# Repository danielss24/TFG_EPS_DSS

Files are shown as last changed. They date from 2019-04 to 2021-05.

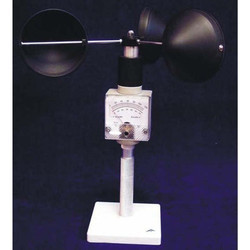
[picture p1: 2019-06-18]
Memoria/referencias anemometros/Cup Anemometer, कप एनीमोमीटर, कप एनेमोमीटर - Electro Mechanical Enterprises, Noida _ ID_ 12493118573_files/cup-anemometer-250x250.jpg

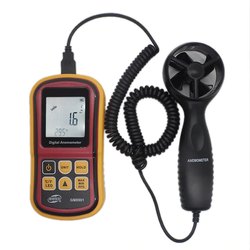
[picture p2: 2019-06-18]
Memoria/referencias anemometros/Cup Anemometer, कप एनीमोमीटर, कप एनेमोमीटर - Electro Mechanical Enterprises, Noida _ ID_ 12493118573_files/wind-measuring-instruments-250x250.jpg

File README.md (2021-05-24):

# TFG_EPS_DSS

Author: Daniel Serena Sanz

<p align="center">
  
</p>

## Resumen

Los procesos de intercambio de gases entre la tierra y la atmósfera determinan una parte importante del clima, por lo tanto es fundamental poder obtener datos fiables sobre su comportamiento y entender los mecanimos que lo determinan. Entre los diferentes factores que afectan al comportamiento de
los gases se pueden encontrar, la temperatura, la humedad, la presión y el viento. Las concentraciones
y flujos de gases fluctuan por la atmósfera debido al viento, es por esto que es importante realizar un
estudio de este parámetro.
En este trabajo de final de grado se detalla el proceso de diseño, desarrollo y construcción de
un dron como plataforma móvil para la instalación de un sensor de viento. Además, este sistema es
capaz de acoplar otros sistemas de sensorización miniaturizados, de esta manera, el dron puede incluir
sensores de viento, sensores de medición de gases, de temperatura, de presión y de humedad. La
plataforma móvil construida para esta unificación es un cuadrotor, dron con 4 motores. Se ha realizado
un estudio técnico de cada componente de forma individual para obtener un sistema optimizado en
términos de capacidad de carga útil y tiempo de vuelo. Además, ha sido necesario diseñar y producir
una serie de piezas con un programa de diseño asistido por ordenador 3D y una impresora 3D para
así acoplar los sistemas de medición necesarios y convertir finalmente el dron en un sensor. Por otro
lado para la gestión y obtención de los datos a de los sensores instalados, se ha tenido que diseñar
y codificar un software específico en python. También se ha desarrollado un algoritmo que es capaz
de obtener y analizar los parámetros de los motores convirtiendo de esta forma el dron en un sensor.
Finalmente, el sensor de viento diseñado se ha implementado en base a una unidad de medición
inercial, registrando inclinación, aceleración y orientación del sistema donde se ha instalado.
Después de construir e implementar los diferentes sistemas de administración y establecer la recopilación de datos, el sistema se probó en una prueba de campo y los resultados obtenidos muestran
un buen funcionamiento. Por medio de la representación de los datos tomados, se observa y procesa
la dirección y la velocidad del viento.

## Abstract

The gas exchange processes between the earth and the atmosphere determine an important part
of the climate. Therefore, it is essential to obtain reliable data on their behavior in order to understand
the mechanisms that determine it. Among the different factors that affect the behavior of gases are
temperature, humidity, pressure, and wind. Gas concentrations and fluxes vary in the atmosphere due
to the wind, which is why it is important to determine this parameter.
This final degree project deals with the design, development and construction of a drone as a mobile
platform for the installation of a wind sensor. Additionally the system is able to couple other miniaturized,
digitized sensors. This way the drone system can include wind sensors, gas sensors, temperature,
pressure and humidity sensors. The mobile platform for this assembling is a quadcopter, i.e. a drone
with 4 motors. A technical study of each drone component has been carried to obtain an optimized
system in terms of payload and flight time. On top of that it has been necessary to design and produce
a series of pieces using a 3D computer assistance design program and a 3D printer. In order to obtain
and to manage the data of the various sensors, it has been necessary to design and codify a specific
software in python. Furthermore, an algorithm has been developed to read-out and analyze the motor´s
operational parameters to convert the drone itself into a wind sensor. Finally, a designed wind sensor
has been implemented based on an inertial measurement unit, registering inclination, acceleration and
orientation of the system where it is installed.
After building and implementing the different management systems and establishing data collection,
the system has been tested in a field trial and the obtained results show good performance. By means
of the representation of the taken data the direction and the speed that the wind can be is observed
and processed further.

## Reusable code

Any code of this repository can be reused with the condition of indicate my name and repository on your headers.

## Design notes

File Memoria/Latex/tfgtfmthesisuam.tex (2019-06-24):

% arara: clean: {files: [tfgtfmthesisuam.aux, tfgtfmthesisuam.idx, tfgtfmthesisuam.ilg, tfgtfmthesisuam.ind, tfgtfmthesisuam.bbl, tfgtfmthesisuam.bcf, tfgtfmthesisuam.blg, tfgtfmthesisuam.run.xml, tfgtfmthesisuam.fdb_latexmk, tfgtfmthesisuam.fls, tfgtfmthesisuam.loe, tfgtfmthesisuam.lof, tfgtfmthesisuam.lol, tfgtfmthesisuam.lot, tfgtfmthesisuam.ltb, tfgtfmthesisuam.out, tfgtfmthesisuam.toc, tfgtfmthesisuam.upa, tfgtfmthesisuam.upb, tfgtfmthesisuam.acn, tfgtfmthesisuam.acr, tfgtfmthesisuam.alg, tfgtfmthesisuam.glg, tfgtfmthesisuam.glo, tfgtfmthesisuam.gls, tfgtfmthesisuam.glsdefs, tfgtfmthesisuam.idx,  tfgtfmthesisuam.ilg, tfgtfmthesisuam.xdy, tfgtfmthesisuam.loa, tfgtfmthesisuam.gnuploterrors , tfgtfmthesisuam.mw, tfgtfmthesisuam.fdb_latexmk ]}
% arara: pdflatex: {shell: yes}
% arara: makeglossaries
% arara: makeindex: {style: tfgtfmthesisuam.ist }
% !arara: bibtex
% arara: pdflatex: {shell: yes}
% arara: pdflatex: {shell: yes}
% arara: clean: {files: [tfgtfmthesisuam.aux, tfgtfmthesisuam.idx, tfgtfmthesisuam.ilg, tfgtfmthesisuam.ind, tfgtfmthesisuam.bbl, tfgtfmthesisuam.bcf, tfgtfmthesisuam.blg, tfgtfmthesisuam.run.xml, tfgtfmthesisuam.fdb_latexmk, tfgtfmthesisuam.fls, tfgtfmthesisuam.loe, tfgtfmthesisuam.lof, tfgtfmthesisuam.lol, tfgtfmthesisuam.lot, tfgtfmthesisuam.ltb, tfgtfmthesisuam.out, tfgtfmthesisuam.toc, tfgtfmthesisuam.upa, tfgtfmthesisuam.upb, tfgtfmthesisuam.acn, tfgtfmthesisuam.acr, tfgtfmthesisuam.alg, tfgtfmthesisuam.glg, tfgtfmthesisuam.glo, tfgtfmthesisuam.gls, tfgtfmthesisuam.glsdefs, tfgtfmthesisuam.idx,  tfgtfmthesisuam.ilg, tfgtfmthesisuam.xdy, tfgtfmthesisuam.loa, tfgtfmthesisuam.gnuploterrors , tfgtfmthesisuam.mw, tfgtfmthesisuam.fdb_latexmk ]}

\documentclass[epsbased,lof,loe,loc,copyright,final,printable,extendedindex,firstnumbered,tfg,gnuplot]{tfgtfmthesisuam}
% para moodle quitar printable

\usepackage{amsfonts}
\usepackage{float}
\makeglossaries

\advisor{Stefan Palzer}
\levelin{Ingeniería Informática}
\title{Diseño y construcción de un dron como plataforma de monitorización medioambiental}
%\subtitle{Si hace falta subtítulo}
\author{Daniel Serena Sanz}
\copyrightdate{20 de Junio de 2019}

\dedication{A mi familia y a mis compañeros.}

\ackfile{inicio/agradecimientos}
\resumenfile{inicio/resumen}
\abstractfile{inicio/abstract}

\keywords{Drone, quadrotor, fly, gas, platform, protocol, sensor, sensorization, system, unification, wind}
\palabrasclave{Cuadrotor, dron, gas/es, plataforma, protocolo, sensor, sensorización, sistema, unificación, viento, vuelo}

\coverdata
{
  Escuela Politécnica Superior \\
  Universidad Autónoma de Madrid \\
  C\textbackslash Francisco Tomás y Valiente nº 11
}

\bibliographyconfig{tfgtfmthesisuam}
\datadir{data}
\graphicsdir{img}
\logosdir{img}
\codesdir{codes}

\begin{document}

\chapter{Introducción\label{CAP:INTRODUCCION}}{inicio/introduccion}
\chapter{Estado del arte\label{CAP:ESTADODELARTE}}{inicio/estadodelarte}
\chapter{Sistema\label{CAP:SISTEMA}}{estructura/sistema.tex}

	\section{Dron\label{SEC:DRON}}{estructura/sistema/dron.tex}
		\subsection{Sistema de propulsión\label{SS:SISTPROPULSION}}{estructura/sistema/dron/sistemapropulsion}
		\subsection{Sistema de control\label{SS:SISTCONTROL}}{estructura/sistema/dron/sistemacontrol}
		\subsection{Mecánica\label{SS:MECANICA}}{estructura/sistema/dron/mecanica}
		
	\section{Implementación de sensores comerciales\label{SEC:SENSORVIENTO}}{estructura/sistema/sensorviento}
	
	\section{Desarrollo de sensor de viento propio\label{SEC:SENSORVIENTODRON}}{estructura/sistema/sensorvientodron}

\chapter{Pruebas y resultados\label{CAP:RESEXPYDISC}}{estructura/resultadosydiscusion}

\chapter{Conclusión\label{CAP:CONCLUSION}}{estructura/conclusion}

\appendix

\chapter{Estudio técnico de componentes para dron\label{CAP:ESTUDIOTECDRON}}{varios/estudioDron}

\chapter{Código diseñado para placa controladora}{varios/codigoPlacaContr}

\chapter{Código de registro del viento}{varios/codigoWindRegister}

\chapter{Código de gráfica de viento brújula}{varios/codigoPlotWind0}
\chapter{Código de gráfica de viento mapa de calor}{varios/codigoPlotWind1}
\chapter{Código de gráfica de viento 2D}{varios/codigoPlotWind2}
\chapter{Código de gráfica de viento 3D}{varios/codigoPlotWind3}

\end{document}

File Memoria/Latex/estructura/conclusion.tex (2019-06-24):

Para realizar el estudio de los gases que componen la atmósfera hay que tener en cuenta su comportamiento como por ejemplo, de dónde vienen y hacia dónde van. Los gases se desplazan por dos causas distintas: por difusión y por conducción, el método de difusión consiste en el desplazamiento de los gases, generalmente, en un entorno cerrado mediante el equilibrio de sus presiones parciales. Por otro lado la conducción de gases consiste en el desplazamiento de un gas por efecto de otro gas de presión menor, como por ejemplo el viento. Para medir el viento se utilizan sistemas como la veleta potenciométrica\cite{Mur2012} para medir la velocidad y dirección del viento, pudiendo diferenciar diferentes métodos de medición de velocidad de viento como: estándar o de copas, filamento caliente, empuje, compresióno tubo de Pitot, multisondas, láser, esférico y ultrasónico, descritos en el capítulo \ref{CAP:ESTADODELARTE}. No obstante, con los avances tecnológicos desarrollados en los últimos años, se pueden utilizar sensores más modernos  como las IMU, sensores que registra la orientación, inclinación y aceleración; minimizando así el tamaño del sistema y pudiendo instalarlos en una plataforma portátil.

Una vez analizados todos los diferentes sistemas de medición de viento, se ha utilizado una IMU, en este caso formada por el sensor MPU9250, que contiene a su vez el sensor MPU6050 y el AK8963, el sensor MPU6050 se encarga de la inclinación y orientación mientras que el AK8963 solo de la orientación. Se ha diseñado y codificado un software en python3 para la obtención y gestión de datos, así como para su representación de datos de forma adecuada en las gráficas del capítulo \ref{CAP:RESEXPYDISC}. Se ha instalado el sensor de viento descrito en un cuadrotor, dron de 4 motores, permitiendo así la toma de datos de forma sencilla en diferentes puntos. Para poder instalar la sensorización en el dron se ha tenido que diseñar e imprimir una serie de piezas 3D, ilustradas en la figura \ref{FIG:ACOPLDRONRASPI} (b), permitiendo de esta forma instalar tanto el sensor de viento diseñado como otros posibles tipos de sensorización, como sistemas de medición de temperatura, humedad, presión en incluso una estación meteorológica. Los datos obtenidos mediante el sensor de viento creado son bastante satisfactorios, se puede observar la desviación que produce en viento en el cuadrotor mediante las figuras: \ref{FIG:3axisforces}, \ref{FIG:scatterFit}, \ref{FIG:MAPACALOR}(a),\ref{FIG:MAPACALOR}(b), \ref{FIG:PLANOSMEDIDAS}(a), \ref{FIG:PLANOSMEDIDAS}(b) y \ref{FIG:mapa3d}.

Para proseguir con este trabajo se puede partir por desarrollar un sistema de viento más completo utilizando sensores más sofisticados o precisos como un anemómetro láser doppler o alguno de los descritos en el capítulo \ref{CAP:ESTADODELARTE}. Por otra parte, la plataforma donde se ha instalado el sensor de viento desarrollado, un cuadrotor, se puede modificar instalando otros componentes o se puede llevar a cabo una reestructuración utilizando un dron de ala fija para maximizar de esta forma el tiempo de vuelo pero sacrificando la versatilidad que ofrece un dron de ala rotatoria. Otro campo que puede implementarse es el desarrollo de un sistema de conducción autónomo agilizando la toma de datos.

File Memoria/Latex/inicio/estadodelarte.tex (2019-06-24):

\newdefinition{alaFija}{Dron de ala fija }{Dron de ala fija, se define como dron de ala fija aquel que cuenta con una o varias alas fijas en su parte superior, dotándole así de la capacidad de planear.}{Dron de ala fija, se define como dron de ala fija aquel que cuenta con una o varias alas fijas en su parte superior, dotándole así de la capacidad de planear}
\newdefinition{alaRotatoria}{Dron de ala rotatoria}{Dron de ala rotatoria, se define como dron de ala rotatoria aquel que mediante el movimiento de una o varias alas sobre un eje fijo permite volar el objeto.}{Dron de ala rotatoria, se define como dron de ala rotatoria aquel que mediante el movimiento de una o varias alas sobre un eje fijo permite volar el objeto}

Este trabajo consiste en la elaboración de una plataforma móvil sobre la que instalar un sistema de medición de viento y sobre la que se puedan unificar otros sistemas de sensorización necesarios para el estudio de la atmósfera.

Para llevar a cabo un estudio satisfactorio sobre el intercambio de gases entre la tierra y la atmósfera, se tiene que tener en cuenta como se mueven o dispersan, por conducción o por difusión respectivamente. El método de difusión consiste en la mezcla gradual de dos gases en un solo entorno, principalmente el gas con mayor presión es el que se disuelve en el segundo, equilibrando de esta forma la presión de ambos gases; por otro lado tenemos el método de conducción de gases que consiste en aplicar una fuerza de desplazamiento mediante otro gas, vease como ejemplo el accionamiento de un spray a presión. Basándonse en este último método, se debería realizar un estudio del viento en paralelo con el estudio de los gases para conocer de esta forma de dónde vienen y adónde van. 

Hay muchos estudios sobre el análisis del viento y formas de medirlo, para medir el viento contamos con dos componentes básicos: velocidad y dirección; la dirección se mide mediante el uso de una veleta\cite{Noble2019}\cite{Mur2012}, ésta es una superficie plana colocada en un eje, distribuyendo de forma equitativa su peso y permitiendo que gire libremente, la superficie plana no es igual en la parte delantera y trasera, siendo esta última de mayor tamaño y provocando que la parte pequeña o delantera indique hacia la dirección del viento, por otro lado, la velociad se mide con un anemómetro\cite{Mur2012}, podemos encontrar diferentes tipos de anemómetros como: estándar o de copas, filamento caliente, empuje, compresión o tubo de Pitot, multisondas, láser, esférico y ultrasónico.

Un anemómetro estándar o de copas\cite{cupAnemo}, ilustrado en la figura \ref{FIG:ANEMOMETROS} (a), precisa de una calibración previa para obtener unos datos fiables, su rotación se va registrando mediante un contador y mediante una conversión se obtiene la velocidad del viento por tantas vueltas dadas; por otro lado el anemómetro de filamento caliente\cite{hotWireInfoWeb}\cite{hotWireAnem}, ilustrado en la figura \ref{FIG:ANEMOMETROS} (g), funciona mediante la elevación de la temperatura de un hilo de platino o níquel. El movimiento del aire o viento produce que dicho hilo reduzca su temperatura variando a su vez la corriente que pasa por él, de esta forma obtenemos de forma proporcional la velocidad del viento. El anemómetro de empuje\cite{emujeAnem}, ilustrado en la figura \ref{FIG:ANEMOMETROS} (h), es muy poco preciso, su funcionamiento se limita a empujar un cubo hueco colgado a forma de péndulo, se mide la velocidad del viento en función de su suspensión respecto a su estado de reposo. A continuación existe el anemómetro de compresión o tubo de Pitot\cite{Extech}\cite{emujeAnem}, ilustrado en la figura \ref{FIG:ANEMOMETROS} (d), está formado por 2 tubos, uno de ellos con un orificio frontal y el segundo con un orificio lateral, la diferencia de presión medida entre ambos tubos indica la velocidad del viento. El anemómetro multisondas\cite{NASA}\cite{Anemometer2009}, ilustrado en la figura \ref{FIG:ANEMOMETROS} (b), utiliza el mismo principio que el anemómetro de compresión pero contando con 5 orificios y extendiendo el sistema de medición de viento a 3 dimensiones, este sistema es utilizado para aeromodelos como el UAV SUMO. El anemómetro esférico\cite{Holling2007}, ilustrado en la figura \ref{FIG:ANEMOMETROS} (c), utiliza una sistema con una esfera para incidir con un láser, la desviación que sufre el láser indica de forma proporcional la velocidad del viento. El anemómetro láser doppler\cite{Tropea1995}\cite{lasercantilver}\cite{durst1980principles}\cite{albrecht2013laser}, ilustrado en la figura \ref{FIG:ANEMOMETROS} (f), consta de dos haces de luz que inciden sobre una lente reflejante creando de esta forma una franja de medida conocida, cuando una partícula pasa por esta franja emitirá pulsos de luz, por otro lado un fotodiodo es capaz de captar dichos pulsos obteniendo de esta forma la velocidad de dicha partícula. Por último cabe mencionar el sensor ultrasónico\cite{Prudden2016}\cite{Mur2012}, ilustrado en la figura \ref{FIG:ANEMOMETROS} (e), este último tipo de anemómetro requiere de menos mantenimiento ya que no tiene piezas en movimiento, no obstante tiene un gran consumo eléctrico para su funcionamiento. Éste mide el tiempo requerido por el sonido para atravesar un campo conocido 10-30cm, estos anemómetros son muy precisos pero presentan problemas a la hora de medir el viento con lluvia.

\begin{figure}[Tipos de anemómetros]{FIG:ANEMOMETROS}{Tipos de anemómetros. Ordenados segun figura: estándar o de copas, multisondas, esférico, filamento caliente, ultrasónico, láser doppler, compresión o tubo de Pitot y empuje}
	\image{0.8\textwidth}{}{tiposanemometros}
\end{figure}

A todos estos tipos de anemómetros se pueden añadir los sensores como las IMU, unidad de medición inercial. Estos sensores registran la aceleración, la inclinación y la orientación del sistema donde esten instalados, mediante el desarrollo de un software específico, este sensor es capaz de aportar la fuerza del viento y su dirección, en funcion de la fuerza que se aplique al sistema y su orientación respectivamente. La ventaja de la utilización de estos sensores se encuentra en su precisión y su tamaño, pudiendolo instalar en sistemas miniaturizados.

Por otro lado, la plataforma donde se pretende unificar todo el sistema de sensorización es un cuadrotor o dron de 4 motores, estas máquinas se pueden definir como UAV (Unmaned Aerial Vehicle) o vehículo aéreo no tripulado. Su utilización hoy en día se ha incrementado por su versatilidad, facilidad, seguridad y rapidez; facilidad de alcance donde el ser humano no puede llegar de forma natural, seguridad evitando la presencia del ser humano en un entorno peligroso y rapidez de respuesta en determinadas ocasiones. Debido al gran interés por los drones\cite{hiltner2013drones}, se ha incrementado su diseño y contrucción ofreciendo diferentes modelos y componentes. Se pueden diferenciar dos grandes grupos: drones de ala fija\footnote{\dfnpl{alaFija}} y de ala rotatoria\footnote{\dfnpl{alaRotatoria}}. 

Los drones de ala fija destacan por su gran autonomía y su utilidad para el mapeo de superficies, no obstante no poseen de un tren de aterrizaje por lo que este tipo de dron precisa de una catapulta o persona que lo lance para poder despegar, se utiliza principalmente para labores de agricultura o fotogrametría\cite{Pozuelo2003}. Por otro lado existen los drones con ala rotatoria, estos drones son los más conocidos y más utilizados por su versatilidad al poder instalar complementos, ya sean cámaras o elementos de medición, y por su facilidad de pilotaje, sobre todo en el momento de despegar y aterrizar, ya que este modelo permite su despegue en vertical. Existen drones de ala rotatoria tricópteros, cuadrocópteros, hexacópteros u octacópteros, cada uno de ellos con 3, 4, 6 u 8 motores respectivamente. La autonomía de estos drones es muy limitada, teniendo 10 minutos a 1 hora aproximadamente frente a los drones de ala fija que fácilmente superan la hora de autonomía.

Hay numerosos estudios que emplean drones como sistema de medición, entre ellos se pueden encontrar los drones para medición de viento\cite{Prudden2016}\cite{hardin2011small}\cite{MoyanoCano2013}, cabe diferenciar varios modelos: SUMO, MMAV, MASC y Vario XLC; SUMO, Small Unmaned Meteorological Obsever\cite{Reuder2009}, es una plataforma diseñada por la Universidad de Berge, Noruega, que cuenta con un sistema de medición de temperatura, humedad y presión. Toma medidas del viento mediante el movimiento de sus hélices, junto con un sensor de GPS, mide la velocidad respecto de la tierra y determina a su vez la velocidad según el cabeceo del modelo, en caso de cabecear desde la parte frontal se ve acelerado y junto con la diferencia de velocidad respecto del suelo se obtiene la velocidad horizontal y su dirección. MMAV, Meteorological Mini Unmaned Vehicle\cite{BuschmannMarcoandBangeJensandVorsmann2019}, es un mini-dron diseñado por Mavionics GmbH en colaboración con la Universidad de Brunswick, Alemania. Este dron mide la velociadad del viento mediante el uso de un anemómetro de compresión con 5 orificios junto con un sistema de GPS y de medición inercial o IMU. MASC, Multi-purpose Automatic Sensor Carrier\cite{Wildmann2014}, es un dron de ala fija que opera automáticamente y toma medidas de flujo, calor y temperatura durante su vuelo a velocidad constante y con altura variable, cuenta con un sistema meteorológico similar al MMAV. Vario XLC\cite{Xiang2016}, es una plataforma basada en un helicóptero a escala reducida que es capaz de levantar un peso máximo de 17 Kg, en este caso lleva instalado un anemómetro ultrasónico 3D.

Una vez descritos los sistemas de medición de viento y su posibilidad de instalación en una plataforma móvil como es un dron, se puede  desarrollar un sistema acorde a las necesidades del proyecto miniaturizándose e instalándose en un cuadrotor.

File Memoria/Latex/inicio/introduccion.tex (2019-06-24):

\newacronym{o2}{O2}{Oxígeno}
\newacronym{n2}{N2}{Nitrógeno}
\newacronym{co2}{CO$_2$}{Dióxido de Carbono}
\newacronym{ar}{Ar}{Argón}
\newacronym{uv}{UV}{Ultra Violeta}
\newacronym{ozono}{O3}{Ozono}
\newacronym{gei}{GEI}{Gases de Efecto Invernadero}
\newacronym{ppm}{ppm}{Parts Per Million}
\newacronym{imu}{IMU}{Inercial Measure Unity}
\newacronym{cad}{CAD}{Computer Assisted Design}

Los niveles de concentración de \ac{co2} en la amtósfera han aumentado considerablemente en los últimos 20 años. Antes de la llegada de la industrialización, los niveles de CO$_2$ producidos y consumidos por la superficie terrestre y los océanos estaban compensados, sin embargo estos se han incrementado, llegando a unos niveles de presión de 410 \ac{ppm} respecto a los 280 ppm existentes antes de la industrialización\cite{Hansen1998}\cite{co2atmo}. Los niveles de emisión de CO$_2$ por la tierra superan enormemente al nivel emitido por los humanos. Para poder estudiar estas emisiones de gases hay que tener en cuenta qué factores afectan a su comportamiento, siendo los más significantes la humedad, la temperatura, la presión y el viento entre otros. Este último, además, es el principal motivo de su desplazamiento.

%\paragraph{Motivación}
Este TFG tiene como objetivo el desarrollo, diseño y utilización de una plataforma móvil que cuenta con un sistema de medición de viento y donde se pueda instalar un sistema de medición de gases miniaturizados. Favoreciendo, de esta forma, una toma rápida y fiable de datos. 

\begin{figure}[Medición de viento con drones]{FIG:INIFIG}{Medición de viento con drones. Sistema capaz de tomar datos en 3D y a tiempo real mediante la utilización de un dron como sensor de viento. (Iconos obtenidos de: svgsilh.com y www.shareicon.net)}
	\image{1\textwidth}{}{introImg}
\end{figure}

Se ha realizado un estudio  sobre los diferentes métodos de medición del viento y los posibles drones para usarlo como plataforma móvil donde instalar este sistema de medición funcional.

Existen diferentes métodos para medir el viento, el más común es la veleta potenciométrica, cuyo anemómetro puede ser esférico, de hilo térmico, ultrasónico o de tipo láser doppler entre otros. Por otro lado existen sensores \ac{imu}, que mediante el desarrollo de un software específico para el tratamiento de datos como: orientación, inclinación y aceleración, obtiene la velocidad y dirección del viento. Como plataforma móvil se ha estudiado la utilización de un dron teniendo en cuenta los dos grandes grupos existentes, ala fija y ala rotatoria. Los drones con ala fija presentan una mayor autonomía frente a los de ala rotatoria que por otro lado cuentan con mayor versatilidad.

%\paragraph{Objetivos}
El objetivo de este trabajo es la creación de un cuadrocoptero, dron con ala rotatoria, como plataforma móvil donde instalar un sistema de medición de viento. La aplicación de uso se muestra en la figura \ref{FIG:INIFIG}. Se ha decidido construir un dron por partes realizando un estudio ténico previo, indicado en el apéndice \ref{CAP:ESTUDIOTECDRON}, e instalar un sistema de viento aplicando una IMU para su medición. Para poder unificar los dos componentes, se han tenido que crear diferentes piezas 3D diseñadas en un programa \ac{cad}, permitiendo ,de esta forma, instalar cualquier otro sistema de sensorización miniaturizado en caso de ser necesario.

%\paragraph{Organización de la memoria}
Este trabajo está organizado en diferentes capítulos. En primer lugar, en el capítulo \ref{CAP:SISTEMA}, se explica el funcionamiento de los drones y sus componentes indispensables; continuando con la aplicación de los sensores comerciales actuales para la medición del viento y finalizando con el desarrollo de un sensor de viento propio unido a un dron. Se ha creado, por tanto, un sistema de medición de viento portátil. En el capítulo \ref{CAP:RESEXPYDISC} se muestran las diferentes pruebas realizadas en función de su escenario. Se puede observar el comportamiento del dron y de sus mediciones representándolos en unas gráficas como: un mapa de calor y un mapa de viento 2D y 3D. En el capítulo \ref{CAP:CONCLUSION} se resume la evolución de este trabajo sobre la utilización de drones como plataforma para un sistema de medición de viento como unidad básica del estudio de gases. En los anexos quedan reflejados el estudio técnico del dron desarrollado, el código diseñado e implementado para la toma y conversión de datos, y el algoritmo de gestión de estabilización.

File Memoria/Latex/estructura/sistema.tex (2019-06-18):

Una vez realizado el estudio de los diferentes tipos de sensores de viento y drones utilizados como sensor de viento descritos en el capítulo \ref{CAP:ESTADODELARTE}, se explicará cómo realizar el estudio del viento y cómo diseñar una plataforma sobre la que se puedan unificar distintos sistemas de medición. Se tratarán los drones y sus componentes, posteriormente se describirán los sistemas de viento y se implementará mediante una IMU, finalizando con un sistema portátil de medición del viento.

Debido al gran tamaño y coste de los drones industriales, se ha decidido diseñar uno propio más pequeño y barato y posteriomente añadiéndole las modificaciones oportunas para incorporar el sistema de sensorización necesario. El dron estará diseñado para la incorporación de un microsistema de medición de gases junto con un sensor de viento.

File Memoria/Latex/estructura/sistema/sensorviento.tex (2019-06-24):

 Actualmente los sensores de viento habituales cuentan con dos elementos básicos: el anemómetro y la veleta, el primero se encarga de medir la velocidad del viento y un tipo de anemómetro, hilo caliente, consiste en un hilo de platino que se calienta eléctricamente; la acción del viento produce la disminución de su temperatura variando así su resistencia y provocando que la corriente que atraviesa dicho hilo se altere y nos indique de forma proporcional la velociad del viento\cite{Tropea1995}, y el segundo elemento básico, la veleta, indica la dirección del viento; esta es una superficie plana colocada en un eje, distribuyendo de forma equitativa su peso y permitiendo que gire libremente, la superficie plana no es igual en la parte delantera y trasera, siendo esta última de mayor tamaño y  provocando que la parte pequeña o delantera indique hacia la dirección del viento\cite{Noble2019}. Estos dos elementos pueden encontrarse montados de forma separada o conjuntamente denominándose veleta potenciométrica\cite{Mur2012}.
 Este sistema de medición es muy preciso pero tiene un coste elevado. Necesita de una instalación en una localización fija, que además de precisar una altura mínima debe estar libre de obstáculos para poder realizar las medidas correctamente.
 
 %En nuestra vida diaria utilizamos desde dispositivos electrónicos hasta medios de transporte que incluyen sensores que miden su inclinación, aceleración y dirección, se puede ver como ejemplo un teléfono móvil, un coche o incluso un avión.
 Actualmente existen sensores que se utilizan en la estabilización de un avión, el registro del movimiento de un coche o incluso en aplicaciones móviles.
 
 En esta sección se explicará como utilizar un sensor de aceleración, giroscopio y magnetómetro.
 
 Para realizar este experimento se ha utilizado el sensor MPU9250\footnote{Datasheet: InvenSense, ``{MPU9250 Product Specification Revision 1.1},'' 2016. (Fecha de acceso: 2019-06-12)}, ilustrado en la figura \ref{FIG:IMUAXES}(a),que a su vez tiene integrado otros dos sensores el MPU6050, que se encarga de la aceleración y el giroscopio, y el AK8963 que gestiona el magnetómetro, componiendo de esta forma un microchip que mide la alteración de su posición en función de 3 ejes.
 
 Los datos obtenidos por el sensor MPU6050\footnote{Datasheet: InvenSense, ``{MPU6050 Product Specification Revision 3.3},'' 2012. (Fecha de acceso: 2019-06-12)} son datos sin tratar, que indican la aceleración en el instante de la medición y la inclinación respecto de la anterior medida tomada, mientras que el sensor AK8963\footnote{Datasheet: InvenSense, ``{MPU9250-AK8963 Product Specification Revision 1.1},'' 2016. (Fecha de acceso: 2019-06-12)} indica la orientación.

\begin{figure}[IMU con ejes de medición]{FIG:IMUAXES}{Sensor MPU9250 con ejes de funcionamiento. Figura \ref{FIG:IMUAXES} (a) muestra el sensor físico mientras que la figura \ref{FIG:IMUAXES} (b) muestra la diferencia entre los ejes de medición conjuntamente del giroscopio y acelerómetro y del magnetómetro, figura (c), muestra unos ejes distintos.}
	\image{1\textwidth}{}{IMUAXES}
\end{figure}
 
 Para poder saber claramente en que posición se encuentra el microchip con respecto a una superficie plana y no a su inclinación en relación a la anterior medida, se ha implementado el algoritmo de madgwick\cite{Act2012} que utiliza cuaterniones para indicar la inclinación absoluta en función de los ejes de la tierra. 
 
 Los cuaterniones\cite{Graves1999} son un conjunto de cuatro componentes complejos que sirven para la teoría de números, rotaciones en el espacio y para diseño de gráficos; en este caso se utilizarán para las rotaciones en el espacio. Los cuaterniones se pueden expresar como en la ecuación \ref{EQ:CuaternionFormula}.
 
\begin{equation}[EQ:CuaternionFormula]{Expresión de cuaterniones}
	{\mathbb{H}= \{ {a+bi+cj+dk:a,b,c,d\:\epsilon\:\mathbb{R}} \} \subset  \mathbb{C}^{2}}
	\end{equation}
	
	Fórmula de cuaternion \ref{EQ:CuaternionFormula} de 4 dimensiones. a, b, c, d son las componentes reales del cuaternion; i, j, k  son los componentes que multiplican cada una de las componentes reales.

   Mediante el algoritmo de madgwick, se convierten los datos obtenidos desde el giroscopio, acelerómetro y magnetómetro en un componente de 3 elementos, yaw, pitch y roll, proceso ilustrado en la figura \ref{FIG:YAWPITCHROLLPLANE}.
   Cada uno de estos elementos nos indica su rotación respecto a un eje del aeromodelo. 

\begin{figure}[Ejes yaw, pitch y roll]{FIG:YAWPITCHROLLPLANE}{Se recogen los datos del sensor MPU9250, magnetómetro, giroscopio y acelerómetro y los tratamos mediante el algoritmo de madgwick. Convierte las medidas y los convierte en los ejes de giro, yaw, pitch y roll.}
	\image{\textwidth}{}{yawpitchrollplane}
\end{figure}
 
 Mediante la utilización de estas rotaciones en función de sus ejes se puede determinar como hay que actuar en los motores para que se mantenga volando de forma estable y horizontal.

 En este punto se cuenta con la inclinación del sensor en base a los ejes de la tierra, su aceleración y su dirección en grados; con este conjunto de datos podemos calcular la variación de su posición en función de un punto inicial.
   
  Para calcular el viento se ha planteado un sistema que toma como eje el centro de la tierra; de esta forma si el sensor está orientado al norte y se inclina hacia delante se obtiene una dirección de viento de sur a norte, y en caso de inclinarse hacia delante y a izquierda, se obtiene un viento de sur-este. La fuerza del viento viene indicado directamente por los datos obtenidos del acelerómetro en función de los tres ejes.

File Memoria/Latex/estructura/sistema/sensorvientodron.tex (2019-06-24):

En esta sección se describirá la unificación el sensor de viento con el dron y qué es necesario para que todo funcione como un único sistema.
Para poder llevar a cabo esta unión se ha de tener en cuenta el peso del sistema de viento, la Raspberry y el sistema de sensorización, junto con el peso del dron para hacer una estimación media de la duración de vuelo.

A continuación se explicará los tres pasos que he llevado a cabo: en primer lugar desde donde empiezo, seguido de como junto todos los sistemas y finalizando con como funciona todo el conjunto.

%\paragraph{Uniendo sistemas}
%\begin{description}
%\item[Desde donde parto]
Para poder diseñar un sensor de viento que funcione con un dron primero hay que estudiar que sistema de estabilización usa el dron, se puede diferenciar entre dos sistemas principales. Un primer sistema realiza una estabilización del dron que registra la desviación de su posición desde un punto y lo corrige para mantenerse siempre en ese mismo punto. El segundo sistema de estabilización intenta que el dron no se caiga, modificando la potencia de los motores acorde con la fuerza que se ejerce sobre el, de esta forma consigue que el dron esté los más horizontal posible.

En este caso, se usa un placa comercial que funciona como el segundo sistema descrito y por tanto se usa un giroscopio para poder medir las diferentes inclinaciones y fuerzas que sufre el dron. En el caso de utilizar el primer sistema se debería usar una medición de la potencia suministrada a los motores para ver que potencia se esta ejerciendo para contrarrestar la fuerza que se ejerce sobre él.

Por otro lado se cuenta con un chasis base de un dron de 220 mm entre ejes donde es necesario montar un soporte para instalar nuestro ordenador o unidad de procesamiento, en este caso una Raspberry Pi 3 B+, y nuestro sistema de sensorización.

%\item[Como lo junto]
Para poder unir los dos sistemas y realizar medidas en vuelo, se ha tenido que aprender a utilizar un software específico para diseñar una serie de piezas 3D y así poder acoplar la sensorización al dron.

\begin{figure}[Antes y después de adapatacion raspberry-dron]{FIG:ACOPLDRONRASPI}{En la subfigura a) se puede observar los sistemas de forma independiente a unificar. En la subfigura b) se presentan las piezas diseñadas e impresas en 3D para poder acoplar sistemas de medición al dron. En la subfigura c) se observa el sistema de medición instalado en el dron construido.}
	\image{15cm}{}{acoplamientosDron}
\end{figure}

Entre las piezas de impresión se cuenta con:
\begin{description}
\item[Soporte Raspberry Pi]
Para el soporte de la Raspberry Pi 3 B+, se ha diseñado una pieza que se acopla en la parte inferior del chasis del dron. 

%\begin{figure}[Chasis raspberry dron]{FIG:CHASISRASPIDRON}{Soporte Raspberry dron.}
%	\image{4cm}{}{ChasisRaspberryDron}
%\end{figure}

\item[Zona de sensorización: ]

Una vez instalado el soporte de la Raspberry, se ha diseñado una tapa intermedia donde se puede instalar el sistema de sensorización necesario. 
Esta zona esta diseñada con suficiente espacio para poder instalar además del sensor base diseñado, sensor de viento, otros sensores como por ejemplo un sensor de gas con sus componentes necesarios.

%\begin{figure}[Zona sensorización dron]{FIG:ZONASENSORIZACION}{Zona de sensorización. Tapa intermedia \ref{SBFIG:TAPAINTERMEDIA} acoplada al soporte de la raspberry \ref{FIG:CHASISRASPIDRON} y a ella se ancla la tapa \ref{SBFIG:TAPACHASISDRON} para cerrar nuestro modelo.}
%	
%  \subfigure[SBFIG:TAPAINTERMEDIA]{Tapa intermedia dron}{\image{4cm}{}{TapaIntermediaDron}} \quad
%  \subfigure[SBFIG:TAPACHASISDRON]{Tapa chasis dron}{\image{4cm}{}{TapaChasisDron2}}
%  
%\end{figure} 

Al diseñar las piezas de forma independiente se puede modificar, en caso de necesidad, la tapa del chasis del dron y crear otra forma o ampliar el espacio respetando el acoplamiento a la tapa intermedia.

\item[Elementos de aterrizaje]

Una vez instaladas las anteriores piezas, se ha prolongado el dron por su parte inferior un total de 6 cm y por ello es necesario instalar un tren de aterrizaje.

%\begin{figure}[Pata dron]{FIG:PATADRON}{Diseño de pata del dron del tren de aterrizaje.}
%	\image{4cm}{}{PataDron}
%\end{figure}
\end{description}

Para el tren de aterrizaje se ha probado a instalar un total de 4 patas, una por cada motor. Por problemas de estabilidad se eliminó una de ellas, distribuyendo 2 de las patas en los motores traseros y la tercera en la parte delantera-media del dron. Con 3 patas se asegura aterrizar el dron correctamente en una superficie plana.

%\item[Funcionando conjuntamente]

Una vez se ha unido todo como un solo sistema, dron y sensorización junto con la raspberry, se procederá a realizar las mediciones con el dron volando.

Para tomar las medidas correctamente con el dron se tiene que mantener volando, los datos se obtienen a partir de la variación de su posición en cuanto a inclinación que sufre por fuerzas como el viento.
Para la realización de esta prueba se cuenta con los cálculos de vuelo previamente hechos sobre un dron con un peso máximo de 900 gramos y con una batería de 3 celdas y 1500 mAh de capacidad. El único manejo que se debe hacer con el dron en el momento de medir es modificar su altura ya que no tiene un sistema automático de mantenimiento de distancia respecto del suelo.

%\begin{figure}[Foto del dron con sensorización de viento]{FIG:DRONCOMPLETOSENSO}{Dron con sistema de medición de viento incorporado. Consta de las piezas diseñadas e impresas con una impresora 3D para poder instalar sistemas de sensorización miniaturizados.}
%	\image{0.8\textwidth}{}{dronCompleto2}
%\end{figure}

%\end{description}

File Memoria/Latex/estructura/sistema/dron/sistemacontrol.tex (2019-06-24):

\newdefinition{i2c}{Comunicación I2C}{I2C, es un protocolo de comunicación que cuenta con 2 cables: uno de ellos (SCL) indica los pulsos de reloj y el otro (SDA) se encarga de transportar los datos. Al contar con un único cable de datos y ser capaz de comunicar dos o más dispositivo es necesario un maestro que se encargue de mediar la comunicación.}{I2C, es un protocolo de comunicación que cuenta con 2 cables: uno de ellos (SCL) indica los pulsos de reloj y el otro (SDA) se encarga de transportar los datos. Al contar con un único cable de datos y ser capaz de comunicar dos o más dispositivo es necesario un maestro que se encargue de mediar la comunicación\cite{Leens2009}}
\newdefinition{spi}{Comunicación SPI}{SPI, es un protocolo de comunicación usado habitualmente para la transferencia de datos entre equipos electrónicos. Formado por un total de 4 conexiones: CLK o reloj de sincronizaciñon, envío de datos, recepción de datos y un Enable que permite recibir datos en caso de estar activo o negarlos en caso de estar inactivo, de esta forma se puede utilizar el SPI para comunicarse con varios sensores utilizando multiplexación mediante el pin de enable\cite{Leens2009}.}{SPI, es un protocolo de comunicación usado habitualmente para la transferencia de datos entre equipos electrónicos. Formado por un total de 4 conexiones: CLK o reloj de sincronizaciñon, envío de datos, recepción de datos y un Enable que permite recibir datos en caso de estar activo o negarlos en caso de estar inactivo, de esta forma se puede utilizar el SPI para comunicarse con varios sensores utilizando multiplexación mediante el pin de enable\cite{Leens2009}}
\newdefinition{pSerie}{Comunicación Puerto Serie}{Puerto serie, es un protocolo de comunicación digital que aplica la serialización, conversión de los datos a nivel de byte a una serie de pulsos para que puedan ser enviados y recibidos, existen diferentes tipos: UART usado por la Raspberry, USART, EUART.}{Puerto serie, es un protocolo de comunicación digital que aplica la serialización, conversión de los datos a nivel de byte a una serie de pulsos para que puedan ser enviados y recibidos, existen diferentes tipos: UART usado por la Raspberry, USART, EUART}

\paragraph{Placa distribuidora de potencia}\label{SSS:PlacaDistribuidora}

\newacronym{pdb}{PDB}{Pluggable Database}
Un punto crucial de los componentes electrónicos es su alimentación, para favorecer la durabilidad y estabilidad del circuito o circuitos electrónicos se debe aislar el circuito de potencia del circuito lógico mediante elementos como los que contiene la \ac{pdb}: diodos, resistencias y transistores los cuales evitan picos de tensión.

%\begin{figure}[Placa distribuidora de potencia]{FIG:PDBDRON}{Placa distribuidora de potencia con conector XT60.}
%	\image{4cm}{}{pdbDron}
%\end{figure}

Esta placa, ilustrada en la figura 3.1 (6), está conectada a la batería mediante un conector, en este caso se cuenta con un conector XT60, el cual impide conectar cada polo con su opuesto debido a su forma, evitando así cortocircuitos y daños al sistema.
Por otro lado, la PDB distribuye la tensión necesaria al resto de los componentes, entre los que se destacan:

\begin{description}
        \item[ESC:] Hasta un total de 6 controladores de velocidad, en este caso son 4 ESC que funcionan con baterías de 2 a 4 celdas y por tanto de 6 a 16 voltios.
        \item [Circuito 5V:] Circuito de 5 voltios de tensión con un sistema de BEC para evitar picos y conseguir un circuito con alimentación continua y estable, con una corriente continua de 2 amperios y una corriente máxima de 2'5 amperios.
        \item [Circuito 12V:] Circuito de 12 voltios de tensión, con el mismo funcionamiento que el circuito a 5 voltios, con una corriente continua de 500 mA y máxima de 0'8 amperios.
\end{description}

\paragraph{Controlador de vuelo}
\label{SSS:Controlador de vuelo}
%\subsubsection*{Controlador de vuelo\label{SS:CONTROLADORVUELO}}{estructura/sistema/dron/controladorvuelo}

	La placa controladora de vuelo es la unidad de procesamiento del dron encargada de gestionar la señales provenientes del receptor, leer los parámetros de los diferentes sistemas de estabilización y su posterior modificación para proporcionar la potencia adecuada a cada motor.
\paragraph{Placa comercial}
\label{SSSS:Placa comercial}
	La elección de la controladora de vuelo viene determinada sólamente por el protocolo de comunicación que utilice, aunque a día de hoy la mayoría de controladoras cuentan con software reprogramable que se ajusta a los diferentes sistemas de comunicación, como los más conocidos iBUS o sBUS.
	
%	\begin{figure}[Controladora de dron]{FIG:CONTROLADORADRON}{Placa controladora mateksys.}
%	\image{4cm}{}{controladoraDron}
%\end{figure}

	En la controladora de vuelo, ilustrada en la figura 3.1 (7), se pueden conectar el sistema de comunicación, sistema de vídeo, controladores de velocidad de los motores, bocina de emergencia y la antena de comunicación de largo alcance.

%https://www.banggood.com/Matek-F405-OSD-BetaFlight-STM32F405-Flight-Controller-Built-in-OSD-Inverter-for-RC-Multirotor-FPV-Racing-Drone-p-1141282.html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

\paragraph{Placa desarrollada}
\label{SSSS:Placa desarrollada}
	\newacronym{tfg}{TFG}{Trabajo final de grado}
En este \ac{tfg} se ha reproducido el sistema de control del dron en una Raspberry Pi 3 B+\cite{raspberryPi}, con el fin de unificar todos los controles en un sólo punto y poder utilizar todas las señales entrantes y salientes para mediciones posteriores.

Para representar el sistema de la controladora de vuelo se ha partido del sistema de descifrado del protocolo de comunicación elegido, iBUS, este protocolo manda paquetes de información a través del puerto serie. La raspberry cuenta con dos pines de comunicación por puerto serie: Rx para recibir la información y Tx para transmitirla.
	
El paquete recibido tiene un tamaño total de 31 bytes, con un byte inicial estándar con contenido igual a 0x55, a continuación encontramos un total de 14 canales con 2 bytes por canal y un checksum al final con un tamaño de 1 byte. El paquete se transmite cada 7 ms con una tasa de baudios de 115200, es decir, un total de 115200 bits por segundo.
Para desglosar el paquete recibido, enviado por el mando, se ha tenido que codificar un algoritmo en python donde se diferencia y se convierte cada uno de los bytes a decimal, obteniendo de esta forma un valor de cada canal entre 1000 y 2000, siendo 1000 el valor mínimo y 2000 el máximo valor posible.

Para poder producir el PWM correcto y enviárselo a los controladores de velocidad, se ha escogido el chip PCA9685 que convierte de digital a PWM y tiene hasta un máximo de 8 canales. Ha sido necesario dicho chip ya que la raspberry no cuenta con el número suficiente de canales para controlar los 4 motores.
La Raspberry cuenta con 3 sistemas de comunicación: I2C\footnote{\dfnpl{i2c}}, SPI\footnote{\dfnpl{spi}} y puerto \footnote{\dfnpl{pSerie}}, para la configuración del chip PCA9685 se ha realizado mediante comunicación por I2C y su respectiva librería de adafruit obtenida por github\cite{Industries}. 

Se ha tenido que indicar desde la raspberry la frecuencia de salida de los PWM, 2000 Hz , y el ciclo de trabajo previamente obtenido por nuestro rango de entrada entre 1000 y 2000.
\paragraph{Funcionamiento de algoritmo codificado}
La Raspberry recibe el paquete de bytes y lo transforma mediante el algoritmo diseñado y codificado en valores entre 1000 y 2000 por cada canal. Por otro lado se usa la librería de Adafruit para el chip PCA9685, pasándole el rango calculado y configurando el PWM a generar a 2KHz de frecuencia.

%\begin{subequations}
%    \begin{equation}[EQ:PQTEntrante]{Paquete 31 bytes entrante}
%		\boxed{55,DD05,DC05,EB03,DC05,E803,D007,D205,D905,E803...}
%		%55 DD05 DC05 EB03 DC05 E803 D007 D205 D905 E803 E803 DC05 DC05 DC05 DC05 234C
%	\end{equation}
%	\begin{equation}[EQ:PQTDescifrado]{Señal descifrada}
%		\boxed{input=[1501,  1500,  1003,  1500,  1000,  2000,  1490,  1497,  1000,  1000,  1500,  1500,  1500,  1500]}
%	\end{equation}
%	\begin{equation}[EQ:EQRango]{Ecuación de obtención de rango}
%			\boxed{rango = 3296 - (input - 1000) * \frac{(3296-2498)}{1000}}
%	\end{equation}
%	\begin{equation}[EQ:EQFuncion]{Función de adafruit, generación de pwm en PCA9685}
%			\boxed{pwm.set_pwm(canal, rangoMinimo, 4095)}
%	\end{equation}
%\end{subequations}

\begin{figure}[Diagrama placa controladora desarrollada]{FIG:DIAGRAMAPLACACONTROLADOR}{Diagrama de placa controladora a alto y bajo nivel. El receptor recibe la señal del mando, que se transmite a la raspberry y que realiza la conversión necesaria para general el PWM correcto utilizando el chip PCA9685 a los 4 canales necesarios, uno para cada esc-motor.}
	\image{1\textwidth}{}{diagramaPlacaControladora2}
\end{figure}

En la figura \ref{FIG:DIAGRAMAPLACACONTROLADOR} se pueden observar dos imágenes, a y b, en la imágen b se muestra a alto nivel como funciona el sistema de gestión de la placa controladora diseñada, mientras que en la imágen a se muestra a bajo nivel el proceso y conversión de los datos desde el receptor hasta los PWM mandados a los motores.

Una vez conseguida la señal de salida PWM en función de la entrada del mando, se modifica la señal a partir de los datos obtenidos por el sensor MPU9250, el cual nos indica la inclinación y fuerzas que se ejercen sobre el dron; de esta forma se mandama la potencia adecuada a cada motor para conseguir un vuelo estable y horizontal. Posteriormente se realizó la estructura del programa para la obtención de la potencia de los motores para poder medir el viento a partir de ellos, convirtiendo de esta forma el dron en un propio sensor de viento, no obstante, debido a las dificultades de probar el sistema de estabilización y su ajuste, se decidió trabajar con la placa comercial.

\paragraph{Sistema de comunicación}

	El sistema de comunicación está compuesto por dos componentes, receptor y transmisor, 3.1 (1) y 3.1 (3), y se pueden elegir diferentes tipos teniendo en cuenta su protocolo de comunicación. 
	
	El sistema de comunicación tiene diferentes protocolos para transmitir la información, utiliza un protocolo entre emisor y receptor y otro distinto entre receptor y unidad de procesamiento o controladora de vuelo\cite{Eric2017}.
	
%	\begin{figure}[Mando FlySky dron]{FIG:MANDODRON}{Mando FlySky para dron.}
%	\image{4cm}{}{mandoDron}
%\end{figure}	
	
	El protocolo de comunicación entre emisor y receptor tiene que ser siempre igual, es por eso que la mayoría de mandos, emisores, incluyen un receptor estándar. En este caso se ha utilizado un pack FlySky emisor-receptor.
	
	\newacronym{ppm}{PPM}{Parts per million}
	En el caso del protocolo entre el receptor y la unidad de procesamiento podemos encontrar señales PWM, PPM, SBUS, iBus entre otras. La diferencia entre estos protocolos es la forma de estructurar el paquete de datos o la conexión que hay que realizar a nivel de hardware. Por su simplicidad y comodidad se ha utilizado el protocolo iBus que cuenta con un paquete de transmisión de 31 bytes.

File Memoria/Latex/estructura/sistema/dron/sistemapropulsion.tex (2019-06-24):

\paragraph{Motores}
\label{SSS:Motores}
%\subsubsection*{Motores\label{SS:MOTORES}}{estructura/sistema/dron/motores}

Los motores son una parte fundamental del dron ya que han de proporcionar la potencia suficiente para hacer girar la hélices y, por consiguiente, hacer volar el dron. 
                
 Se han considerado varios parámetros como por ejemplo, la potencia, el consumo y la fuerza máxima de empuje. 
 \newacronym{cw}{CW}{ClockWise}
 \newacronym{ccw}{CCW}{Counter ClockWise}
 Los motores se clasifican según su velocidad indicándose en KV, revoluciones por minuto por voltio y su dirección de giro, que se distingue entre \ac{cw} y \ac{ccw}. No es posible tener todos los motores con el mismo sentido de giro ya que se produciría un efecto de vórtice, es decir, haciendo girar el dron sobre si mismo y sin ningún control. \linebreak Así mismo se pueden diferenciar dos clases de motores: con escobillas o sin ellas, este factor afecta a la forma de cambio de giro de los motores. Los motores sin escobillas llevan un sistema de carga de polos magnéticos para realizar el cambio de dirección, mientras que los motores con escobillas hacen circular la corriente por unas bobinas generando un campo magnético y en consecuencia atrayendo o repeliendo el rotor en un sentido u otro; cabe destacar que es necesario un mínimo de 3 bobinas para hacer girar el rotor puesto que, si se tuvieran sólo dos podría provocar que el motor se quedase en perpendicular cuando se produjese el cambio de giro.

 Se han elegido unos motores sin escobillas por su rendimiento, menor desgaste y fiabilidad, como los ilustrados en la figura 3.1 (4). 
% 
% \begin{figure}[Motores dron]{FIG:MOTORESDRON}{Motores de dron, 2 CW y 2 CCW.}
%	\image{4cm}{}{motoresDron}
%\end{figure}
                
 \newacronym{kv}{KV}{Kilo Voltage}
 Estos motores constan de 2300 \ac{kv} y sin escobillas, contando así con 3 cables: alimentación, masa y potencia. La velocidad de los motores varía mediante la utilización de una señal PWM, modificando su ciclo de trabajo desde 1 milisegundo (ms) hasta 2 ms, estableciendo a 1'5 ms funcionaría a mitad de potencia y a 2 ms funcionaría al 100\%.
 
\newacronym{pwm}{PWM}{Pulse width modulation} 
 
 Un \acl{pwm} es la modulación de una señal digital provocando en sistemas con menos velocidad de lectura la llegada de una señal analógica. Un PWM con una salida de 3,3 V y con un ciclo de trabajo del 50\% produciría en el sistema receptor una señal analógica de 3,3 V/ 50 = 0,66 V de señal de entrada, reduciendo su potencia un 50\%.

%\subsubsection*{Controlador de velocidad\label{SS:ESC}}{estructura/sistema/dron/esc}
 
 \paragraph{Controlador de velocidad}
 \label{SSS:Controlador de velocidad}

 \newacronym{esc}{ESC}{Electronic Speed Controller}

 El controlador de velocidad \ac{esc}, es un controlador esencial que determina la potencia suministrada al motor variando su velocidad. Es necesario instalar uno por cada motor controlándolos así de forma independiente.
 Por un lado cuenta con 2 ó 3 cables dependiendo de si es un controlador de velocidad para un motor con escobillas o sin ellas, y por otro lado dispone de 4 cables: dos cables de alimentación conectados a la placa de distribución de potencia y otros 2 que reciben la potencia que ha de suministrar al motor.
 
% \begin{figure}[Controlador de velocidad]{FIG:ESCDRON}{Controladores de velocidad dron.}
%	\image{4cm}{}{escDron}
%\end{figure}
 
 Los ESC se deben elegir en función de la batería que vayas a utilizar, teniendo en cuenta el número de celdas y su ratio de descarga continua. Los controladores de velocidad comprados, 3.1 (2), cuentan con una capacidad de descarga de 35 amperios indicando la potencia que pueden generar los motores. 
 
 Los ESC pueden recibir la señal PWM que indica la potencia que debe suministrar al motor, a partir del controlador de vuelo o directamente desde el receptor del mando. Es aconsejable recibirla desde el controlador de vuelo, ya que de esta forma se gestiona la estabilización del dron, favoreciendo un control mucho más fácil del aeromodelo\cite{OscarSerrano}. 

%http://fpvmax.com/2016/12/21/variador-electronico-esc-funciona/
 
\paragraph{Hélices}
\label{SSS:Helices}
%\subsubsection*{Hélices\label{SS:HELICES}}{estructura/sistema/dron/helices}

 %http://fpvmax.com/2017/02/10/helices-drones-tipos-tamanos/
 Las hélices son un componente menos crítico a la hora de elegirlas y montarlas sobre el dron, existen diferentes formatos con las siguientes características:
 \begin{description}
        \item[Tamaño:] Pueden variar desde 2 a 19 pulgadas, el tamaño de las hélices se ve limitado por el tamaño de los brazos del chasis donde se monten. Hay que tener en cuenta que a mayor tamaño mayor superficie y por tanto más empuje. Hoy en día se utilizan con más frecuencia las hélices entre 4 y 6 pulgadas las cuales favorecen el funcionamiento de drones con motores rápidos como los utilizados en drones de carreras, no obstante también se utilizan las hélices con tamaño de 10 o más pulgadas para aeromodelos que no priorizan la velocidad, si no que necesiten mayor estabilidad y llevar cargas elevadas.
 		\item[Número de aspas:] Varía desde 2 a 6 aspas, el número de aspas afecta a la superficie de empuje, aumentando la fricción y por tanto la fuerza que ejerce para levantar el dron. En hélices con un  tamaño pequeño de hasta 6 pulgadas, podemos encontrar hasta un máximo de 6 aspas, mientras que en hélices de mayor tamaño, 10 pulgadas o superior, no solemos superar las 2 aspas.
 		\item[Forma:] La forma es un punto crítico de este componente, tienen una forma de pala corvada para conseguir el empuje del aire en el sentido contrario de giro del motor. La terminación del aspa también afecta al vuelo de un dron, se pueden diferenciar: acabadas en punta,  Bullnose e Híbridas bullnose, determinando mayor o menor empuje y en consecuencia mayor o menor consumo.

 \end{description}
 
% \begin{figure}[Tipos de hélices dron]{FIG:HELICESDRON}{Tipos de hélices según  la terminación de sus aspas.}
%  \subfigure[SBFIG:HelicePunta]{Hélice con terminación en punta.}{\image{4cm}{}{helicePunta}} \quad
%  \subfigure[SBFIG:HeliceBullnose]{Hélice con terminación tipo bullnose.}{\image{4cm}{}{heliceBullnose}} \quad
%  \subfigure[SBFIG:HeliceHBullnose]{Hélice con terminación tipo híbrida bullnose.}{\image{4cm}{}{heliceHBullnose}}
%\end{figure} 

 En el dron diseñado se ha priorizado su tamaño, ya que como se ha explicado anteriormente el tamaño de las hélices afecta a la fuerza de empuje vertical del dron para poder levantar su carga, puesto que  se cuenta con un dron con un peso de 660 gramos y con una carga añadida de 200 g máximo, se ha elegido unas hélices de 5 pulgadas con un total de 3 aspas, obteniendo así un punto óptimo entre empuje o fuerza máxima y duración de vuelo, como la hélice de la figura 3.1 (5).

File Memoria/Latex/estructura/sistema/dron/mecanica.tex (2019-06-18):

\paragraph{Chasis}
\label{SSS:Chasis}
%\subsubsection{Chasis\label{SS:CHASIS}}{estructura/sistema/dron/chasis}

	El chasis de un dron es la estructura donde se van a montar todos los componentes anteriormente descritos, contamos con diferentes características al comprar o fabricar el nuestro:
	
	\begin{description}
	\item[Número y longitud de brazos] El número de brazos determina el número de motores que podemos instalar en nuestro aeromodelo, hay chasis desde 4 hasta 8 brazos, siempre números pares.
	La longitud de los brazos nos ayuda a instalar unas hélices de mayor tamaño.
	\item[Distribución] La distribución de los brazos no es una característica muy importante sino más bien estética. En chasis con 4 brazos podemos encontrar distribuciones en H o en X.
%	\begin{figure}[Chasis dron en X y H]{FIG:CHASISX}{Diferencia entre formas de chasis en X \ref{SBFIG:CHASISX} y H \ref{SBFIG:CHASISH} en drones.}
%	
%  \subfigure[SBFIG:CHASISX]{Chasis drone en forma de X}{\image{4cm}{}{ChasisDroneX}} \quad
%  \subfigure[SBFIG:CHASISH]{Chasis drone en forma de H}{\image{4cm}{}{ChasisDroneH}}
%  
%\end{figure} 
	\item[Material]
	El material del chasis dispone al dron de resistencia ante roturas en caso de accidente, rigidez a la hora de ejercer fuerza sobre él y peso según la composición del material utilizado.
	Se ha utilizado un chasis de fibra de carbono por su equilibrio entre las características mencionadas destacando su leve peso.
	\end{description}
	
%	\begin{figure}[Chasis dron]{FIG:CHASISDRON}{Chasis dron.}
%	\image{4cm}{}{chasisDron}
%\end{figure}	
		
	El dron elegido cuenta con un chasis de 4 brazos en disposición X y con un tamaño entre ejes de 220 milímetros permitiéndome instalar unas hélices de hasta 5 pulgadas, este chasis de fibra de carbono pesa un total 127 gramos.

\paragraph{Batería}
\label{SSS:Bateria}
%\subsubsection{Batería\label{SS:BATERIA}}{estructura/sistema/dron/bateria}

 La batería para cualquier radiocontrol es indispensable ya que es el elemento que proporciona la electricidad para que todo funcione, por eso es fundamental calcular el gasto de nuestro sistema y escoger una batería que nos proporcione una durabilidad media elevada.
 Se distinguen diferentes características de las baterías como:
 
 \begin{description}
 \newacronym{nicd}{NiCd}{Niquel Cadmio}
 \newacronym{lion}{L-ion}{Ion Litio}
 \newacronym{lipo}{LiPo}{Polímero de Ion Litio}
 \item[Composición: ]  Existen diferentes tipos de baterías en función de su composición. Hay diferentes tipos como \acl{nicd}, \acl{lion}, \acl{lipo}.
 \item[Capacidad: ] A más capacidad de carga más duración de vuelo tiene pero a su vez mas peso, perjudicando este al tiempo de vuelo.
 \item[Número de celdas: ] A mayor número de celdas generalmente la batería cuenta con más capacidad y más potencia al estar conectadas en serie.
 \item[Tasa de descarga: ] La tasa de descarga indica la tasa máxima de descarga que ofrece la batería, a mayor tasa más potencia se puede trasmitir a los motores y por tanto mayor empuje. 
 \end{description}

Para el dron utilizado, se ha escogido una batería de 3 celdas de Polímero de Ion Litio (LiPo) con una capacidad de 1500 miliamperios (mAh) y con un peso de 107 gramos (g), 3.1 (8). 

%	\begin{figure}[Batería dron]{FIG:BATERIADRON}{Batería dron.}
%	\image{4cm}{}{bateriaDron}
%\end{figure}

La configuración de esta batería nos ayuda a tener una capacidad óptima en relación con el peso. 
Está compuesta por polímero de Ion Litio proporcionando una durabilidad de 300 a 500 horas (h) de uso sin necesidad de mantenimiento por parte del usuario. 
Dispone de 3 celdas en serie consiguiendo una mayor capacidad de almacenamiento y mayor tensión de salida para alimentar el dron.

%https://www.reichelt.de/akku-pack-li-polymer-11-1-v-1500-mah-25-50-c-rd-slp-1500-s3-p208376.html?&trstct=pos_9

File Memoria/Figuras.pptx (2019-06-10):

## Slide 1

Raspberry Pi 3 B+

ESC-Motor

ESC-Motor

ESC-Motor

ESC-Motor

Descifrado de señal

Procesamiento de señal y comunicación a PCA9685

PCA9685

Generación PWM

Receptor

Recibir señal mando

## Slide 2

Gimnasio

17 m

0

3

1

10 m

Puerta almacén

X m

4

X m

Puerta principal

2

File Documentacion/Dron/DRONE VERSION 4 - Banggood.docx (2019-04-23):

Chasis x 2

https://www.banggood.com/Dragon-HX5-X5-220mm-5-inch-FPV-Racing-Frame-Kit-RC-Drone-4mm-Arm-Carbon-Fiber-p-1254005.html?ID=531381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

Controlador de vuelo x 2

https://www.banggood.com/Matek-F405-OSD-BetaFlight-STM32F405-Flight-Controller-Built-in-OSD-Inverter-for-RC-Multirotor-FPV-Racing-Drone-p-1141282.html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

PDB x 2

https://www.banggood.com/Matek-Systems-PDB-XT60-W-BEC-5V-12V-2oz-Copper-For-RC-Multirotors-p-1049051.html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

Motores (2CW y 2 CCW) x2

https://www.banggood.com/4X-Racerstar-2205-BR2205-2300KV-2-4S-Brushless-Motor-2-CW-2-CCW-For-QAV250-ZMR250-260-Multirotor-p-1066837.html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

Helices x 3

https://www.banggood.com/10-Pairs-Kingkong-5x4_5x3-5045-5-Inch-3-Blade-Propeller-CW-CCW-for-FPV-Racer-p-1067877.html?ID=228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

Batería x 2

https://www.banggood.com/ZOP-Power-14_8V-5000mAh-4S-60C-Lipo-Battery-XT60-Plug-p-1170983.html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

Protectores Hélices x 3

https://www.banggood.com/Diatone-Glass-Fiber-Propeller-Protective-Guard-For-200-250-Quadcopter-p-947803.html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

ESC x 2

https://www.banggood.com/4-PCS-Racerstar-RS30A-Lite-30A-Blheli_S-BB1-2-4S-Brushless-ESC-for-FPV-Racer-p-1101000.html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

Emisora y receptor x 1

https://www.banggood.com/FlySky-FS-i6-2_4G-6CH-AFHDS-RC-Transmitter-With-FS-iA6B-Receiver-p-983537.html?ID=42481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

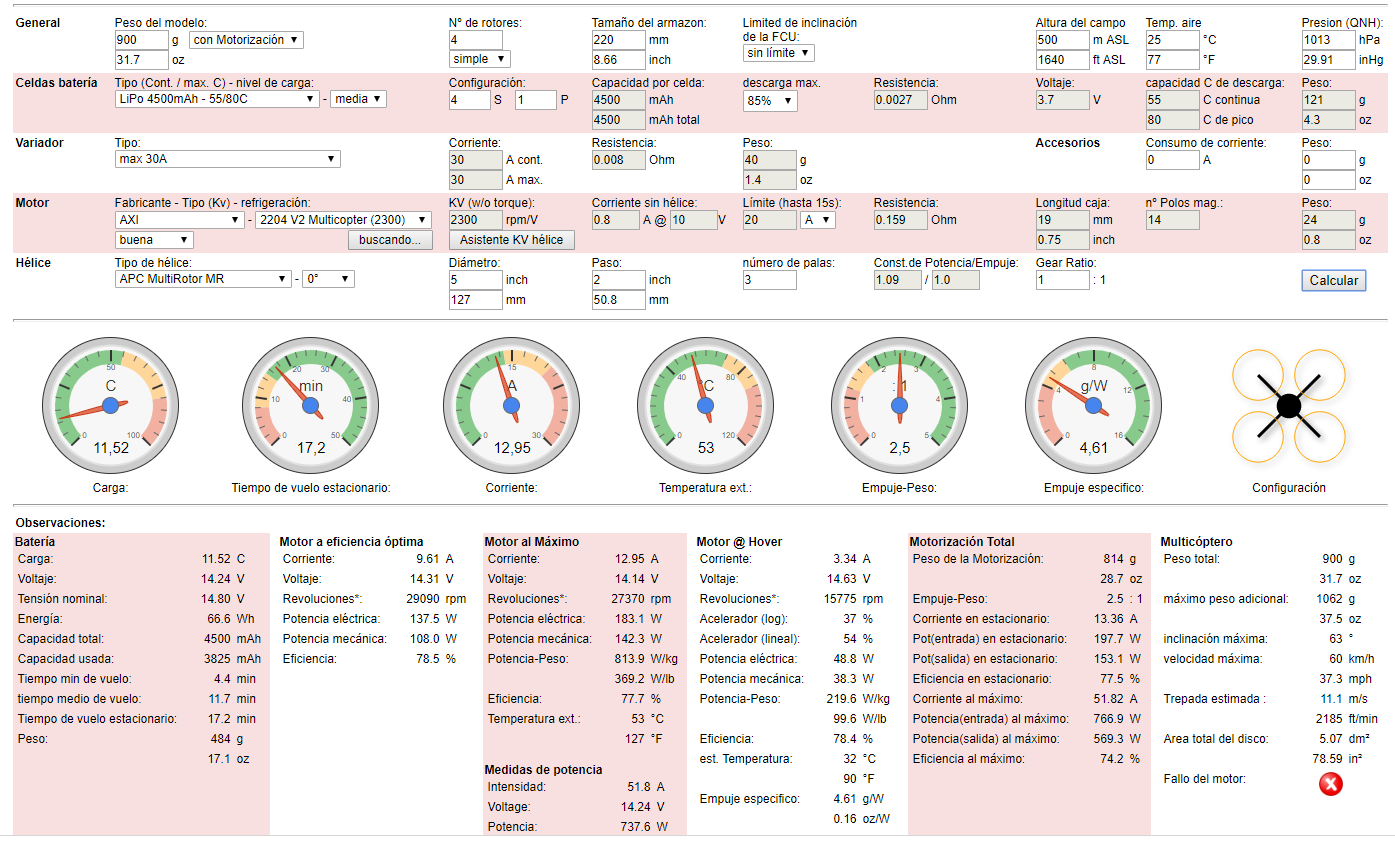
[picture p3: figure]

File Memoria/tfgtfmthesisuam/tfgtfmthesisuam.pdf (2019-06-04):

18
19

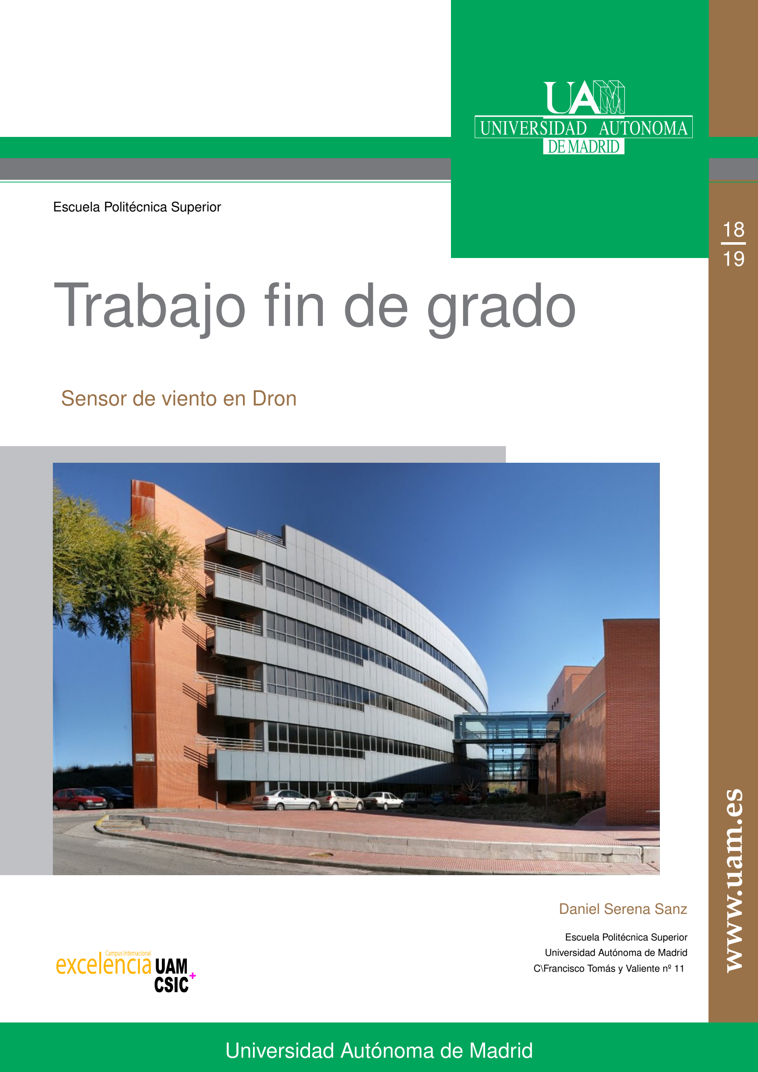
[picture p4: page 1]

# Trabajo fin de grado

Escuela Politécnica Superior

## Sensor de viento en Dron

## Universidad Autónoma de Madrid

# www.uam.es

Daniel Serena Sanz

Escuela Politécnica Superior

Universidad Autónoma de Madrid

C\Francisco Tomás y Valiente nº 11

## UNIVERSIDAD AUTÓNOMA DE MADRID

### ESCUELA POLITÉCNICA SUPERIOR

### Grado en Ingeniería de Textos

# TRABAJO FIN DE GRADO

## Sensor de viento en Dron

### Si hace falta subtítulo

### Autor: Daniel Serena Sanz Tutor: Daniel Serena Sanz

### junio 2019

Todos los derechos reservados.
Queda prohibida, salvo excepción prevista en la Ley, cualquier forma de reproducción, distribución comunicación pública
y transformación de esta obra sin contar con la autorización
de los titulares de la propiedad intelectual.
La infracción de los derechos mencionados puede ser constitutiva de delito contra la propiedad intelectual (arts. 270 y sgts. del Código Penal).

DERECHOS RESERVADOS
© 3 de Noviembre de 2017 por UNIVERSIDAD AUTÓNOMA DE MADRID Francisco Tomás y Valiente, no 1

Madrid, 28049
Spain

Daniel Serena Sanz

Sensor de viento en Dron

Daniel Serena Sanz
C\ Francisco Tomás y Valiente Nº 11

IMPRESO EN ESPAÑA PRINTED IN SPAIN

A mi mujer y a mis hijos

Lo peor es cuando has terminado un capítulo

y la máquina de escribir no aplaude.

Orson Welles

## Prefacio

Este estilo de LATEX 2ε ha sido diseñado con dos propósitos. El primer propósito es el de facilitar

en lo posible la escritura de trabajos de fin de grado y de máster y de tesis doctorales. En ese sentido

se han diseñado un conjunto de comandos que simplifican la escritura y diseño de estos trabajos

pero que reducen en cierta forma las capacidades de los paquetes de LATEX utilizados. Sin embargo,

dado que los paquetes están incluidos en esta clase, pueden utilizarse directamente y hacer diseños

más complejos pero si se hace esto se recomienda mantener una estética coherente con el resto del

documento.

El segundo de los propósitos es que estos documentos mantengan una estética uniforme en la

Universidad Autónoma de Madrid y fomentar una imagen corporativa en documentos tan relevantes

como los trabajos de fin de grado o de máster y las tesis doctorales. Por ese motivo se recomienda

mantener una coherencia estética en todo momento. El diseño facilita esa coherencia pero es posible

salirse del diseño si se mantine dicha coherencia.

Como creador de este estilo espero fervientemente que al usar este estilo te sientas cómodo y te

facilite la escritura de un documento que es muy relevante en esta etapa de tu vida. Para facilitártela

aún más, el código fuente de este documento también está disponible en tu ordenador o en overleaf

para que te sirva a modo de ejemplo.

Eloy Anguiano Rey

vii

## Agradecimientos

En primer lugar me gustaría agradecer a la Escuela Politécnica Superior por su apoyo para la

creación de esta clase y que sea el formato básico para la creación de tesis, trabajos fin de grado y

trabajos fin de master.

En particular quiero destacar el trabajo realizado por Fernando López-Colino por su apoyo en la

comisión de imagen institucional y por sus comentarios para mejorar este estilo.

También quiero tener un recuerdo para Carmen Navarrete Navarrete dado que este estilo comencé

a crearlo a partir de sus necesidades a la hora de escribir la tesis. Y por supuesto a no quiero olvi-

darme de mi esposa e hijos que han servido de conejillos de indias en sis correspondientes trabajos

fin de master y de grado. No quiero olvidar a todos los estudiantes que me pidieron este estilo y lo

han usado para presentar sus trabajos pero son muchos y podría olvidarme de alguno, por tanto, mi

agradecimiento en general a todos ellos.

ix

## Resumen

En nuestra Escuela se producen un número considerable de documentos, tantos docentes como

investigadores. Nuestros alumnos también contribuyen a esta producción a través de sus trabajos de

fin de grado, máster y tesis. El objetivo de este material es facilitar la edición de todos estos documentos

y a la vez fomentar nuestra imagen corporativa, facilitando la visibilidad y el reconocimiento de nuestro

Centro.

En este sentido se ha intentado diseñar un estilo de LATEX 2ε que mantenga una iimagen corpora-

tiva y con comandos simples que permitan mantener la imagen corporativa con la calidad necesaria

sin olvidar las necesidades del autor. Para ello se han creado un conjunto de comandos simples en

torno a paquetes complejos. Estos comandos permiten realizar la mayoría de las operaciones que un

documento de este tipo pueda necesitar.

Así mismo se puede controlar un poco el diseño del documento a través de las opciones del estilo

pero siempre manteniendo la imagen institucional.

## Palabras clave

Diseño de documento, LATEX 2ε, thesis, trabajo fin de grado, trabajo fin de master

xi

## Abstract

In our School a considerable number of documents are produced, as many aducational as research.

Our students also contribute to this production through his final degree, master and thesis projects. The

objective of this material is to facilitate the editing of all these documents and at the same time to

promote our corporate image, facilitating the visibility and recognition of our center.

In this sense we have tried to design a style of LATEX 2ε that maintains a corporate image and

with simple commands that allow to maintain the corporate image with the necessary quality without

forgetting the needs of the author. For this, a set of simple commands have been created around

complex packages. These commands allow you to perform most of the operations that a document of

this type may need.

Likewise, you can control a little the design of the document through the options of the style but

always maintaining the institutional image.

## Keywords

Document design, LATEX 2ε, thesis, final degree project, final master project

xiii

## Índice

1 Introducción | 1
2 Estado del arte | 3
3 Teoría | 5
4 Sistema | 7
5 Resultados experimentales y discusión | 17
6 Conclusión y outlook | 19
7 Como continuar el proyecto a partir de mis resultados | 21
8 Bibliografía | 23
9 Estética | 25
10 Estructura | 31

xv

11 Primeros pasos | 37
12 Elementos internos | 41
13 Compilación | 59
Bibliografía | 63

xvi

Definiciones | 65
Acrónimos | 67
Apéndices | 69
A Word® vs. LATEX 2ε | 71
B Instalación | 73
C Packetes incluidos | 77
D Resumen de opciones del estilo | 79
E Funciones y entornos | 83

xvii

## Listas

## Lista de algoritmos

12.1 Ejemplo de algoritmo | 54

## Lista de códigos

12.1 Respuesta a la conexión de los usuarios | | 53
12.2 Conexión TCP | | 53

## Lista de cuadros

12.1 Este es un cuadro de texto en el que usando el paquete lipsum se genera el texto

| internamente | | 50

13.1 Ejemplo de compilación con arara. Estos comentarios deben introducirse al principio del

| documento principal y permiten que arara realice las tareas indicadas en el orden que
| se indica | | 60

## Lista de ecuaciones

4.1a Primer ejemplo de subequación | | 13
4.1b Segundo ejemplo de subequación | | 13
4.1c Segundo ejemplo de subequación | | 13

12.1 Esto es un ejemplo de titulo de ecuación incluida la propia ecuación Pcij = R a
| adx . . . | 50
12.2a Primer ejemplo de subequación | | 50
12.2b Segundo ejemplo de subequación | | 50

## Lista de figuras

4.1 | | | 8
4.2 | | | 8

xix

4.3 | Ejes MPU9250 | | 8
4.4 | Chasis X y H | | 14
12.1 Ejemplo de uso de figure | | 41
12.2 Ejemplo de uso de figure | | 42
12.3 Esquemas de ejes de gráficas XY | | 43
12.4 Representaciión de expresiones matemáticas | | 44
12.5 Esquemas de ejes de gráficas XY | | 45
12.6 Ejemplo de diagrama de Gantt | | 46

## Lista de tablas

9.1 | Gamas de colores | | 26
9.2 | Colores complementarios | | 27
9.3 | Colores complementarios claros | | 27
9.4 | Colores complementarios oscuros | | 28
12.1 Tabla de ejemplo | | 47
12.2 Tabla de ejemplo con subtablas | | 48

## Lista de cuadros

xx

1

## Introduccion

´

1

2

## Estado del arte

3

3

## Teor

´
ia

5

4

## Sistema

sistema

## 4.1. Sensor de viento

Actualmente los sensores de vientos habituales cuentan con dos elementos básicos. Uno de ellos

se encarga de medir la velocidad del viento y el otro su dirección, a distinguir el anemómetro y la

veleta respectivamente. Estos dos elementos pueden encontrarse montados de forma separada o

conjuntamente denominándose veleta potencio métrica. Hay que tener en cuenta que este sistema,

aun siendo muy preciso, tiene un coste elevado y necesita de una instalación en una localización

fija, además de necesitar una altura y distancia mínima de cualquier superficie para poder realizar las

medidas correctamente.

Diariamente utilizamos dispositivos electrónicos que cuentan con sensores que miden la inclina-

ción, aceleración y dirección del dispositivo, podemos diferenciar desde un teléfono móvil a un coche

o incluso un avión. Estos sensores son utilizados para diversas funciones como, el nivel de un objeto

(un avión volando), la aceleración de un objeto (coche de fórmula 1), etc.

¿Por que no usar estos sensores para medir el viento?

En esta sección trataré de como utilizar un sensor de aceleración, giroscopio y magnetómetro

para medir el viento. Para realizar este experimento he utilizado el sensor MPU9250 [1] que cuenta

con la integración del sensor MPU6050, aceleración y giroscopio, y el sensor AK8963, magnetómetro,

componiendo de esta forma un microchip que mide en función de 3 ejes la alteración de su posición

respecto de la tierra.

Los datos obtenidos por el sensor MPU6050, son datos sin tratar que indican la aceleración en el

instante de la medición y la inclinación respecto de la anterior medida tomada, mientras que el sensor

AK8963 indica la orientación del sensor.

Para poder saber claramente en que posición se encuentra el chip respecto de una superficie plana

y no su inclinación respecto de la anterior medida, he utilizado el algoritmo de madgwick que utiliza

7

Sistema

cuaterniones para indicar la inclinación absoluta respecto de la tierra.

Los cuaterniones es un conjunto de cuatro componentes complejas que sirven para la teoría de

números, rotaciones en el espacio y para diseño de gráficos, en mi caso lo usaré para las rotaciones

en el espacio, los cuaterniones se pueden expresar de la siguiente forma [2].

Figura 4.1: Fórmula de cuaternion, podemos diferenciar w, x, y, z que son los valores reales que

componen el cuaternion Q y el conjunto i, j, k que componen la parte imaginaria de las unidades.

Mediante el algoritmo de madgwick, convertimos los datos obtenidos desde el giroscopio, acele-

rómetro y magnetómetro en un componente de 3 elementos, yaw, pitch y roll. Cada uno de estos

elementos nos indica su rotación respecto de un eje del aeromodelo.

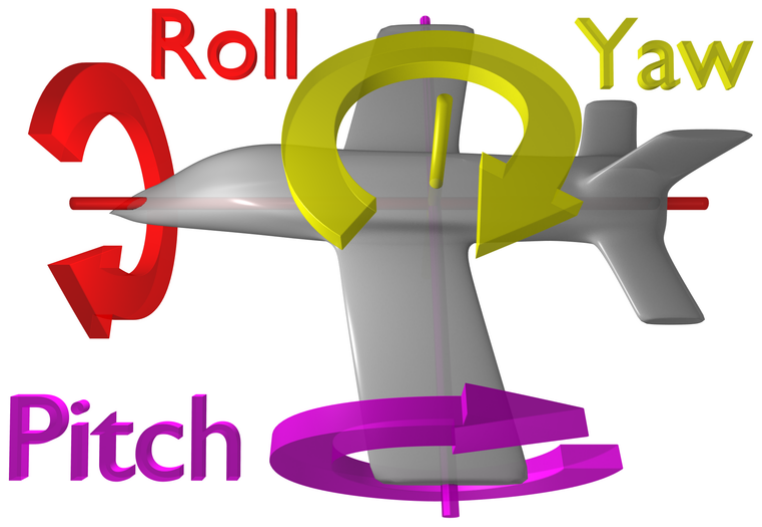
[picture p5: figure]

Figura 4.2: Avión con los ejes de giro, yaw, pitch y roll, obtenidos mediante cuaterniones.

Mediante la utilización de estas rotaciones respecto de sus ejes podemos determinar como hay

que actuar en los motores para que se mantenga volando estable y horizontal.

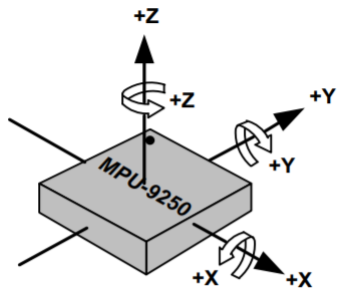
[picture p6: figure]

(a) Sensor MPU9250 con ejes del sensor

MPU6050

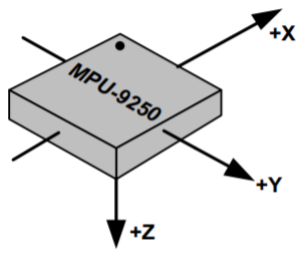
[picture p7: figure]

(b) Sensor MPU9250 con ejes del sensor

AK8963

Figura 4.3: Sensor MPU9250 con ejes de funcionamiento. Figura 4.3(a) muestra el sentido de los

ejes del sensor MPU6050. Figura 4.3(b) muestra el sentido de los ejes del sensor MPU6050.

En este punto contamos con la inclinación del sensor respecto de la tierra, su aceleración, dirección

en grados, con este conjunto de datos podemos calcular la variación de su posición respecto de un

punto.

Para calcular el viento he planteado un sistema en el que el sensor está situado en un "poste

8 | Sensor de viento en Dron

4.2. Dron

flexible.anclado al suelo, de esta forma si el sensor está orientado al norte y se inclina hacia delante

obtenemos una dirección de viento de sur a norte, y en caso de inclinarte hacia delante y la izquie-

ra, obtenemos un viento de sur-este. La fuerza del viento viene indicado directamente por los datos

obtenidos del acelerómetro en función de los tres ejes.

## 4.2. Dron

Para la construcción del dron sobre el que se han realizado las pruebas, se ha seguido una lista de

componentes, partiendo de los mas restrictivos y completando con aquellos mas flexibles dependiendo

del sistema montado. A continuación indicaré en grupos los componentes elegidos con una previa

descripción de su funcionamiento e importancia en el aeromodelo final.

## 4.2.1. Motores

Los motores son una parte fundamental de un dron ya que han de proporcionar la potencia sufi-

ciente para hacer girar la hélices y por consecuente hacer volar al dron.

He tenido en cuenta varios parámetros como por ejemplo, la potencia, el consumo y la fuerza máxi-

ma de empuje. Los motores vienen clasificados según su velocidad indicándose como KV, revoluciones

por minuto por voltio y su dirección de giro, distinguiendo entre CW y CCW, es necesario tener el mismo

numero de motores CW y CCW ya que estos giran en sentido contrario, el motivo de tener el mismo

número de motores que giren en sentido horario y anti horario es debido a que si no provocaría un

efecto de vórtice, haciendo girar el dron sobre si mismo sin ningún control. A su vez se pueden diferen-

ciar entre dos clases de motores, con escobillas o sin ellas, este factor afecta a la forma de cambio de

giro de los motores, los motores sin escobillas llevan un sistema de carga de polos magnéticos para

realizar el cambio de dirección mientras que los motores con escobillas hacen circular corriente por

unas bobinas generando un campo magnético y en consecuencia haciendo atraer o repeler el motor

en un giro u otro, cabe destacar que es necesario un total de 3 bobinas para hacer girar el motor,

puesto que si tuviésemos solo dos podría provocar que el motor se quedase en perpendicular cuando

se produjese el cambio de giro.

He elegido unos motores sin escobillas por su rendimiento, menor desgaste que los motores con

escobillas y sencillez a la hora de cambiar el sentido de giro.

Los motores elegidos constan de 2300 KV y sin escobillas, contando así con 3 cables: alimentación,

masa y potencia. Se varía la velocidad de los motores mediante la utilización de una señal PWM,

variándose desde un 0 % a un 100 % de potencia modificando su ciclo de trabajo desde 1 ms a 2’5 ms,

siendo a 1’5 ms funcionaría a mitad de la potencia y a 2 ms funcionaría al 100 %.

Un PWM es la modulación de una señal digital provocando en sistemas con menos velocidad de

Daniel Serena Sanz | 9

Sistema

lectura la llegada de una señal analógica. Un PWM con una salida de 3,3 V y con un ciclo de trabajo del

50 % produciría en el sistema receptor una señal analógica de 3,3 V/ 50 = 0,66 V de señal de entrada,

reduciendo su potencia un 50

## 4.2.2. ESC

El ESC, Electronic Speed Contoller, es un controlador esencial que determina la potencia suminis-

trada al motor, es necesario instalar uno por cada motor controlandolos asi de forma independiente.

Puede contar con 2 cables o 3 dependiendo si es un controlador de velocidad para un motor con

escobillas o sin ellas.

Los controladores de velocidad comprados cuentan con una capacidad de pico de descarga máxi-

ma de 35 amperios, la cantidad de descarga máxima limita la potencia máxima que pueden generar

los motores. Los ESC se deben elegir en función de la batería que vayas a utilizar, teniendo en cuenta

el número de celdas y su ratio de descarga continua.

Los ESC pueden recibir la señal que indique la potencia que debe de suministrar al motor, a partir

del controlador de vuelo o directamente desde el receptor del mando. Es aconsejable recibirlo desde el

controlador de vuelo ya que de esta forma gestiona un microchip la estabilización del dron, favoreciendo

a un control mucho mas fácil del aeromodelo a control remoto. [3]

## 4.2.3. Helices

Las hélices son un punto menos crítico a la hora de elegirlas y montarlas sobre el dron, contamos

con diferentes formatos, formas y número de aspas. Podemos encontrar hélices con las siguientes

características:

Tamaño: Puede variar desde 2 a 19 pulgadas, el tamaño de la hélices se ve limitado por el

tamaño de los brazos del chasis donde se monte. Hay que tener en cuenta que a mayor

tamaño mas superficie y por tanto mas empuje, hoy en día se utilizan mayormente las héli-

ces entre 4 y 6 pulgadas, estas hélices favorecen el funcionamiento de drones con motores

rápidos como los utilizados en drones de carreras, no obstante también se utilizan las hé-

lices con tamaño de 10 o mas pulgadas para aeromodelos que no priorizan la velocidad y

necesiten estabilidad y llevar cargas elevadas.

Número de aspas: Varía entre 2 a 6 aspas, el número de aspas afecta a la superficie de

empuje, aumentando la fricción y por tanto la fuerza que ejerce para levantar el drone.

En hélices de tamaño pequeño, hasta 6 pulgadas, podemos encontrar hasta un total de 6

aspas mientras que en hélices de tamaño grande, 10 pulgadas o más, no solemos superar

las 2 aspas.

10 | Sensor de viento en Dron

4.2. Dron

Forma: La forma es un punto crítico de este elemento, tienen una forma de pala corvada para

conseguir el empuje del aire en el sentido contrario de giro del motor. La terminación del

aspa también afecta a la hora de volar un dron, se pueden diferenciar acabadas en punta,

Bullnose e Híbridas bullnose, determinando mayor o menor empuje y por consecuente

mayor o menor consumo. Podemos contar con hélices de 2 a 6 aspas, con un tamaño

variable desde 2 hasta 19 pulgadas.

En el dron diseñado he priorizado el tamaño, como he explicado anteriormente el tamaño de las

hélices afecta a la fuerza de empuje vertical del dron para poder levantar su carga, no obstante dado

que contamos con un dron con un peso máximo de NOSECUANTOS gramos y con una carga añadida

de 200g máx., he elegido unas hélices de 5 pulgadas con un total de 3 aspas, obtenidendo asi un

punto óptimo entre empuje o fuerza máxima y duración de vuelo.

## 4.2.4. Placa distribuidora de potencia

Un punto crucial de los componentes electrónico es su alimentación, para favorecer la durabilidad

y estabilidad del circuito o circuitos electrónico debemos aislar el circuito de potencia del circuito lógico

mediantes elementos con la placa distribuidora de potencia (PDB) que cuenta con elementos como

diodos, resistencias y transistores para evitar picos de tensión y derivaciones.

Esta placa se encarga de conectarse con la batería mediante un conector, en este caso, XT60; este

conector impide conectar cada polo con su opuesto debido a su forma evitando cortocircuitos y daños

al sistema.

Por otro lado, la PDB distribuye la tensión necesaria al resto de los componentes, entre los que

destacamos:

ESC: Hasta un total de 6 controladores de velocidad, en mi caso son 4 ESC que funcionan

con baterías de 2 a 4 celdas y por tanto desde 6 voltios a 16 voltios.

Circuito 5V: Circuitos de 5 voltios de tensión con un sistema de BEC para evitar picos y

conseguir un circuito con alimentación continua y estable, con una potencia continua de 2

amperios y una potencia máxima de 2’5 amperios.

Circuito 12V: Circuitos de 12 voltios de tensión, con el mismo funcionamiento que los circui-

tos a 5 voltios, con una potencia continua de 500 mA y máxima de 0’8 amperios.

## 4.2.5. Controlador de vuelo

La placa controladora de vuelo es la unidad de procesamiento del dron, es la encargada de gestio-

nar la señales provenientes del receptor, leer los parámetros de los diferentes sistemas de estabiliza-

Daniel Serena Sanz | 11

Sistema

ción y su posterior modificación para proporcionar la potencia adecuada a cada ESC.

Placa comercial

La elección de la controladora de vuelo viene determinada solamente por el protocolo de comunica-

ción que uses, aunque a día de hoy la mayoría de controladoras cuentan con software re programable

que se ajusta a los diferentes sistemas de comunicación, como los mas conocidos iBUS o sBUS.

En la controladora de vuelo puede conectarse el sistema de comunicación, sistema de vídeo, con-

troladores de velocidad de los motores, bocina de emergencia, antena de comunicación de largo al-

cance.

REF

Placa desarrollada

En este TFG he reproducido el sistema de control del dron en una Raspberry Pi 3 B+, con el fin de

unificar todos los controles en un solo punto y poder utilizar todas señales entrantes y salientes para

su uso en mediciones posteriores.

Para representar el sistema de la controladora de vuelo he partido del sistema de descifrado del

protocolo de comunicación elegido, iBUS, este protocolo te manda paquetes de información por el un

puerto serie. La raspberry cuenta con dos pines de comunicacion por puerto serie, Rx para recibir la

información y Tx para transmitir la información. El paquete recibido tiene un tamaño total de 31 bytes,

con un byte inicial standard con contenido igual a , a continuacion encontramos un total de 14 canales

con 2 bytes por canal y un checksum al final con un tamaño de 1 byte. El paquete es transmitido cada

7ms con una tasa de baudios de 115200, es decir, un total de 115200 bits por segundo. Para desglosar

el paquete recibido por el mando he codificado un algoritmo en python donde diferencio y convierto

cada uno de los bytes a decimal, obteniendo de esta forma un valor de cada canal entre 1000 y 2000,

siendo 1000 el mínimo valor y 2000 el máximo valor posible.

Para poder producir el PWM correcto y mandarselo a los controladores de velocidad, he contado

con un chip conversor, PCA9685, de digital a PWM hasta un máximo de 8 canales, ha sido necesario

dicho chip ya que a raspberry no cuenta con el numero suficiente de canales como para controlar 4

motores. La configuración del controlador PCA9685 se ha realizado mediante comunicación por I2C y

su respectiva librería de adafruit obtenida por github. He tenido que indicar la frecuencia de salida de

los PWM, 2KHz, y el ciclo de trabajo previamente obtenido por nuestro rango de entrada entre 1000 y

2000. [4]

Sistema

Input: mínimo de 1000 y máximo de 2000

12 | Sensor de viento en Dron

4.2. Dron

Output: señal PWM a 2Khz de frecuencia y un ciclo de trabajo de 125us hasta un máximo de

250us

PCA9685

Input: canal de 1 a 8, mínimo entre 3296 y 2498, máximo rango fijo 4095

Output sistema: señal PWM a 2Khz de frecuencia y un ciclo de trabajo de 125us hasta un

máximo de 250us

input = [1000, 2000] | (4.1a)

rango = 3296 − (input − 1000) ∗

(3296 − 2498)
1000

(4.1b)

pwm.setpwm(canal, rango, 4095) | (4.1c)

Una vez tengo la señal de salida PWM en función de la entrada del mando, modifico la señal a

partir de los datos obtenidos por el sensor MPU9250 el cual nos indica la inclinación y fuerzas que se

ejercen sobre el dron. De esta forma mandamos la potencia adecuada a cada motor para conseguir un

vuelo estable y horizontal. Debido a las dificultades de probar el sistema de estabilización y su ajuste,

decidí por trabajar con la placa comercial.

## 4.2.6. Chasis

El chasis de un dron es la estructura donde se van a montar todos los componentes anteriormente

descritos, contamos con diferentes características a elegir a la hora de comprar o fabricar nuestro

chasis:

Número y longitud de brazos El número de brazos determina el número de motores que po-

demos instalar en nuestro aeromodelo, hay chasis con 4 hasta 8 brazos, siempre números

pares. La longitud de los brazos nos ayuda a instalar unas hélices de mayor tamaño.

Distribución La distribución de los brazos es una característica no muy importante y más

bien estética. En chasis con 4 brazos podemos encontrar distribuciones en H o en X.

Material El material del chasis dispone su rigidez y peso al dron, el material mas utilizado

es la fibra de carbono por su leve peso y su rigidez que permite recibir golpes sin llegar a

romperse.

El dron elegido cuenta con un chasis con un total de 4 brazos en disposición H con un tamaño total

de cada brazo de 220 milímetros permitiéndome instalar unas hélices de hasta 5 pulgadas, este chasis

de fibra de carbono pesa un total 127 gramos.

Daniel Serena Sanz | 13

Sistema

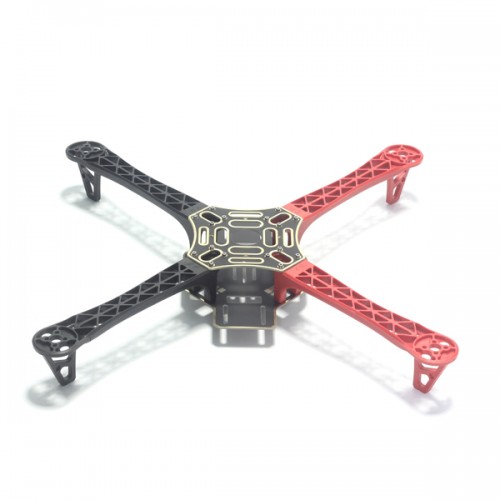
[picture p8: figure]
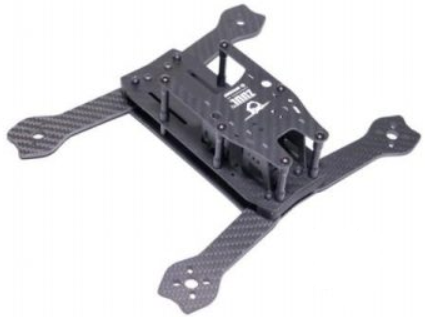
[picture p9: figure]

(a) Chasis drone en forma de X | (b) Chasis drone en forma de H

Figura 4.4: Diferencia entre formas de chasis en X 4.4(a) y H 4.4(b) en drones.

## 4.2.7. Sistema de comunicación

El sistema de comunicación cuenta con dos componentes, receptor y transmisor, se pueden elegir

diferentes tipos teniendo en cuenta su protocolo de comunicación.

El sistema de comunicación tiene diferentes protocolos para transmitir la información, utiliza un

protocolo de comunicación entre emisor y receptor y otro distinto entre receptor y unidad de procesa-

miento o controladora de vuelo. El protocolo de comunicación entre receptor y emisor tiene que ser

siempre iguales, es por eso que la mayoria de mandos, emisores, vienen con un receptor standard. En

mi caso he utilizado un pack FlySky entre emisor y receptor. [5]

Entre el receptor y la unidad de procesamiento podemos encontrar protocolos como PWM, PPM,

SBUS, iBus entre otros. La diferencia entre estos protocolos es la forma de estructurar el paquete

de datos o la conexión que hay que realizar a nivel de hardware. Por su simplicidad y comodidad he

utilizado el protocolo PWM que cuenta con un paquete de transmisión de 31 bytes.

## 4.2.8. Batería

Las baterías para cualquier radio control son indispensables ya que es elemento que proporciona

la electricidad para que todo funcione, por eso es indispensable calcular el gasto de nuestro sistema

para escoger una batería que nos proporcione una durabilidad media elevada. A la hora de elegir una

batería podemos encontrar diferentes parámetros donde escoger, como:

Composición: Podemos encontrar múltiples baterías en función de su composición. Hay

diferentes tipos como Niquel Cadmio(NiCd), Ion Litio (Li-ion), Ion Litio Polímero (LiPo).

Capacidad: A mas capacidad de carga de la batería mas duración de uso tiene pero a su

vez mas peso. Afectando el peso al tiempo de vuelo en el caso del dron.

Número de celdas: Cuanto mayor es el número de celdas, generalmente, más capacidad

de la batería y más potencia. Las celdas tienen una tensión de 3’3 V y al estar conectadas

14 | Sensor de viento en Dron

4.3. Sensor de viento en Dron

en serie proporcionan un total de 11V.

Tasa de descarga: La tasa de descarga indica la tasa máxima de descarga que ofrece la

batería, a mayor tasa de descarga mas potencia se transmite a los motores y por tanto

mayor empuje.

Para el dron utilizado he escogido una batería de 3 celdas de Ion Litio Polímero (LiPo) con una

capacidad de 1500 miliamperios (mAh) con un peso de 107 gramos (g). La configuración de esta

batería nos ayuda a tener una capacidad aceptable en relación con el peso, al ser una batería de LiPo

propociona una durabilidad de 300 a 500 horas (h) de uso sin necesidad de mantenimiento por parte

del usuario, al tener 3 celdas en serie conseguimos una mayor capacidad de almacenamiento y mayor

tensión de salida para alimentar el sistema.

## 4.2.9. Cargador de batería

El cargado de batería aunque no influye a la hora de utilizar el aeromodelo, ha de tenerse en cuenta

para poder recargar las baterías.

## 4.3. Sensor de viento en Dron

Lets to about it.

Daniel Serena Sanz | 15

5

## Resultados experimentales y

# discusion

´

17

6

# Conclusion y outlook

´

conclusion

19

7

## Como continuar el proyecto a

## partir de mis resultados

continuarproy

21

8

## Bibliograf

´
ia

Para la creación de la bibliografía se ha elegido el uso de BibTex dado que es el que permite más

versatilidad a la hora de crear bibliografía.

La bibliografía siempre aparecerá al final del documento aunque es necesario configurar su funcio-

namiento. Para ello se utilizará el comando \bibliographyconfig[estilo]{fichero} que tiene un pará-

metro opcional que es el estilo de la bibliografía y el paraámetro obligatorio es el nombre del fichero.bib

en el que está la bibliografía en formato BibTex obviando la extensión de este fichero. El estilo por

defecto es el siam. Por ejemplo se debe citar con el comando \cite{label} como en este ejemoplo de

cita [6] en el que se usa la etiqueta Narendra1990 que es la etiqueta asociada al artículo en el fichero

.bib correspondiente.

En la mayoría de las entradas de la base de datos se puede introducir un campo note. Si en ese

comando se indica algo como: note = “\href{file://unfichero.pdf}{Leer}” se puede realizar el hiper-

enlace al documento correspondiente almacenado junto al documento creado. También se pueden

realizar enlaces a páginas web [7].

23

9

## Estetica

´

La estética de este documento no debe ser modificada, ni el tipo de letra, ni los colores, ni los már-

genes ni ningún otro elemento predefinido en las funciones y entornos diseñados. Si por algún motivo

se tiene la necesidad de utilizar elementos externos a este estilo se recomienda hacerlo utilizando unos

colores y estética similares al resto del documento. A pesar de todo hay algunos elementos estéticos

que el usuario puede seleccionar.

## 9.1. Tipo de documento

Este estilo está diseñado para escribir tres tipos de documentos distintos que tienen pequeñas

variaciones entre ellos: trabajo fin de grado, trabajo fin de máster y una doctoral. Para poder seleccionar

estas variaciones es ncesario indicarlo en las opciones de la clase. Estas opciones son: tfg, tfm o

thesis. Dado que el documento que más veces va a ser generado son los trabajos fin de grado la

opción por defecto es tfg y por tanto no es necesario indicarla. La forma de seleccionar esta opción es

de la siguiente forma: \documentclass[thesis]{tfgtfmthesisuam}.

## 9.2. Gama de colores

Se dispone de una gran cantidad de gamas de colores que está diseñada utilizando los colores

corporativos de cada facultad y escuela universitaria de la Universidad Autónoma de Madrid, por ello

las gama de color que se debe utilizar en cada caso está relacionada con la facultad o escuela corres-

pondiente. Así mismo se dispone de una gama propia de la universidad para casos en los que no se

corresponda con la imagne corporativa asociada a una determinada facultad o escuela que es la gama

asociada a la universidad.

Al igual que para el tipo de documento el color corporativo debe seleccionarse como una opción del

documento. Para seleccionar la imagen corporativa genérica debe utilizarse la opción uambased y pa-

ra seleccionar la imagen corporativa de una facultad o escuela debe utilizarse alguna de las siguientes:

cienciasbased, derechobased, economicasbased, enfermeriabased, epsbased, filosofiabased,

25

Estetica ´

fisioterapiabased, medicinabased, profesoradobased o psicologiabased.A modo de ejemplo y

mezclado con la selección realizada en la sección anterior: \documentclass[thesis,epsbased]

{tfgtfmthesisuam}.

## 9.3. Colores

El uso de los colores es muy simple, basta con usar el comando \color{nombrecolor}. Hay mu-

chos colores predefinidos dependiendo de la gama de colores elegida. En la tabla 9.1 se muestran

todos estos colores donde el nombre del color se construye utilizando el prefijo correspondiente a su

columna, la gama de colores representado en la fila y siempre acabado con el sufijo ‘based’. Una de las

columnas no tiene prefijo y se corresponde con el color institucional. Por ejemplo, el color depsbased

sería .

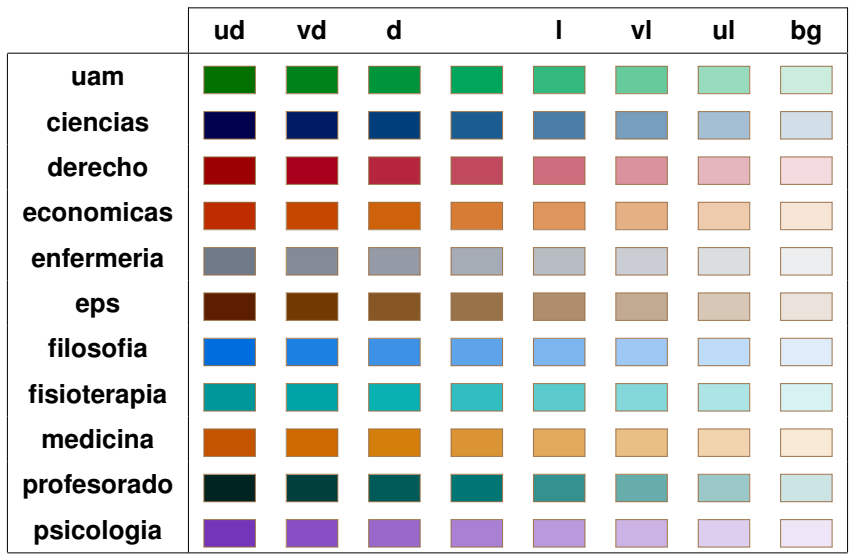
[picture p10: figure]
uam; ciencias; derecho; economicas; enfermeria; eps; filosofia; fisioterapia; medicina; profesorado; psicologia

Tabla 9.1: Gamas de colores y nombres de los colores correspondientes. El nombre del color se

construye utilizando el prefijo correspondiente a su columna, la gama de colores representado en la

fila y siempre acabado con el sufijo ‘based’.

Así mismo existen un conjunto de colores para cada perfil de color que pueden verse en la tabla

9.2 para los colores básicos, para los colores ‘vl’ (verylight) se pueden ver en la tabla 9.3 y para los

colores ‘vd’ (verydark) se pueden ver en la tabla 9.4.

## 9.4. Uso de los colores

Se puede usar cualquier color usando su nombre o con el comando \color{nombrecolor} según

corresponda. Sin embargo no se recomienda el uso de estos colores de forma aleatoria. Según la gama

de colores elegida se puede usar un conjunto de colores mucho más simple y que se corresponden

26 | Sensor de viento en Dron

9.4. Uso de los colores

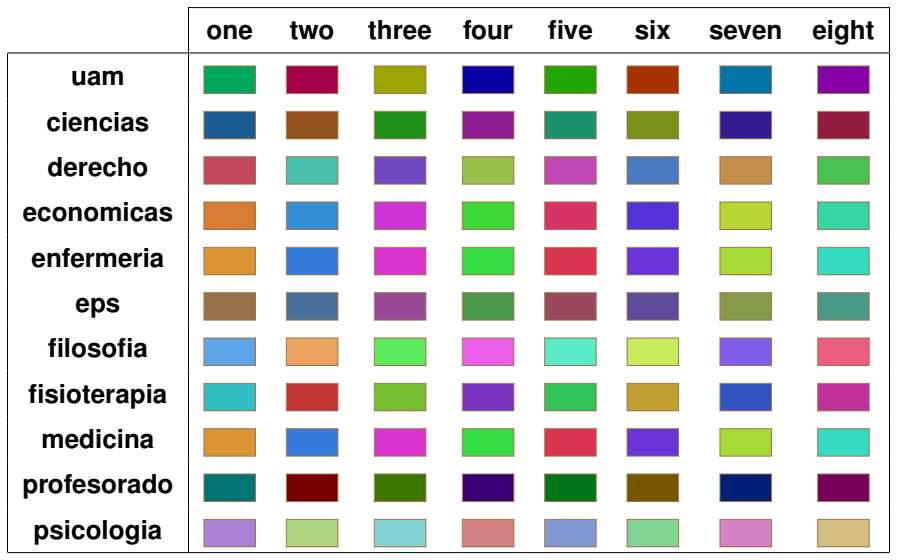
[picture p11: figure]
one; two; three; four; five; six; seven; eight; uam; ciencias; derecho; economicas; enfermeria; eps; filosofia; fisioterapia; medicina; profesorado; psicologia

Tabla 9.2: Colores complementarios. El nombre del color se construye concatenando el nombre de

la fila con el sufijo ‘based’ y se añade como segundo sufijo el nombre de la columna.

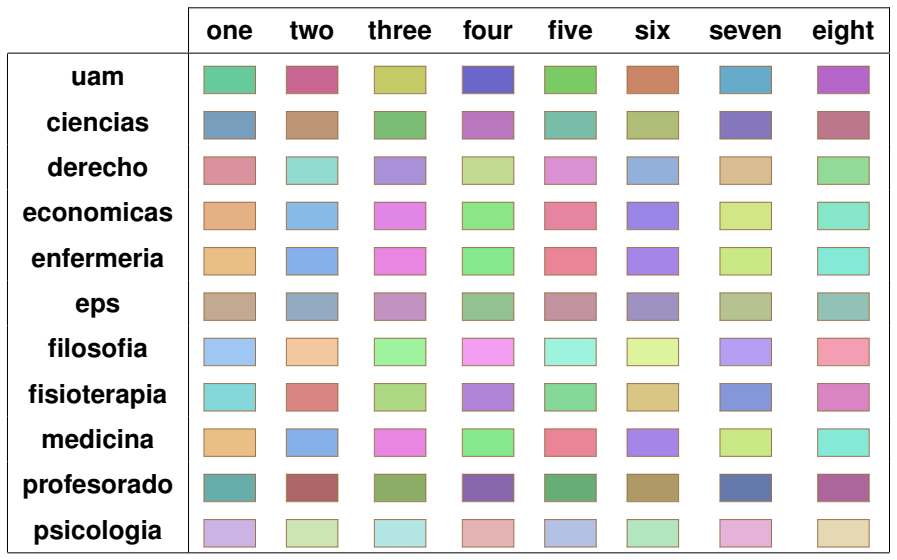
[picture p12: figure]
one; two; three; four; five; six; seven; eight; uam; ciencias; derecho; economicas; enfermeria; eps; filosofia; fisioterapia; medicina; profesorado; psicologia

Tabla 9.3: Colores complementarios claros. El nombre del color se construye concatenando el nom-

bre de la fila con el prefijo ‘vl’, el sufijo ‘based’ y se añade como segundo sufijo el nombre de la

columna.

Daniel Serena Sanz | 27

Estetica ´

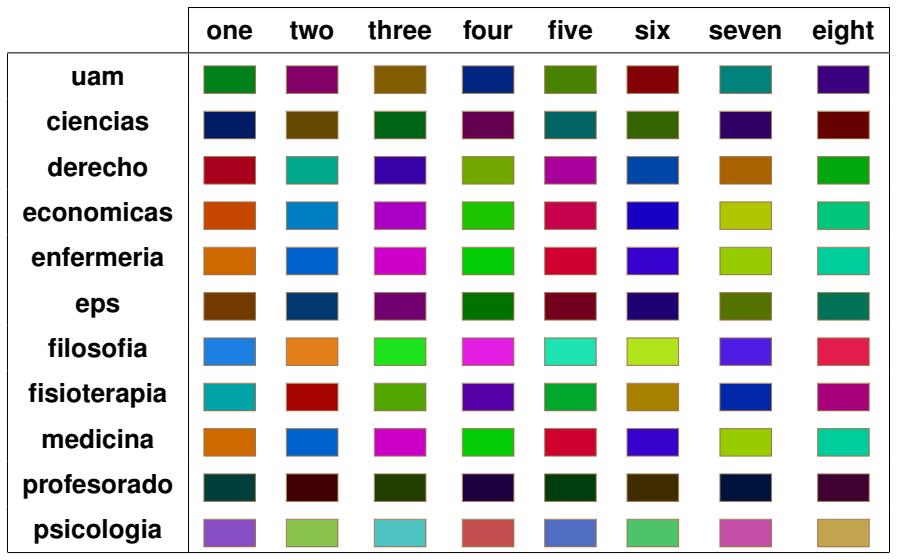
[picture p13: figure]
one; two; three; four; five; six; seven; eight; uam; ciencias; derecho; economicas; enfermeria; eps; filosofia; fisioterapia; medicina; profesorado; psicologia

Tabla 9.4: Colores complementarios oscuros. El nombre del color se construye concatenando el

nombre de la fila con el prefijo ‘vd’, el sufijo ‘based’ y se añade como segundo sufijo el nombre de la

columna.

con los de las tablas de color de la gama elegida. Los colores tienen el nombre adecuado al entorno

en el que deben ser usados. La lista de estos colores es la siguiente:

maincolor Color principal, usado en casi todos los elementos del documento que necesiten

color en el texto.

dmaincolor Color principal en su versión oscura (no se usa por defecto en ningún elemento).

descriptioncolor Color que se utiliza en elemento descrito en las listas de descripción como

esta, por defecto idñentico a ‘maincolor’.

headfootcolor Color utilizado en las cabeceras y pies de página, por defecto idñentico a

‘maincolor’.

textcolor Siempre es negro.

textboxfgcolor Color ‘foreground’ de los cuadros de texto.

textboxbgcolor Color ‘background’ de los cuadros de texto.

codefgcolor Color ‘foreground’ de los códigos presentados.

codebgcolor Color ‘background’ de los códigos presentados.

equationfgcolor Color ‘foreground’ de las ecuaciones.

equationbgcolor Color ‘background’ de las ecuaciones.

commentcolor Color de los comentarios en los códigos.

complementaryone ... complementaryeight Son los ocho colores complementarios usables

en gráficos.

28 | Sensor de viento en Dron

9.4. Uso de los colores

complementarylightone ... complementarylighteight Son los ocho colores complementa-

rios suaves.

complementarydarkone ... complementarydarkeight Son los ocho colores complementa-

rios oscuros.

Daniel Serena Sanz | 29

10

## Estructura

En este capítulo se explican todos los elementos que conforman la estructura de un documento.

Para elementos internos a la estructura como son las figuras, las tablas o las ecuaciones es necesa-

rio leer el capítulo 12. Si lo que se busca es cómo diseñar y estructurar el documento debe leer el

capítulo 11.

## 10.1. Título, autor, tutor y otras variables

Se dispone de una colección de variables que es necesario definir en el preámbulo del texto (antes

de \begin{document}). Estas variables permiten que el documento esté estructurado correctamente.

Las variables que es obligatorio definir son las siguientes:

\title[valor]{Valor} ‘Valor’ es el título del trabajo mientras que ‘valor’ es el título del trabajo

reducido que es el que se utilizará en los pies de página de las páginas pares pero no es

necesario definirlo si el título es suficientemente corto.

\author{Valor} ‘Valor’ es el nombre del autor del documento.

\advisor{Valor} ‘Valor’ es el nombre del tutor o tutores o del director o directores.

\levelin{Valor} ‘Valor’ es el grado que se pretende obtener.

\copyright{Valor} ‘Valor’ es la fecha del copyright.

También se dispone de otro conjunto de variables que no es necesario definir pero que son útiles

en algunas situaciones:

\speaker{Valor} ‘Valor’ es el nombre en caso de existir. Si no existe no es necesario definir

esta variable.

\privateaddress{Valor} ‘Valor’ es la dirección privada del autor. Esta variable se utiliza en el

copyright y puede no definirse.

\faculty{Valor} ‘Valor’ es el nombre de la facultad o escuela pero no es necesario definirlo

salvo que difiera del predefinido a través de la variable de la opción asociada a la imagen

31

Estructura

corporativa que se explica en la sección 9.2.

\facultylogo{Valor} ‘Valor’ es el nombre del fichero con el logo de la facultad o escuela sin

extensión pero no es necesario definirlo salvo que difiera del predefinido a través de la

variable de la opción asociada a la imagen corporativa que se explica en la sección 9.2.

\facultylogowide{Valor} ‘Valor’ es el ancho del logo de la facultad o escuela pero no es nece-

sario definirlo salvo que difiera del predefinido a través de la variable de la opción asociada

a la imagen corporativa que se explica en la sección 9.2.

## 10.2. Índices

Además del tradicional índice de contenidos se disponen de otros muchos índices controlables a

través de las opciones de la clase. Si se utiliza la opción loall se presentarán todos los índices. Por

el contrario la opción lonone elimina todas estas listas. Si no se usa ni estas opciones ni las que se

describen a continuación se presentarán todos los índices. Las siguientes opciones no se excluyen

entre si de tal forma que es posible indicar varias simultáneamente:

loa Presenta la lista de algoritmos.

loc Presenta la lista de códigos.

loe Presenta la lista de ecuaciones.

lof Presenta la lista de figuras.

lot Presenta la lista de tablas.

ltb Presenta la lista de cuadros de texto.

Como norma de estilo se recomienda no añadir una lista si no tiene al menos 3 elementos aunque

queda a discreción del autor.

## 10.3. Copyright, dedicatoria y cita inicial

El texto del copyright aparecerá siempre por defecto en el reverso de la portada, sin embargo se

puede cambiar usando opciones de la clase. Estas opciones pueden tomar tres valores, copyright,

copyleft y nocopyright. La primera de ellas muestra un texto de copyright y es el valor por defecto, la

segunda un texto de copyleft y la tercera elimina el texto de copyright.

En este tipo de documentos suele hacerse una dedicatoria corta y citar alguna frase celebre. Am-

bas cosas se se pueden hacer con los comandos \dedication{} y \famouscite{} en el preámbulo del

documento y que llevan como parámetro la dedicatoria y la cita celebre. En los fuentes de este docu-

mento se puede encontrar un ejemplo de estos dos comandos. Debido a cómo son estos comandos

32 | Sensor de viento en Dron

10.4. Prefacio, resumen ...

no deben introducirse líneas en blanco en los textos y los saltos de línea o párrafo deberán hacerse

con \\ o \\[height].

## 10.4. Prefacio, resumen, abstract, agradecimientos y

palabras clave.

Existen varios elementos previos al texto como son el abstract, el resumen, los agradecimientos y

el prefacio. Suele ser habitual que todos ellos sean obligatorios salvo el prefacio. Sin embargo no apa-

recerán los que no se indiquen usando los comandos correspondientes. Todos ellos deberán escribirse

en ficheros aparte y el parámetro de los comandos será el fichero (incluyendo el path relativo) sin el

‘.tex’ del final. Los comandos son los siguientes:

\prefacefile{fichero} Prefacio.

\resumenfile{fichero} Resumen en castellano.

\abstractfile{fichero} Resumen en inglés.

\ackfile{fichero} Agradecimientos.

Todos estos comandos deben usarse en el preámbulo, antes de \begin{document}.

Así mismo se deben usar otros dos comandos para introducir las palabras clave al final del resumen

y del abstract. Ambos comandos tienen un sólo parámetro y son las palabras clave separadas por

comas. Estos comandos son \palabrasclave{} y \keywords{}. Estos comandos deben usarse al final

del fichero con el resumen o con el abstract según corresponda.

10.5. Partes, capítulos, apartados, subapartados,

## subsubapartados, párrafos y subpárrafos

Las partes, capítulos, apartados, subapartados y demás elementos de este tipo pueden usarse de

dos formas, una es la tradicional de LATEX 2ε con un parámetro opcional que se corresponde con el

título de la parte, capítulo o sección que aparecerá em el índice y en las cabeceras o pies de página.

El primer parámetro obligatorio será el nombre completo de la parte, capítulo o sección. El parámetro

opcional sólo se utilizará si el nombre completo es demasiado largo.

La segunda forma de usarlo es idéntica a la tradicional pero añadiendo un segundo parámetro

obligatorio en el que se pondrá el nombre del fichero (sin ‘.tex’) en el que esté el texto de esa parte,

capítulo, sección, etc.

Daniel Serena Sanz | 33

Estructura

De forma resumida los comandos completos, incluyendo el segundo parámetro obligatorio son en

orden decreciente:

\part[shorttitle]{title}{file} Partes.

\chapter[shorttitle]{title}{file} Capítulos.

\section[shorttitle]{title}{file} Apartados.

\subsection[shorttitle]{title}{file} Subapartados (nomalmente no se presenta en el índice si

no se utiliza la opción de índice extendido).

\subsubsection[shorttitle]{title}{file} Subsubapartados (no se presenta ne el índice si no se

utiliza la opción de índice completo).

\paragraph[shorttitle]{title}{file} Párrafos (no se presenta ne el índice).

\subparagraph[shorttitle]{title}{file} Subpárrafos (no se presenta ne el índice).

## 10.6. Glosario, acrónimos y definiciones

Tres elementos que también están disponibles para los autores son el glosario, la lista de acrónimos

y la lista de definiciones.
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

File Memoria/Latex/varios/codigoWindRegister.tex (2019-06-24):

Para las pruebas realizadas se ha diseñado y codificado un programa en python con dos métodos de registro de datos. El primero para una sola toma y el segundo para un conjunto de datos, definidos como una matriz. Para ambos métodos se ha de indicar al inicio del programa el tiempo de medición, tomando por cada segundo un total de 10 muestras, este número se puede incrementar o disminuir.

\PythonCode[COD:CODIGOPYWIND]{Código registro de viento - parte 1}{En este código se muestra el protocolo del main para registrar las medidas en sus dos modos, una sola toma de datos o varias.}{pseudoMain.py}{1}{27}{1}
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

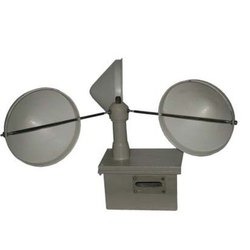
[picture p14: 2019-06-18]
Memoria/referencias anemometros/Cup Anemometer, कप एनीमोमीटर, कप एनेमोमीटर - Electro Mechanical Enterprises, Noida _ ID_ 12493118573_files/cup-counter-anemometer-250x250.jpg

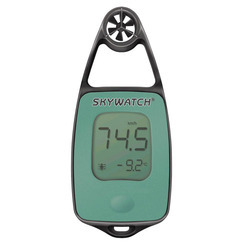
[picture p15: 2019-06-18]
Memoria/referencias anemometros/Cup Anemometer, कप एनीमोमीटर, कप एनेमोमीटर - Electro Mechanical Enterprises, Noida _ ID_ 12493118573_files/handheld-anemometers-250x250.jpg

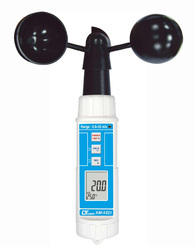
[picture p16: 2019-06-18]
Memoria/referencias anemometros/Cup Anemometer, कप एनीमोमीटर, कप एनेमोमीटर - Electro Mechanical Enterprises, Noida _ ID_ 12493118573_files/anemometer-cup-type-250x250.jpg

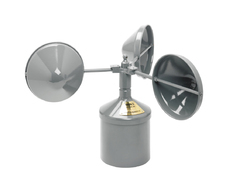
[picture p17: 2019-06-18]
Memoria/referencias anemometros/Cup Anemometer, कप एनीमोमीटर, कप एनेमोमीटर - Electro Mechanical Enterprises, Noida _ ID_ 12493118573_files/anemometer-250x250(1).jpg

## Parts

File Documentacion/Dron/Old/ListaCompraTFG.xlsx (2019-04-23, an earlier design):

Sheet: DRON 1
 | NOMBRE | CANTIDAD | PESO (g) | POTENCIA | OBSERVACIONES | ENLACE
CHASIS | S500 | 1 | 425 |  |  | https://hobbyking.com/es_es/s500-glass-fiber-quadcopter-frame-480mm-integrated-pcb-version.html | Calculo Thrust
MOTORES | MultiStar 980 | 4 | 165 | 377 |  | https://hobbyking.com/es_es/multistar-350-to-450-frame-size-2212-combo-set-with-self-tightening-propellers-cw-ccw-set-of-2.html | 994.95
HELICES | Propulsor 9x4.7 blanco | 4 | 11.75 |  |  | https://hobbyking.com/es_es/hobbyking-8482-propeller-9x4-7-white-ccw-4pcs.html
BATERIA | Turnigy 5000mA | 1 | 432 |  |  | https://hobbyking.com/es_es/turnigy-5000mah-3s-20c-lipo-pack-xt-90.html
CONTROLADOR | RASPI3B+ | 1 | 45
EXTRA |  | 1 | 200
THRUST |  |  |  | 1131
 |  |  | 1809

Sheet: DRON 2
 | NOMBRE | CANTIDAD | PESO (g) | POTENCIA | PRECIO | OBSERVACIONES | ENLACE
CHASIS | HobbyKing ™ TORTAZO 300 | 1 | 172 |  |  |  | https://hobbyking.com/es_es/hobbykingtm-smack-300-premium-fpv-ready-folding-quad-copter-frame-kit.html
MOTORES | Multistar Elite 2306-2150KV | 4 | 37.5 | 400 |  |  | https://hobbyking.com/es_es/multistar-elite-2306-2150kv-mini-monster-quad-racing-motor-ccw.html | 591.03
HELICES | Propulsor 9x4.7 blanco | 4 | 6.85 |  |  |  | https://hobbyking.com/es_es/quanum-carbon-fiber-propeller-6x4-5-cw-ccw-2pcs.html
BATERIA | Turnigy 3000mAh | 2 | 214 |  |  |  | https://hobbyking.com/es_es/turnigy-graphene-3000mah-3s-15c-w-xt60.html
CONTROLADOR | RASPI3B+ | 1 | 45
ESC |  | 4 | 11.3
CONTROLADOR |  | 1 | 7
EXTRA |  | 1 | 200 | 1200
 |  |  | 1074.6

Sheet: DRON 3
 | NOMBRE | CANTIDAD | PESO (g) | POTENCIA | OBSERVACIONES | ENLACE
CHASIS | Dardo 230 FPV | 1 | 103
MOTORES | Multistar Elite 2306-2150KV | 4 | 30 | 320 |  | https://hobbyking.com/es_es/multistar-2206-2150kv-motor-the-baby-beast.html | 739.2
HELICES | Propulsor 9x4.7 blanco | 4 | 3 |  |  | https://hobbyking.com/es_es/diatone-5030-plastic-self-tightening-propellers-5-x-3-cw-ccw-black-2-pairs.html
BATERIA | Turnigy 3000mAh | 2 | 432 |  |  | https://hobbyking.com/es_es/turnigy-graphene-3000mah-3s-15c-w-xt60.html
CONTROLADOR | RASPI3B+ | 1 | 45
EXTRA |  | 1 | 200
 |  |  |  | 960
 |  |  | 1344

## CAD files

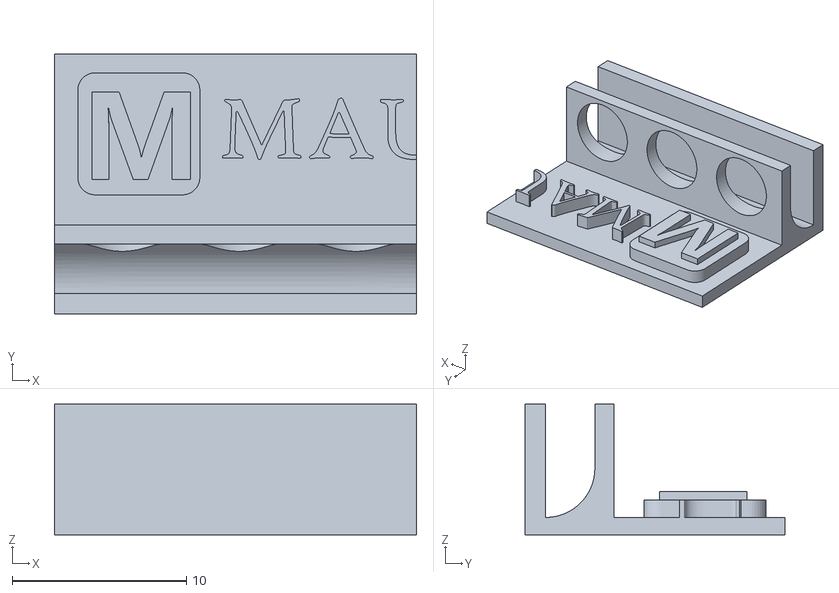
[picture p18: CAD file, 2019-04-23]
Modelos3D/Inventor3DModel/mausah0.stl
20.8 x 14.9 x 7.50

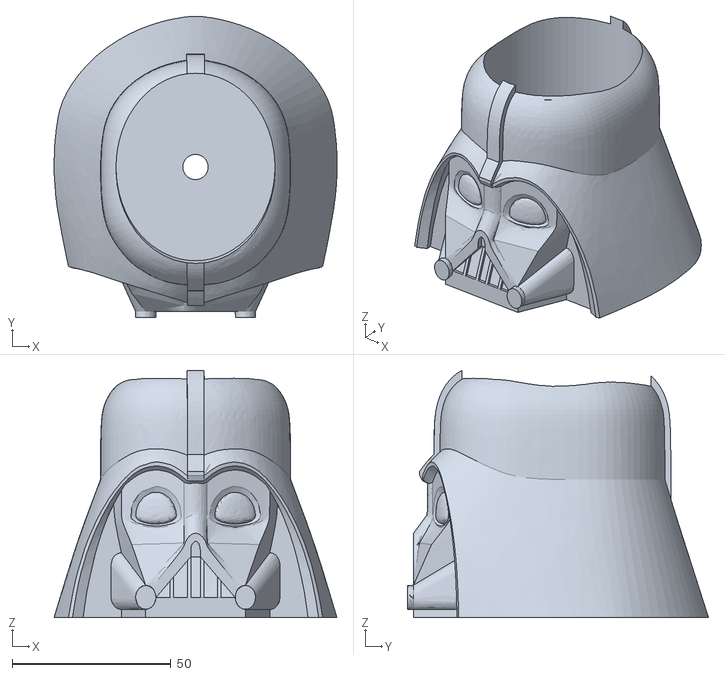
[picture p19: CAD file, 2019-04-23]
Modelos3D/Inventor3DModel/STL/Folks/Darth_Vader_Pot_v2.stl
89.0 x 94.7 x 77.8

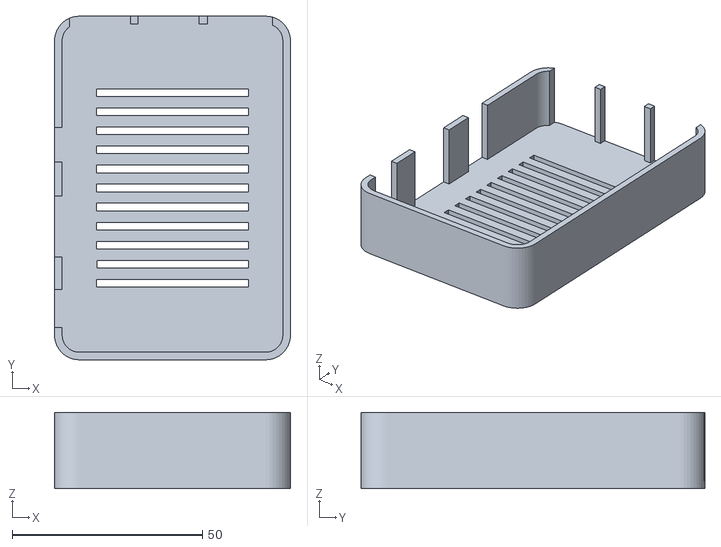
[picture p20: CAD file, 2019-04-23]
Modelos3D/Inventor3DModel/STL/TapaChasisDron_P1.stl
62.0 x 90.3 x 20.0

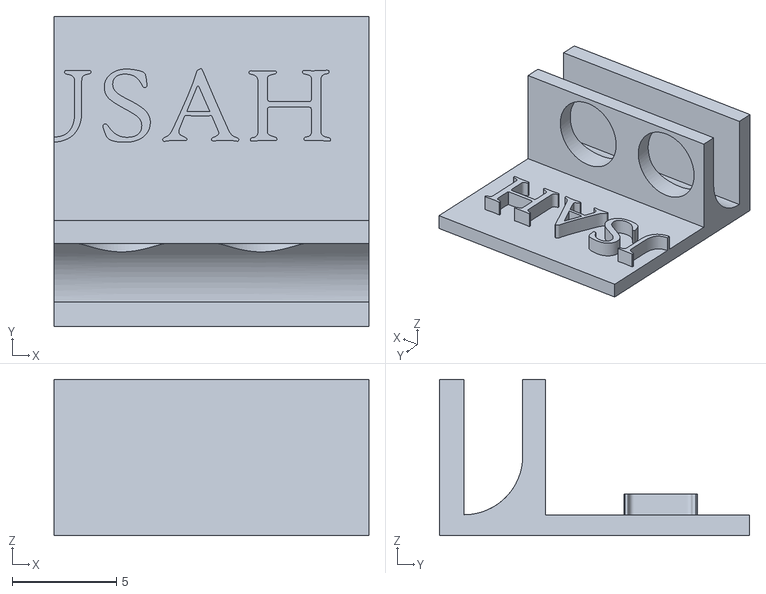
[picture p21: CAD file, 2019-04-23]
Modelos3D/Inventor3DModel/mausah1.stl
15.1 x 14.9 x 7.50

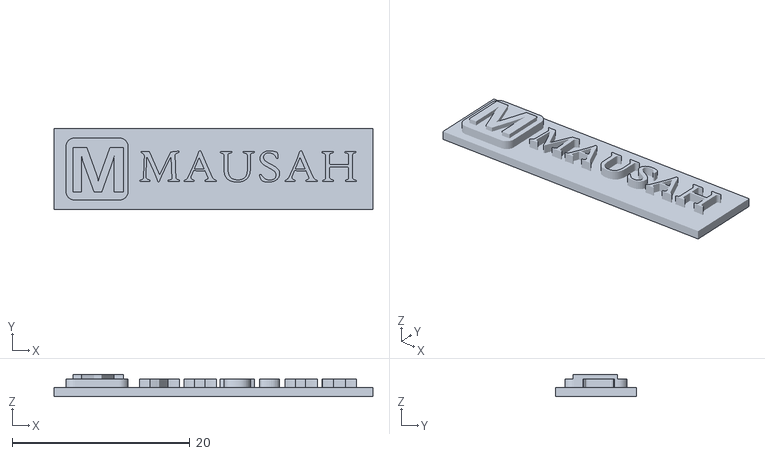
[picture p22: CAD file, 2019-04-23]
Modelos3D/Inventor3DModel/STL/Folks/mausahSinChupi.stl
35.9 x 9.13 x 2.50

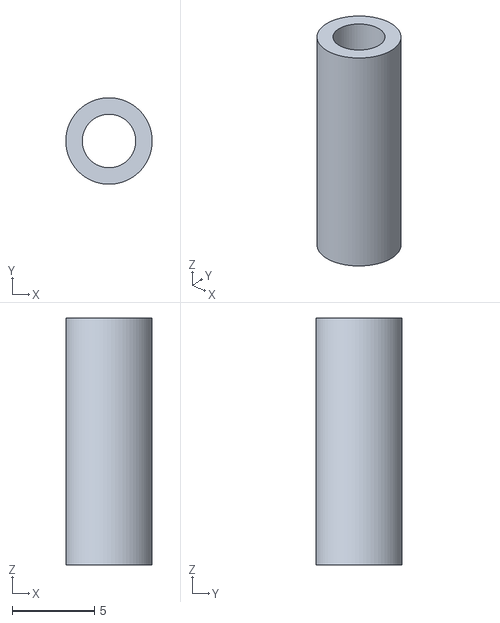
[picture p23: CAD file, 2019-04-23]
Modelos3D/Inventor3DModel/STL/Separador.stl
5.25 x 5.24 x 15.0

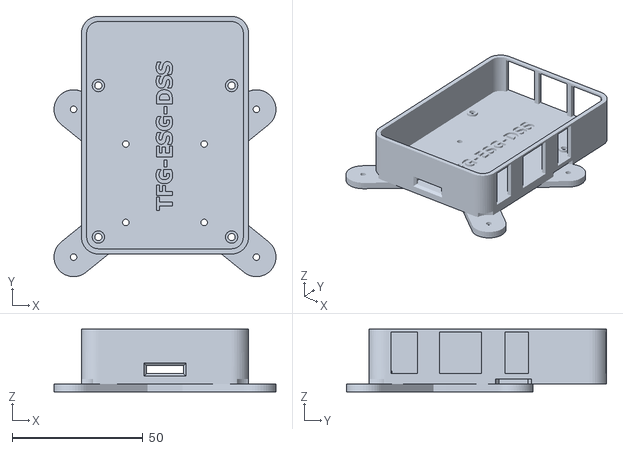
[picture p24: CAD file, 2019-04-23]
Modelos3D/Inventor3DModel/STL/ChasisInferiorDron_ConParedes_P0.stl
85.0 x 99.7 x 24.0

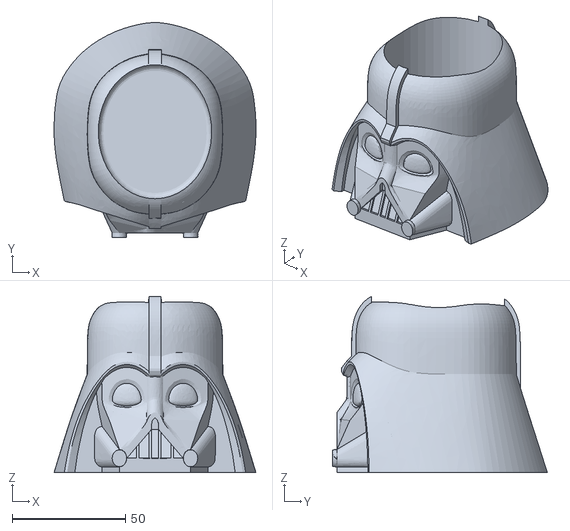
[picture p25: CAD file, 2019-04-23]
Modelos3D/Inventor3DModel/STL/Folks/Darth_Vader_Pot.stl
89.1 x 94.7 x 77.8

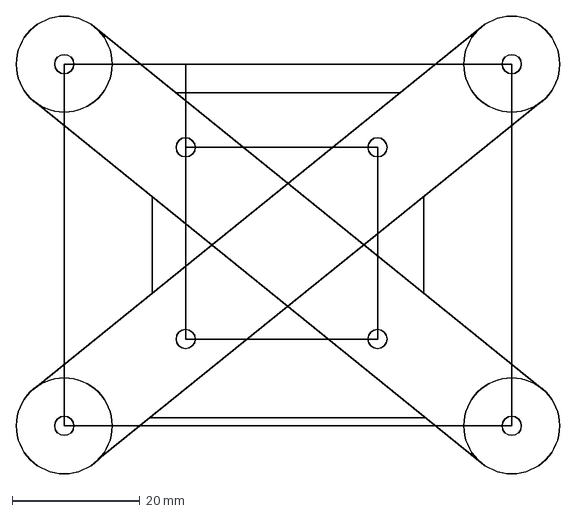
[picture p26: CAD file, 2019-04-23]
Modelos3D/Inventor3DModel/ChasisInferiorDron_P0.dxf
85.0 x 71.6 mm

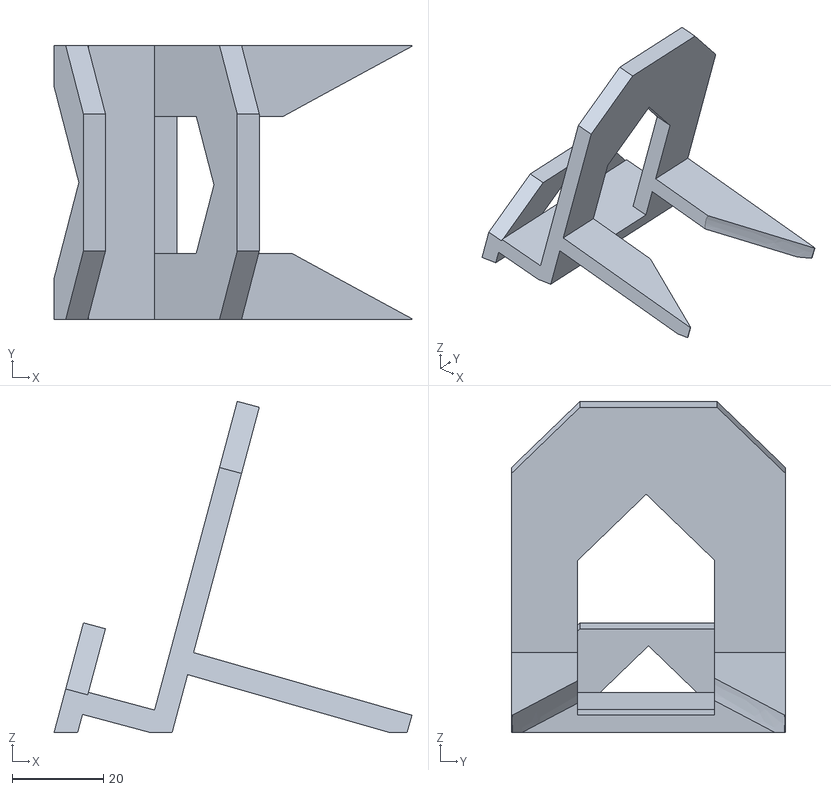
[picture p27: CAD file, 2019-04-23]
Modelos3D/Inventor3DModel/STL/Folks/phone-holder.stl
78.4 x 60.0 x 72.6

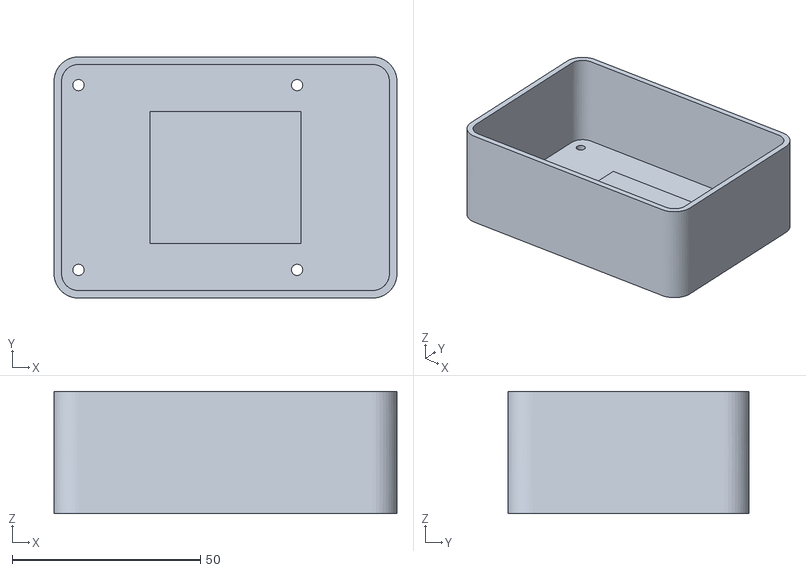
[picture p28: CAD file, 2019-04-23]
Modelos3D/Inventor3DModel/STL/TapaIntermedia.stl
91.0 x 64.0 x 32.5

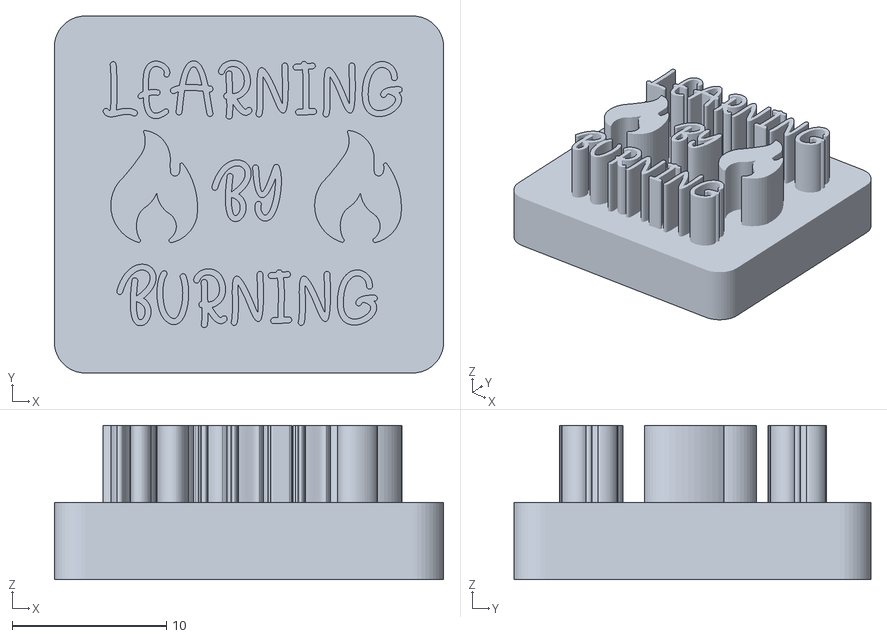
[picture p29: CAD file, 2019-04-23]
Modelos3D/Inventor3DModel/STL/Folks/LearningByBurning.stl
25.2 x 23.1 x 10.0

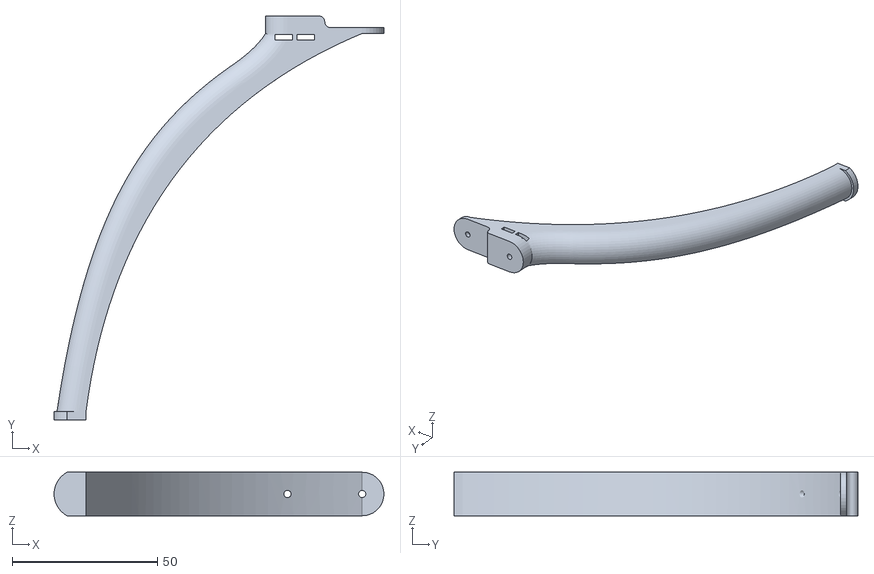
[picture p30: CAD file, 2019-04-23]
Modelos3D/Inventor3DModel/STL/PataDronSD_mk1.stl
113.5 x 139.0 x 15.0

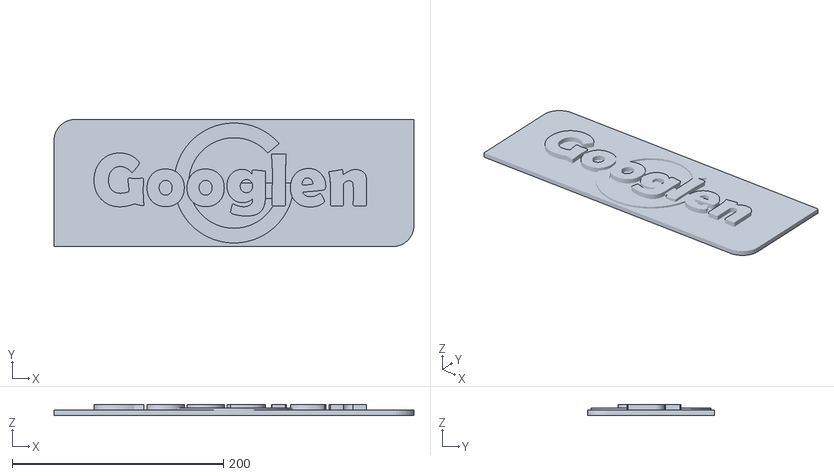
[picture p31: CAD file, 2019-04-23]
Modelos3D/Inventor3DModel/STL/Folks/+.stl
340.4 x 120.2 x 10.0

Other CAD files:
Modelos3D/Inventor3DModel/Pieza2.dwg
Modelos3D/Inventor3DModel/STL/PataDronSD_mk2.stl
Modelos3D/Inventor3DModel/STL/Folks/HablarEsFundamental.stl
Modelos3D/Inventor3DModel/STL/xyzCalibration_cube.stl
Modelos3D/Inventor3DModel/ChasisInferiorDron_ConParedes_P0.ipt
Modelos3D/Inventor3DModel/ChasisInferiorDron_P9.ipt
Modelos3D/Inventor3DModel/ChasisInferiorDron_SinParedes_P0.ipt
Modelos3D/Inventor3DModel/Googlen.ipt
Modelos3D/Inventor3DModel/HablarEsFundamental.ipt
Modelos3D/Inventor3DModel/IntentoEnsamblaje.iam
Modelos3D/Inventor3DModel/LearningByBurning.ipt
Modelos3D/Inventor3DModel/OldVersions/mausah.0003.ipt
Modelos3D/Inventor3DModel/PataDronSD_II.ipt
Modelos3D/Inventor3DModel/Pieza2.ipt
Modelos3D/Inventor3DModel/RasPi3B+.ipt
Modelos3D/Inventor3DModel/STL/Folks/LearningByBurning2.stl
Modelos3D/Inventor3DModel/STL/Folks/mausah.stl
Modelos3D/Inventor3DModel/STL/SeparadorRoscado.stl
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

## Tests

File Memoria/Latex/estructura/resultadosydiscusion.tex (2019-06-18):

\section{Instrumentos de medición\label{SEC:INSTR}}
Esta sección tratará los instrumentos de medición con los que realizaran las pruebas, tanto los diseñados a nivel de hardware como los elementos software de toma de datos. 
A nivel físico se cuenta con el dron construido y su equipo: batería, mando-receptor, hélices, motor, controlador de velocidad, PDB y chasis; cabe nombrar el escenario donde se han realizado las pruebas. A nivel de software se ha contado con programas diseñados y codificados en python 3 por su facilidad a la hora de codificar y su versatilidad en cuanto a incluir librerías ya implementadas por otros usuarios. Se ha tenido que desarrollar dos programas: un primero encargado de la toma de medidas como las descritas en la sección \ref{SEC:SENSORVIENTO} y un segundo programa que usa estas medidas y las plasma en gráficas adecuadas para su interpretación.

Para usar el dron construido se dispone con 3 baterías de 1500 mAh que proporcionan una media de 15 minutos de vuelo interrumpido, con vuelos de aproximadamente 10 segundos por cada medida.
Las baterías sirven para dar potencia al dron descrito en el apartado \ref{SEC:SENSORVIENTODRON}. Para maniobrar el dron se utiliza un mando de un alcance teórico de 500 metros como el ilustrado en la figura \ref{FIG:DRONPARTES}(1).

La utilización de drones se ha visto aumentada en los ultimos años, desde drones pequeños, de menos de 2 Kg, hasta drones de grandes dimensiones que pueden llegar a pesar más de 25 kg. Son aparatos que puede ser utilizados tanto para uso recreativo como para transporte de paquetes o incluso personas. Dependiendo de su práctica y sus características, peso y tamaño, es necesario tener una licencia para su uso. Se puede distinguir diferentes tipos de licencia como por ejemplo: licencias para drones de desde menos de 2 kilogramos (kg) de peso hasta más de 25, licencias para su uso a corta o larga distancia o licencias en función del escenario donde se pretenda volar el aeromodelo.

Para el dron que se ha desarrollado no es necesario un permiso especial puesto que es un objeto de menos de 2 kg de peso, no obstante dado que se puede clasificar como un dron para su uso industrial se podría necesitar con una licencia especial para poder realizar la toma de medidas.

\newacronym{ies}{IES}{Instituto de Educación Secundaria}
Esta es la razón por la que la mayoría de las tomas de medidas se han realizado en un sitio cerrado, utilizando las instalaciones del \ac{ies} Valle Inclán en Torrejón de Ardoz. Las tomas de medidas se han realizado en horario no lectivo en un sitio controlado por varios ayudantes.

\begin{figure}[Plano gimnasio IES Valle Inclán]{FIG:PLANOGIMNASIO}{Plano del gimnasio del IES Valle Inclán con las entradas/salidas que afectan a la toma de medidas. Puntos 1-4 representan los puntos donde se ha relizado la toma de medidas. Punto 0 representa el foco del viento.}
	\image{13cm}{}{planoGimnasio}
\end{figure}

El escenario principal utilizado ha sido el gimnasio del centro, que cuenta con un espacio de 10 m x 17 m x 4'6 m, dispone de varias puertas de las que sólo hay que tener en cuenta aquellas que dan a la calle, ya que son las que podrían alterar las medidas tomadas por la circulación del aire. La puerta principal da paso al centro de la sala, la puerta del almacén del material se encuentra en la esquina izquierda del gimnasio. 

Un segundo escenario donde se han realizado las medidas es en el Monumento de los Guardias Forestales localizado en el municipio de Rascafría, Madrid, dirección Puerto de Cotos. En esta localización se probó un vuelo al aire libre y de mayor altura con viento moderado para comprobar cómo se comporta el dron en situaciones más reales.

\section{Toma de medidas\label{SEC:TOMAMEDIDAS}}{estructura/resultados/tomamedidas}
\section{Resultados\label{SEC:EXPOSICION}}{estructura/resultados/exposicion}

%\section{Interpretación de medidas tomadas\label{SEC:INTR}}{estructura/resultados/interpretacion}

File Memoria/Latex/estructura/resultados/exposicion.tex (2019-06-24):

 
\newacronym{si}{SI}{Sistema Internacional}

Cabe señalar que las medidas obtenidas y representadas se encuentran en funcion de la unidad de fuerza G, es decir, la gravedad. Se ha mantenido así por mayor claridad y unificación con los sistemas de aceleración estudiados; no obstante, se indica en la ecuación \ref{EQ:ConversionGaN} la conversión necesaria para poder representarlo en el \ac{si} de unidades.

Las pruebas realizadas se han hecho con el dron volando e iniciando el software de recogida de datos en vuelo; los datos obtenidos mediante la serie de pruebas descritas en el apartado \ref{SEC:TOMAMEDIDAS} son los representados en las siguientes imágenes: \ref{FIG:3axisforces}, \ref{FIG:scatterFit}, \ref{FIG:MAPACALOR}(a),\ref{FIG:MAPACALOR}(b), \ref{FIG:PLANOSMEDIDAS}(a), \ref{FIG:PLANOSMEDIDAS}(b) y \ref{FIG:mapa3d}.

\begin{subequations}
\begin{equation}[EQ:ConversionGaN]{Fórmula de conversión G}
	1\:G=9,807\:m\:{s}^{-2}
\end{equation}

\begin{equation}[EQ:ConversionSIaN]{Fórmula de conversión a N}
	1\:N=1\:Kg\:m\:{s}^{-2}
\end{equation}
\end{subequations}

\newacronym{n}{N}{Newton}

Para convertir a \ac{n} de fuerza, se debe multiplicar usando la fórmula \ref{EQ:ConversionSIaN} por el peso del dron, indicado en la sección \ref{SEC:DRON}.

\begin{figure}[Aceleraciones en 3 ejes]{FIG:3axisforces}{Aceleración en fuerza G que sufren los 3 ejes cartesianos. Cada gráfica representa un eje: gráfica superior eje X, medio eje Y e inferior eje Z. Las rectas rojas indican el punto de reposo de cada eje.}
	\image{1\textwidth}{}{3axisforces}
\end{figure}
En la figura \ref{FIG:3axisforces} se pueden observar 3 gráficas con una serie de puntos negros, la resolución del acelerómetro, y una línea roja describiendo una pseudofunción del comportamiento de la gráfica. Cada una de las gráficas representa un eje distinto de acción, siendo la primera el eje X, la segunda el eje Y y la última el eje Z. En cada una de las gráficas esta dibujada una recta roja, la cual representa el punto de reposo o base del acelerómetro. Tanto en el eje X como en el Y el punto de reposo se encuentra una recta con función y=0, pero en el eje Z una función y=1. Este último eje, siempre ejerce 1 G de fuerza en estado de reposo ya que es la fuerza que contrapone a la tierra para mantenerse en pie.

\begin{figure}[Puntos de medida]{FIG:scatterFit}{Puntos tomados en funcion de su orientación y en fuerza G. La recta roja indica la representación aproximada de los datos, dirección.}
	\image{0.6\textwidth}{}{scatterFit}
\end{figure}
En la figura \ref{FIG:scatterFit} se pueden observar el conjunto de puntos tomados equivalentes a la figura \ref{FIG:3axisforces} pero representados en funcion de su orientación y de su fuerza, indicando su magnitud en los ejes X e Y. La función aproximada de este conjunto se ve representada por la recta en rojo, con su función indicada en la gráfica.

\begin{figure}[Mapa de calor con y sin zoom]{FIG:MAPACALOR}{Mapa de calor con ampliación en el conjunto de datos y sin zoom, observando la relación con los límites posibles. Figura (a), muestra representación de concentración de puntos delimitados con isobaras. Figura (b), muetra un mapa de calor con escala máxima de +-4 G. Se puede observar que no hay casi variación y la concentración de los puntos está entorno al origen de la gráfica.}
	\image{1\textwidth}{}{graficasMapaCalor}
\end{figure}

En el mapa de calor expuesto en al subfigura \ref{FIG:MAPACALOR}(a) se puede observar la concentración de los datos entorno a +- 0,5 en el eje Y y +-0,5 en el eje X, con una ligera desviación en el margen derecho de la representación. Se puede apreciar que no había apenas viento dado que los datos pueden registrar valores máximos de +- 4 G y aquí solo se aprecia un rango de 0,1 G en ambos ejes.

En gráfica de la subfigura \ref{FIG:MAPACALOR}(a) se han representado la variación de los datos aplicando un zoom para poder apreciar mejor su concentración, no obstante en la subfigura \ref{FIG:MAPACALOR}(b) se representan sin aplicar ningún zoom para apreciar su relación con sus posibles valores máximos y mínimos.

Los datos observados en las gráficas \ref{FIG:MAPACALOR}, \ref{FIG:scatterFit} y \ref{FIG:3axisforces} corresponden al mismo conjunto de datos pero con 4 posibles representaciones.

\begin{figure}[Toma de medidas dividida en planos]{FIG:PLANOSMEDIDAS}{Se muestra los datos medidos en dos planos distintos, coteniendo ambos los vectores de dirección de viento, en los puntos 1,2,3,4 con un foco de viento situado en el punto 0. Se muestra en figura (a) el plano 0 y en la figura (b) el plano 1.}
	\image{1\textwidth}{}{graficasplanoz0z1}
\end{figure}

En la subfigura \ref{FIG:PLANOSMEDIDAS}(a) se observa un conjunto de datos tomados en 4 veces. Este conjunto de datos se ha tomado en el gimnasio IES Valle Inclán ilustrado en el plano \ref{FIG:PLANOGIMNASIO} a una altura de 50 cm. Se puede observar la dirección del viento, proveniente de la pared inferior de 10 m. El foco del viento está situado en el punto 0 representado; aunque en el punto 4 el vector de viento no debería tener esa dirección, la puerta del almacén afectó a la toma de las medidas, creando una circulación de aire desde dicha puerta hasta la puerta principal situada en el centro de la sala.

Al igual que en la subfigura \ref{FIG:PLANOSMEDIDAS}(a) del plano z0, hay una toma de datos para el plano z1 \ref{FIG:PLANOSMEDIDAS}(b) con una altura aproximada de 2,5 m. Se puede observar una dirección similar a la vista en la figura \ref{FIG:PLANOSMEDIDAS}(a).

\begin{figure}[Representación toma de puntos en gimnasio]{FIG:gimnasioPtsReales}{Foto panorámica del gimnasio desde la puerta principal. Puntos de toma de datos representados acorde con las figuras \ref{FIG:PLANOGIMNASIO} y \ref{FIG:mapa3d}.}
	\image{1\textwidth}{}{gimnasioPanoramicaPtsToma}
\end{figure}
En la figura \ref{FIG:gimnasioPtsReales} se indican los puntos de toma de datos con el foco de viento y está representado el eje de coordenadas en la esquina inferior derecha. Estos puntos son los que se han cogido como referencia a la hora de tomar los datos y posteriormente representarlos en las gráficas de esta sección.

\begin{figure}[Mapa de viento 3D]{FIG:mapa3d}{En esta gráfica 3D se representa virtualmente la imagen \ref{FIG:gimnasioPtsReales} concordando los puntos indicados y el foco de viento. Los datos representados en esta figura consolidan el buen funcionamiento del dron con el sensor de viento, sirviendo como base para realizar la toma de medidas en un entorno al aire libre}
	\image{0.8\textwidth}{}{mapa3d2}
\end{figure}
Como se puede observar en la figura \ref{FIG:mapa3d}, en ambos planos aparecen 4 vectores que están enfocando hacia la misma dirección con diferentes módulos, indicando la fuerza del viento en ese punto. Se puede apreciar también la altura que toma el vector, obteniendo así un módulo de acorde a un módulo de 3 componentes, X, Y y Z. La representación de datos obtenidos en un entorno cerrado como es el gimnasio de IES Valle Inclán son muy prometedores, sirviendo como base para llevar a cabo en un futuro mediciones al aire libre y observar su comportamiento en un entorno real.

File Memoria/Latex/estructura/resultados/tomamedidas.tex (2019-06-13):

Se han realizado las tomas de medidas de formas distintas: la primera como una toma única de datos y la segunda como la toma de conjunto de puntos como el descrito en la figura \ref{FIG:PLANOGIMNASIO}.

En ambas tomas de medidas se ha alterado la altura del dron para poder realizar una comparación del viento, a una altura de 0,5 metros (m) del suelo y a 2,5 metros aproximadamente. Cabe indicar que para la toma del conjunto de datos, se ha simulado una matriz en el gimnasio y modificando la posicion del dron para cada una de las tomas de datos, cambiando tanto su posicion en el eje X, Y como Z.

Para las tomas de medidas se ha simulado una corriente de aire con un ventilador; no obstante al ser una circulación de aire tan leve se tuvo que incorporar en la generación del aire, un movimiento mecánico manual de una colchoneta a forma de abanico.

Una vez preparado el escenario, con y sin viento, se procedió a la colocación del dron y a la toma de datos. En una primera prueba se realizaron tomas de datos individuales a varias alturas para familiarizarse con el comportamiento del dron con y sin viento. En las siguientes pruebas se realizaron algunas tomas individuales y un total de 2 pruebas de matrices, con un conjunto de 8 puntos, 4 en un plano y 4 en otro plano. El primer plano se definió a una altura aproximada de 0'50 metros (m) del suelo, mientras que el segundo se situó a una altura aproximada de 2'5 m de altura. 

La forma de tomar los datos con el sensor de viento y el dron, fue iniciada y terminada en vuelo.

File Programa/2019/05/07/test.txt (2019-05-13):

#	dia(1)	hora(1)	gyroX	gyroY	gyroZ	accelX	accelY	accelZ	roll	pitch	yaw	brujula	vientoFG	varianzaRoll	varianzaPitch	direccion	gpsLong	gpsLat	altime	motores(4)	motores(4)	motores(4)	motores(4)
0	2019-05-07	12:26:11	39,0625	13,671875	23,4375	-0,10693359375	-0,069580078125	1,041748046875	-3,675	-5,87	-0,235	N	0,12757813583906585	0	0	null	gpsLong	gpsLat	700	1000	1000	1000	1000
1	2019-05-07	12:26:11	-33,21075439453125	156,22711181640625	-35,21728515625	-0,18994140625	-0,0087890625	1,04296875	-3,615	-3,295	1,378	N	0,19014464343719084	-0,0597331054159671	-2,5751216390436316	SW	gpsLong	gpsLat	700	1000	1000	1000	1000
2	2019-05-07	12:26:11	35,15625	199,2340087890625	134,80377197265625	-0,219482421875	-0,013671875	1,00439453125	-2,775	-7,11	-1,65	N	0,21990782996094319	-0,8397630259404623	3,8152563466796847	SW	gpsLong	gpsLat	700	1000	1000	1000	1000
3	2019-05-07	12:26:11	80,078125	-72,265625	25,4058837890625	-0,045166015625	-0,08544921875	1,05419921875	-3,22	-5,281	0,29	N	0,09665163191805452	0,44504088615781345	-1,8289194103057742	W	gpsLong	gpsLat	700	1000	1000	1000	1000
4	2019-05-07	12:26:12	29,296875	212,88299560546875	-244,1558837890625	-0,07568359375	-0,069091796875	1,053466796875	-3,02	-5,763	-0,059	N	0,10247771835053364	-0,20025807241504268	0,48166060900467844	W	gpsLong	gpsLat	700	1000	1000	1000	1000
5	2019-05-07	12:26:12	105,55267333984375	44,92950439453125	-244,110107421875	-0,317626953125	-0,43798828125	1,99993896484375	1,395	-4,325	-0,496	N	0,5410366123136215	-4,415188135791514	-1,438194687914618	S	gpsLong	gpsLat	700	1000	1000	1000	1000
6	2019-05-07	12:26:12	132,86590576171875	175,74310302734375	-19,561767578125	0,503173828125	0,17724609375	0,862060546875	9,943	12,95	10,116	N	0,5334792208320778	-8,547648519104914	-17,275026330358585	S	gpsLong	gpsLat	700	1000	1000	1000	1000
7	2019-05-07	12:26:12	-31,74591064453125	29,4342041015625	-105,70526123046875	0,671142578125	-0,182861328125	0,83154296875	-19,819	0,869	9,593	N	0,6956080976353788	29,76246728499951	12,081572492681412	N	gpsLong	gpsLat	700	1000	1000	1000	1000
8	2019-05-07	12:26:12	11,90185546875	52,825927734375	-132,40814208984375	0,051513671875	0,06591796875	1,99993896484375	-4,992	10,324	2,651	N	0,08365905207549953	-14,827312235775798	-9,455089354929711	S	gpsLong	gpsLat	700	1000	1000	1000	1000
9	2019-05-07	12:26:12	-15,55633544921875	-175,7965087890625	17,60101318359375	-0,361572265625	0,028076171875	1,0361328125	1,515	12,547	5,268	N	0,3626606881043906	-6,507579281426434	-2,2232619813978314	S	gpsLong	gpsLat	700	1000	1000	1000	1000
10	2019-05-07	12:26:13	-66,7572021484375	234,344482421875	113,4033203125	0,40966796875	1,99993896484375	-0,549072265625	-57,311	8,281	7,446	N	2,0414660682264696	58,82597064783968	4,266484321962064	N	gpsLong	gpsLat	700	1000	1000	1000	1000
11	2019-05-07	12:26:13	-194,915771484375	54,656982421875	-7,74383544921875	0,233154296875	-0,211669921875	1,99993896484375	9,507	12,608	4,397	N	0,3149048776660092	-66,81719213447758	-4,3274903844012815	S	gpsLong	gpsLat	700	1000	1000	1000	1000
12	2019-05-07	12:26:13	95,733642578125	-54,6875	-138,64898681640625	0,321533203125	0,372314453125	0,548828125	-5,307	10,89	6,958	N	0,4919366348602128	14,813720520757254	1,7185905817089058	N	gpsLong	gpsLat	700	1000	1000	1000	1000
13	2019-05-07	12:26:13	248,54278564453125	-169,96002197265625	-7,88116455078125	0,1572265625	0,592529296875	0,6806640625	-25,88	13,776	9,338	N	0,6130343869724996	20,572897255027435	-2,886690133389642	W	gpsLong	gpsLat	700	1000	1000	1000	1000
14	2019-05-07	12:26:13	-134,9029541015625	105,50689697265625	11,7034912109375	0,74365234375	0,31396484375	0,944091796875	-3,912	13,208	7,336	N	0,807212940602311	-21,967562528941034	0,5686051933846841	W	gpsLong	gpsLat	700	1000	1000	1000	1000
15	2019-05-07	12:26:13	146,53778076171875	-205,11627197265625	13,671875	0,486572265625	0,0341796875	1,180419921875	7,557	14,271	4,711	N	0,4877712790981478	-11,469704092134975	-1,0629402180341252	S	gpsLong	gpsLat	700	1000	1000	1000	1000
16	2019-05-07	12:26:13	-37,19329833984375	238,39569091796875	244,0338134765625	-0,170654296875	-1,092041015625	1,56591796875	-21,087	11,269	16,309	NE	1,1052947429754572	28,643862581694776	3,001647232817948	N	gpsLong	gpsLat	700	1000	1000	1000	1000
17	2019-05-07	12:26:14	-89,752197265625	81,99310302734375	156,2347412109375	0,18408203125	0,142822265625	0,28369140625	-11,631	-3,662	3,852	N	0,23299011521389493	-9,455173578139418	14,930655348390804	N	gpsLong	gpsLat	700	1000	1000	1000	1000
18	2019-05-07	12:26:14	-83,96148681640625	-42,96875	-236,297607421875	0,227783203125	-0,228271484375	1,138916015625	1,72	2,257	2,94	N	0,3224795469555409	-13,351545171859298	-5,918888597580601	S	gpsLong	gpsLat	700	1000	1000	1000	1000
19	2019-05-07	12:26:14	95,69549560546875	-35,14862060546875	-58,563232421875	-0,15185546875	-0,158203125	0,975341796875	-0,747	0,75	0,649	N	0,21929047436915233	2,4670914110504794	1,5073310279016598	N	gpsLong	gpsLat	700	1000	1000	1000	1000
20	2019-05-07	12:26:14	232,4371337890625	-121,08612060546875	-68,359375	-0,064697265625	-0,247802734375	1,064208984375	-0,939	-0,513	-2,251	N	0,25610921760662697	0,19188218670982748	1,2627061972808185	N	gpsLong	gpsLat	700	1000	1000	1000	1000
21	2019-05-07	12:26:14	246,124267578125	66,4215087890625	181,69403076171875	-0,03271484375	-0,0205078125	0,889892578125	-7,161	-0,549	-0,664	N	0,03861128559271331	6,22226510832987	0,036153319896895186	NW	gpsLong	gpsLat	700	1000	1000	1000	1000
22	2019-05-07	12:26:14	-166,0308837890625	187,50762939453125	-1,99127197265625	-0,097900390625	-0,266357421875	1,158203125	-2,987	-4,407	-3,658	N	0,28377942609080087	-4,174451825133738	3,857721358879314	NW	gpsLong	gpsLat	700	1000	1000	1000	1000
23	2019-05-07	12:26:14	-146,49200439453125	-242,13409423828125	25,48980712890625	-0,44384765625	-0,0166015625	1,287841796875	15,999	1,076	-1,315	N	0,4441580279991116	-18,985671526656844	-5,482663218992211	S	gpsLong	gpsLat	700	1000	1000	1000	1000
24	2019-05-07	12:26:15	-209,15985107421875	-228,546142578125	70,30487060546875	-0,044677734375	0,468994140625	0,9892578125	-2,766	1,671	-0,557	N	0,4711173992642018	18,764785201973325	-0,5954863187918771	W	gpsLong	gpsLat	700	1000	1000	1000	1000
25	2019-05-07	12:26:15	240,234375	54,67987060546875	-232,4066162109375	-0,111572265625	-0,155517578125	1,210693359375	1,651	5,468	0,571	N	0,1914003332352403	-4,4168783943952725	-3,7964321138973913	S	gpsLong	gpsLat	700	1000	1000	1000	1000
26	2019-05-07	12:26:15	52,764892578125	-193,359375	125,0	0,33349609375	0,05517578125	1,080078125	-0,886	4,37	1,973	N	0,3380296013414456	2,5372213760551596	1,0977981591744452	N	gpsLong	gpsLat	700	1000	1000	1000	1000
27	2019-05-07	12:26:15	-105,3466796875	-222,869873046875	68,1304931640625	0,730224609375	-0,8046875	1,61181640625	22,44	11,36	2,122	N	1,0866231880431787	-23,325632651408494	-6,989576322215188	S	gpsLong	gpsLat	700	1000	1000	1000	1000
28	2019-05-07	12:26:15	246,16241455078125	222,60284423828125	-11,72637939453125	0,637939453125	0,288330078125	0,810546875	9,33	23,072	8,323	N	0,7000721247164414	13,10908730244064	-11,712070684327426	W	gpsLong	gpsLat	700	1000	1000	1000	1000
29	2019-05-07	12:26:15	-56,63299560546875	-175,750732421875	-175,6744384765625	0,44677734375	0,265625	0,853759765625	5,852	21,451	0,318	N	0,5197755626357454	3,4787787273253716	1,6205093393423482	N	gpsLong	gpsLat	700	1000	1000	1000	1000
30	2019-05-07	12:26:15	160,15625	115,17333984375	-123,077392578125	0,376220703125	-0,075927734375	1,05322265625	4,753	23,904	-8,826	N	0,38380599045245495	1,0983210155513596	-2,4525192540047094	W	gpsLong	gpsLat	700	1000	1000	1000	1000
31	2019-05-07	12:26:16	88,12713623046875	156,33392333984375	-15,64788818359375	-1,1865234375	-0,069091796875	1,596435546875	23,387	-12,675	-27,778	NW	1,1885333584431834	-18,634005408859057	36,57909598932572	W	gpsLong	gpsLat	700	1000	1000	1000	1000
32	2019-05-07	12:26:16	-244,415283203125	169,830322265625	-31,3262939453125	-0,99462890625	0,6142578125	1,10498046875	-6,789	11,998	-19,583	NW	1,1690163905460678	30,176651552834283	-24,673156807903105	W	gpsLong	gpsLat	700	1000	1000	1000	1000
33	2019-05-07	12:26:16	-144,287109375	-77,67486572265625	-210,65521240234375	-0,31591796875	0,0810546875	0,80078125	25,247	-24,254	-21,473	NW	0,32615031096849906	-32,03588942166233	36,25193743727779	W	gpsLong	gpsLat	700	1000	1000	1000	1000
34	2019-05-07	12:26:16	220,5047607421875	177,37579345703125	-105,56793212890625	0,000732421875	0,103759765625	1,53271484375	15,807	2,328	-15,664	NW	0,10376235061118223	9,439460079792235	-26,582333818979123	W	gpsLong	gpsLat	700	1000	1000	1000	1000
35	2019-05-07	12:26:16	-208,9385986328125	125,06103515625	60,55450439453125	1,578125	0,260009765625	0,583740234375	-1,844	29,526	-1,612	N	1,5994010109554662	17,651595929019958	-27,19792968639834	W	gpsLong	gpsLat	700	1000	1000	1000	1000
36	2019-05-07	12:26:16	119,05670166015625	-220,86334228515625	-82,122802734375	0,101806640625	-0,70556640625	0,680908203125	1,674	-12,102	-13,789	NW	0,7128734429784069	-3,518503008085931	41,62818023936509	W	gpsLong	gpsLat	700	1000	1000	1000	1000
37	2019-05-07	12:26:16	-220,6573486328125	84,05303955078125	-213,18817138671875	1,475341796875	0,173095703125	1,42919921875	1,825	27,036	-0,89	N	1,4854613896182869	-0,15138381104173781	-39,13790395876843	S	gpsLong	gpsLat	700	1000	1000	1000	1000
38	2019-05-07	12:26:17	56,640625	246,1395263671875	-125,03814697265625	0,84765625	0,040283203125	1,0517578125	4,07	27,164	-1,235	N	0,8486129003368217	-2,2444082074478087	-0,12863256425246306	S	gpsLong	gpsLat	700	1000	1000	1000	1000
39	2019-05-07	12:26:17	-83,953857421875	-132,71331787109375	-126,89971923828125	0,77392578125	-0,087158203125	0,99560546875	3,986	27,31	-2,512	N	0,7788181220640681	0,08424678072864955	-0,14577558328399576	SW	gpsLong	gpsLat	700	1000	1000	1000	1000
40	2019-05-07	12:26:17	85,9222412109375	-19,7601318359375	195,13702392578125	0,02685546875	0,1142578125	0,473876953125	-12,653	2,468	-3,138	N	0,11737147830315244	16,638904062021982	24,84216763019913	N	gpsLong	gpsLat	700	1000	1000	1000	1000
41	2019-05-07	12:26:17	173,7518310546875	-199,1729736328125	226,67694091796875	0,491455078125	-0,014892578125	1,1953125	7,454	19,007	-1,247	N	0,49168067147088373	-20,107015316923757	-16,538814608186414	S	gpsLong	gpsLat	700	1000	1000	1000	1000
42	2019-05-07	12:26:17	103,15704345703125	33,050537109375	185,1959228515625	0,89599609375	0,6123046875	1,93115234375	-6,902	20,956	11,506	NE	1,0852308650004991	14,356048678512213	-1,9491910009542508	W	gpsLong	gpsLat	700	1000	1000	1000	1000
43	2019-05-07	12:26:17	199,34844970703125	58,59375	-222,7783203125	1,99993896484375	-0,64208984375	1,99993896484375	12,423	28,641	10,163	N	2,1004845228059144	-19,325826689248686	-7,684462412453723	S	gpsLong	gpsLat	700	1000	1000	1000	1000
44	2019-05-07	12:26:17	193,0389404296875	224,5635986328125	-185,6536865234375	0,801025390625	1,99993896484375	-0,363525390625	-15,713	27,277	23,097	NE	2,154390294149652	28,136899720939553	1,363108155062406	N	gpsLong	gpsLat	700	1000	1000	1000	1000
45	2019-05-07	12:26:18	208,94622802734375	-113,34228515625	-195,50323486328125	0,7509765625	-0,254150390625	1,989013671875	12,72	29,946	6,638	N	0,7928166361014106	-28,433916072416366	-2,6682401506568993	S	gpsLong	gpsLat	700	1000	1000	1000	1000
46	2019-05-07	12:26:18	80,14678955078125	7,8582763671875	-93,658447265625	0,44287109375	0,03515625	1,05224609375	7,993	23,919	6,039	N	0,44426429925595395	4,727972495608891	6,026452653673836	N	gpsLong	gpsLat	700	1000	1000	1000	1000
47	2019-05-07	12:26:18	228,50799560546875	-236,28997802734375	127,00653076171875	0,272705078125	0,05615234375	0,9580078125	2,206	10,235	-3,131	N	0,27842619370989596	5,786441568074184	13,684556751961697	N	gpsLong	gpsLat	700	1000	1000	1000	1000
48	2019-05-07	12:26:18	-85,9375	132,904052734375	152,58026123046875	-0,19580078125	0,19580078125	1,08251953125	2,312	-4,988	-21,97	NW	0,27690412036699763	-0,10615239462786352	15,222247361622017	N	gpsLong	gpsLat	700	1000	1000	1000	1000
49	2019-05-07	12:26:18	164,08538818359375	181,6864013671875	-158,1573486328125	-0,1611328125	-0,1103515625	0,96044921875	30,686	-31,761	-36,986	W	0,1952978510131424	-28,37349863754044	26,773502992163472	N	gpsLong	gpsLat	700	1000	1000	1000	1000
50	2019-05-07	12:26:18	-179,6875	-11,810302734375	11,6424560546875	-0,09423828125	0,2705078125	1,353271484375	18,643	-24,502	-32,576	NW	0,2864530158271846	12,042256636128712	-7,258677791260627	W	gpsLong	gpsLat	700	1000	1000	1000	1000
51	2019-05-07	12:26:18	-6,0577392578125	39,0167236328125	77,8656005859375	1,265380859375	0,751953125	0,760009765625	9,93	36,339	17,244	NE	1,4719450470278703	8,713693480931394	-60,84108075349363	W	gpsLong	gpsLat	700	1000	1000	1000	1000
52	2019-05-07	12:26:19	195,343017578125	166,19110107421875	-142,38739013671875	0,4462890625	-0,079833984375	1,32861328125	3,887	20,443	0,037	N	0,45337334765986925	6,042330703862757	15,895236335693376	N	gpsLong	gpsLat	700	1000	1000	1000	1000
53	2019-05-07	12:26:19	-23,55194091796875	3,875732421875	-31,1737060546875	-1,0888671875	0,325927734375	0,019287109375	14,546	-35,298	-47,676	W	1,1366004751226266	-10,65823016288639	55,74150171972571	N	gpsLong	gpsLat	700	1000	1000	1000	1000
54	2019-05-07	12:26:19	48,74420166015625	-113,85345458984375	102,56195068359375	-1,2705078125	0,611572265625	0,516845703125	-12,105	-5,106	-16,021	NW	1,4100392681429943	26,650266899820707	-30,192496693302843	W	gpsLong	gpsLat	700	1000	1000	1000	1000
55	2019-05-07	12:26:19	-195,281982421875	21,5606689453125	-50,69732666015625	1,251953125	0,08056640625	1,052734375	2,065	42,773	4,926	N	1,2545427744853126	-14,169621470926483	-47,878846395060854	S	gpsLong	gpsLat	700	1000	1000	1000	1000
56	2019-05-07	12:26:19	64,46075439453125	226,9744873046875	18,2647705078125	0,593505859375	0,58056640625	0,661376953125	-8,538	-26,131	-31,388	NW	0,8302448778393621	10,603283923929832	68,9038564328198	N	gpsLong	gpsLat	700	1000	1000	1000	1000
57	2019-05-07	12:26:19	-68,32122802734375	189,46075439453125	222,6409912109375	-0,3203125	0,35107421875	0,697509765625	17,397	-44,564	-53,062	W	0,4752401547924721	-25,935159338393078	18,433132257514167	N	gpsLong	gpsLat	700	1000	1000	1000	1000
58	2019-05-07	12:26:20	-85,92987060546875	-60,63079833984375	54,4586181640625	-0,42724609375	0,213134765625	0,800537109375	1,036	-41,008	-38,596	W	0,4774574880998909	16,36137689352692	-3,5555685123441236	W	gpsLong	gpsLat	700	1000	1000	1000	1000
59	2019-05-07	12:26:20	-169,9371337890625	148,4375	208,953857421875	-0,2744140625	-0,042236328125	1,018310546875	-13,581	-15,666	-19,96	NW	0,2776454305607002	14,6161141500797	-25,342533074833213	W	gpsLong	gpsLat	700	1000	1000	1000	1000
60	2019-05-07	12:26:20	-52,75726318359375	-115,5548095703125	-41,60308837890625	0,57470703125	-0,360595703125	0,605224609375	-5,217	29,752	10,433	N	0,6784669725789175	-8,363549909189846	-45,417396807756205	S	gpsLong	gpsLat	700	1000	1000	1000	1000
61	2019-05-07	12:26:20	224,61700439453125	13,75579833984375	-34,942626953125	0,514892578125	0,064453125	0,623046875	-16,312	3,837	-4,422	N	0,5189109483625055	11,094525980908596	25,914462896038394	N	gpsLong	gpsLat	700	1000	1000	1000	1000
62	2019-05-07	12:26:20	-182,0526123046875	-197,0062255859375	25,299072265625	-0,94873046875	-1,167724609375	1,99993896484375	-23,645	-12,846	-10,771	N	1,5045498548318668	7,33346812300055	16,683441232672937	N	gpsLong	gpsLat	700	1000	1000	1000	1000
63	2019-05-07	12:26:20	224,8077392578125	-150,62713623046875	-238,800048828125	0,484619140625	0,637939453125	0,99365234375	-16,52	12,923	3,883	N	0,8011382260968063	-7,124694257391933	-25,769224507514814	S	gpsLong	gpsLat	700	1000	1000	1000	1000
64	2019-05-07	12:26:20	-183,61663818359375	244,1558837890625	-15,56396484375	-0,009033203125	-2,0	-0,59521484375	-9,229	11,697	-0,609	N	2,0000203995856385	-7,291503556111582	1,2260126271669396	S	gpsLong	gpsLat	700	1000	1000	1000	1000
65	2019-05-07	12:26:21	197,42584228515625	205,02471923828125	70,281982421875	0,31005859375	-0,24560546875	1,335693359375	-4,693	15,199	0,62	N	0,3955481991339801	-4,535666488569003	-3,5014647792174873	S	gpsLong	gpsLat	700	1000	1000	1000	1000
66	2019-05-07	12:26:21	5,859375	210,9527587890625	193,4051513671875	0,30322265625	0,263427734375	0,786376953125	-10,606	14,662	1,106	N	0,4016692053185696	5,91253753625308	0,5365449233333912	N	gpsLong	gpsLat	700	1000	1000	1000	1000
67	2019-05-07	12:26:21	246,07086181640625	-169,8150634765625	45,074462890625	-0,409423828125	0,163330078125	0,98046875	-3,429	-9,983	-17,625	NW	0,4407999381316292	-7,17654719558505	24,645165827749672	N	gpsLong	gpsLat	700	1000	1000	1000	1000
68	2019-05-07	12:26:21	-220,76416015625	-68,2830810546875	127,166748046875	-0,138671875	-0,028564453125	0,953369140625	2,41	-27,502	-34,221	W	0,14158325076910033	-5,839204961257476	17,518378254194864	N	gpsLong	gpsLat	700	1000	1000	1000	1000
69	2019-05-07	12:26:21	111,328125	95,71075439453125	-48,82049560546875	-0,349609375	0,16455078125	0,9658203125	6,53	-22,723	-45,654	W	0,3863983368207943	-4,119559356562708	-4,778612333893076	S	gpsLong	gpsLat	700	1000	1000	1000	1000
70	2019-05-07	12:26:21	-54,64935302734375	1,94549560546875	-242,30194091796875	-0,247314453125	0,182861328125	0,880615234375	8,564	-23,549	-35,721	W	0,30757552576262753	-2,034148132625364	0,826578563421478	S	gpsLong	gpsLat	700	1000	1000	1000	1000
71	2019-05-07	12:26:21	1,94549560546875	238,1744384765625	46,69189453125	0,15185546875	0,03515625	1,018798828125	-1,729	8,488	-4,365	N	0,15587188746962913	10,292885788829977	-32,03739143567986	W	gpsLong	gpsLat	700	1000	1000	1000	1000
72	2019-05-07	12:26:22	-113,30413818359375	-99,609375	-0,0152587890625	0,2236328125	0,01708984375	0,93798828125	-1,604	16,015	3,539	N	0,22428485812925394	-0,125062003320205	-7,527267408617794	S	gpsLong	gpsLat	700	1000	1000	1000	1000
73	2019-05-07	12:26:22	-158,25653076171875	193,29071044921875	-142,6544189453125	0,61669921875	0,323486328125	0,855224609375	-2,944	19,913	7,271	N	0,6963916505032607	1,3394778772828428	-3,8981639757795072	W	gpsLong	gpsLat	700	1000	1000	1000	1000
74	2019-05-07	12:26:22	54,75616455078125	-173,919677734375	-9,92584228515625	0,43701171875	0,759521484375	0,8212890625	24,629	8,478	-10,023	N	0,8762717201599242	-27,572529524086374	11,435179040677866	W	gpsLong	gpsLat	700	1000	1000	1000	1000
75	2019-05-07	12:26:22	234,41314697265625	249,969482421875	212,91351318359375	0,22705078125	0,71044921875	0,5712890625	47,975	20,1	-13,071	NW	0,7458486104356036	-23,345609603931155	-11,622291439220323	S	gpsLong	gpsLat	700	1000	1000	1000	1000
76	2019-05-07	12:26:22	85,67047119140625	74,432373046875	15,38848876953125	0,522705078125	1,085205078125	1,99993896484375	12,17	-15,024	-12,178	NW	1,2045292276594826	35,80438593048816	35,12486838945563	N	gpsLong	gpsLat	700	1000	1000	1000	1000
77	2019-05-07	12:26:22	99,78485107421875	-189,4378662109375	-118,9727783203125	0,15771484375	1,182373046875	0,951904296875	11,909	4,928	-11,766	NW	1,1928453352868333	0,26108207036419984	-19,95218258141586	W	gpsLong	gpsLat	700	1000	1000	1000	1000
78	2019-05-07	12:26:22	-140,60211181640625	-189,53704833984375	-128,875732421875	-0,107666015625	0,0947265625	0,659912109375	59,593	30,326	-14,831	NW	0,14340534356720866	-47,68411602842781	-25,398007527317333	S	gpsLong	gpsLat	700	1000	1000	1000	1000
79	2019-05-07	12:26:23	54,5806884765625	240,36407470703125	74,249267578125	-0,88525390625	0,028076171875	1,431884765625	52,149	30,998	-14,232	NW	0,8856990177018592	7,444723401224294	-0,6717955103426512	W	gpsLong	gpsLat	700	1000	1000	1000	1000
80	2019-05-07	12:26:23	212,860107421875	-140,7470703125	134,58251953125	0,306884765625	0,396240234375	0,780029296875	4,146	9,048	-3,11	N	0,5011831827887545	48,00215293022696	21,949393697793173	N	gpsLong	gpsLat	700	1000	1000	1000	1000
81	2019-05-07	12:26:23	189,59808349609375	-175,74310302734375	-66,2384033203125	-0,0693359375	1,43359375	0,327392578125	13,551	11,1	-9,468	N	1,4352694911646615	-9,40505546963155	-2,0517438671033688	S	gpsLong	gpsLat	700	1000	1000	1000	1000
82	2019-05-07	12:26:23	230,4534912109375	101,64642333984375	242,12646484375	0,17138671875	0,413818359375	0,861083984375	33,461	14,395	-18,294	NW	0,44790517067757574	-19,909878391173578	-3,295503517245818	S	gpsLong	gpsLat	700	1000	1000	1000	1000
83	2019-05-07	12:26:23	74,1729736328125	-70,3125	-68,32122802734375	-0,220458984375	0,56396484375	0,857666015625	21,783	17,538	-15,487	NW	0,6055233346268486	11,67847485387869	-3,1426450493257843	W	gpsLong	gpsLat	700	1000	1000	1000	1000
84	2019-05-07	12:26:23	46,875	-95,68023681640625	33,172607421875	0,2314453125	0,084228515625	0,97998046875	14,991	-29,901	-22,993	NW	0,24629530146272285	6,791514890440698	47,43881230733585	N	gpsLong	gpsLat	700	1000	1000	1000	1000
85	2019-05-07	12:26:23	-242,04254150390625	-84,17510986328125	83,91571044921875	0,291748046875	0,341552734375	1,113037109375	11,961	-8,826	-15,269	NW	0,4491939371968599	3,0303901831208186	-21,07514184807531	W	gpsLong	gpsLat	700	1000	1000	1000	1000
86	2019-05-07	12:26:24	-238,250732421875	37,10174560546875	164,0472412109375	0,22021484375	0,452880859375	0,85791015625	17,373	15,16	-9,006	N	0,5035828136424787	-5,412039311681681	-23,985601147957347	S	gpsLong	gpsLat	700	1000	1000	1000	1000
87	2019-05-07	12:26:24	164,306640625	-107,513427734375	-58,4869384765625	-0,425048828125	0,06298828125	1,89990234375	17,442	11,357	-8,503	N	0,42969062110460926	-0,0692090741334006	3,8029247284049017	S	gpsLong	gpsLat	700	1000	1000	1000	1000
88	2019-05-07	12:26:24	-246,29974365234375	-148,3917236328125	-197,4639892578125	0,630859375	1,205810546875	0,796875	-2,553	-1,185	-9,036	N	1,3608683352846362	19,994791742280107	12,541568867106996	N	gpsLong	gpsLat	700	1000	1000	1000	1000
89	2019-05-07	12:26:24	11,69586181640625	7,843017578125	-234,5428466796875	0,392333984375	0,288818359375	0,81298828125	14,835	15,845	-6,674	N	0,4871775856991261	-17,387303120874133	-17,02989877274883	S	gpsLong	gpsLat	700	1000	1000	1000	1000
90	2019-05-07	12:26:24	27,39715576171875	-183,55560302734375	-46,81396484375	-0,338134765625	-0,04833984375	1,677001953125	17,484	19,221	-11,612	NW	0,3415726280281371	-2,6490816012295646	-3,375929451298319	S	gpsLong	gpsLat	700	1000	1000	1000	1000
91	2019-05-07	12:26:24	-9,613037109375	-220,78704833984375	60,47821044921875	-0,854248046875	-1,080078125	1,720947265625	6,799	4,568	-6,8	N	1,3770651697335416	10,685122666805	14,653630356236128	N	gpsLong	gpsLat	700	1000	1000	1000	1000
92	2019-05-07	12:26:24	-185,58502197265625	-212,89825439453125	-154,3426513671875	0,07470703125	-0,1259765625	0,89208984375	-13,667	-3,676	-6,201	N	0,14646240069555355	20,46563086747973	8,243740315661448	N	gpsLong	gpsLat	700	1000	1000	1000	1000
93	2019-05-07	12:26:25	44,98291015625	-91,796875	-95,6268310546875	0,150390625	-0,315185546875	1,466552734375	4,498	3,61	-6,743	N	0,34922667287419995	-18,164887713885033	-7,28609904786028	S	gpsLong	gpsLat	700	1000	1000	1000	1000
94	2019-05-07	12:26:25	52,703857421875	62,52288818359375	173,77471923828125	0,235107421875	0,234619140625	1,062255859375	10,875	1,324	-14,494	NW	0,332147017099842	-6,3767617875072435	2,2860132044391595	S	gpsLong	gpsLat	700	1000	1000	1000	1000
95	2019-05-07	12:26:25	21,484375	130,92803955078125	162,20855712890625	0,0009765625	0,251708984375	0,946533203125	11,662	-4,723	-22,521	NW	0,2517108787665134	-0,7876407398334546	6,047411572499013	S	gpsLong	gpsLat	700	1000	1000	1000	1000
96	2019-05-07	12:26:25	-17,61627197265625	-189,38446044921875	76,30157470703125	-0,5224609375	0,276611328125	0,879150390625	15,198	-25,077	-49,81	W	0,5911677072205952	-3,536069989873333	20,353740528650825	S	gpsLong	gpsLat	700	1000	1000	1000	1000
97	2019-05-07	12:26:25	11,71875	232,421875	132,82012939453125	-0,46337890625	0,35791015625	0,86767578125	18,67	-26,821	-56,316	SW	0,5855080620318952	-3,4718301586311213	1,7443785255400037	S	gpsLong	gpsLat	700	1000	1000	1000	1000
98	2019-05-07	12:26:25	91,7816162109375	44,47174072265625	184,7686767578125	-1,28271484375	0,644775390625	0,638916015625	-0,006	-7,895	-31,099	NW	1,4356506102573174	18,676548688359954	-18,926744599604252	W	gpsLong	gpsLat	700	1000	1000	1000	1000
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

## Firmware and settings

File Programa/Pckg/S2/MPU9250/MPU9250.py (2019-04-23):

# coding: utf-8
## @package MPU9250
#  This is a FaBo9Axis_MPU9250 library for the FaBo 9AXIS I2C Brick.
#
#  http://fabo.io/202.html
#
#  Released under APACHE LICENSE, VERSION 2.0
#
#  http://www.apache.org/licenses/
#
#  FaBo <info@fabo.io>

import smbus
import time

## MPU9250 Default I2C slave address
SLAVE_ADDRESS        = 0x68
## AK8963 I2C slave address
AK8963_SLAVE_ADDRESS = 0x0C
## Device id
DEVICE_ID            = 0x71

''' MPU-9250 Register Addresses '''
## sample rate driver
SMPLRT_DIV     = 0x19
CONFIG         = 0x1A
GYRO_CONFIG    = 0x1B
ACCEL_CONFIG   = 0x1C
ACCEL_CONFIG_2 = 0x1D
LP_ACCEL_ODR   = 0x1E
WOM_THR        = 0x1F
FIFO_EN        = 0x23
I2C_MST_CTRL   = 0x24
I2C_MST_STATUS = 0x36
INT_PIN_CFG    = 0x37
INT_ENABLE     = 0x38
INT_STATUS     = 0x3A
ACCEL_OUT      = 0x3B
TEMP_OUT       = 0x41
GYRO_OUT       = 0x43

I2C_MST_DELAY_CTRL = 0x67
SIGNAL_PATH_RESET  = 0x68
MOT_DETECT_CTRL    = 0x69
USER_CTRL          = 0x6A
PWR_MGMT_1         = 0x6B
PWR_MGMT_2         = 0x6C
FIFO_R_W           = 0x74
WHO_AM_I           = 0x75

## Gyro Full Scale Select 250dps
GFS_250  = 0x00
## Gyro Full Scale Select 500dps
GFS_500  = 0x01
## Gyro Full Scale Select 1000dps
GFS_1000 = 0x02
## Gyro Full Scale Select 2000dps
GFS_2000 = 0x03
## Accel Full Scale Select 2G
AFS_2G   = 0x00
## Accel Full Scale Select 4G
AFS_4G   = 0x01
## Accel Full Scale Select 8G
AFS_8G   = 0x02
## Accel Full Scale Select 16G
AFS_16G  = 0x03

# AK8963 Register Addresses
AK8963_ST1        = 0x02
AK8963_MAGNET_OUT = 0x03
AK8963_CNTL1      = 0x0A
AK8963_CNTL2      = 0x0B
AK8963_ASAX       = 0x10

# CNTL1 Mode select
## Power down mode
AK8963_MODE_DOWN   = 0x00
## One shot data output
AK8963_MODE_ONE    = 0x01

## Continous data output 8Hz
AK8963_MODE_C8HZ   = 0x02
## Continous data output 100Hz
AK8963_MODE_C100HZ = 0x06

# Magneto Scale Select
## 14bit output
AK8963_BIT_14 = 0x00
## 16bit output
AK8963_BIT_16 = 0x01

## smbus
bus = smbus.SMBus(1)

## MPU9250 I2C Controll class
class MPU9250:

    INIgyroX = 0
    INIgyroY = 0
    INIgyroZ = 0
    gyroX = 0
    gyroY = 0
    gyroZ = 0


    ## Constructor
    #  @param [in] address MPU-9250 I2C slave address default:0x68
    def __init__(self, address=SLAVE_ADDRESS):
        self.address = address
        self.configMPU9250(GFS_250, AFS_2G)
        self.configAK8963(AK8963_MODE_C8HZ, AK8963_BIT_16)

    ## Search Device
    #  @param [in] self The object pointer.
    #  @retval true device connected
    #  @retval false device error
    def searchDevice(self):
        who_am_i = bus.read_byte_data(self.address, WHO_AM_I)
        if(who_am_i == DEVICE_ID):
            return true
        else:
            return false

    ## Configure MPU-9250
    #  @param [in] self The object pointer.
    #  @param [in] gfs Gyro Full Scale Select(default:GFS_250[+250dps])
    #  @param [in] afs Accel Full Scale Select(default:AFS_2G[2g])
    def configMPU9250(self, gfs, afs):
        if gfs == GFS_250:
            self.gres = 250.0/32768.0
        elif gfs == GFS_500:
            self.gres = 500.0/32768.0
        elif gfs == GFS_1000:
            self.gres = 1000.0/32768.0
        else:  # gfs == GFS_2000
            self.gres = 2000.0/32768.0

        if afs == AFS_2G:
            self.ares = 2.0/32768.0
        elif afs == AFS_4G:
            self.ares = 4.0/32768.0
        elif afs == AFS_8G:
            self.ares = 8.0/32768.0
        else: # afs == AFS_16G:
            self.ares = 16.0/32768.0

        # sleep off
        bus.write_byte_data(self.address, PWR_MGMT_1, 0x00)
        time.sleep(0.1)
        # auto select clock source
        bus.write_byte_data(self.address, PWR_MGMT_1, 0x01)
        time.sleep(0.1)
        # DLPF_CFG
        bus.write_byte_data(self.address, CONFIG, 0x03)
        # sample rate divider
        bus.write_byte_data(self.address, SMPLRT_DIV, 0x04)
        # gyro full scale select
        bus.write_byte_data(self.address, GYRO_CONFIG, gfs << 3)
        # accel full scale select
        bus.write_byte_data(self.address, ACCEL_CONFIG, afs << 3)
        # A_DLPFCFG
        bus.write_byte_data(self.address, ACCEL_CONFIG_2, 0x03)
        # BYPASS_EN
        bus.write_byte_data(self.address, INT_PIN_CFG, 0x02)
        time.sleep(0.1)

    ## Configure AK8963
    #  @param [in] self The object pointer.
    #  @param [in] mode Magneto Mode Select(default:AK8963_MODE_C8HZ[Continous 8Hz])
    #  @param [in] mfs Magneto Scale Select(default:AK8963_BIT_16[16bit])
    def configAK8963(self, mode, mfs):
        if mfs == AK8963_BIT_14:
            self.mres = 4912.0/8190.0
        else: #  mfs == AK8963_BIT_16:
            self.mres = 4912.0/32760.0

        bus.write_byte_data(AK8963_SLAVE_ADDRESS, AK8963_CNTL1, 0x00)
        time.sleep(0.01)

        # set read FuseROM mode
        bus.write_byte_data(AK8963_SLAVE_ADDRESS, AK8963_CNTL1, 0x0F)
        time.sleep(0.01)

        # read coef data
        data = bus.read_i2c_block_data(AK8963_SLAVE_ADDRESS, AK8963_ASAX, 3)

        self.magXcoef = (data[0] - 128) / 256.0 + 1.0
        self.magYcoef = (data[1] - 128) / 256.0 + 1.0
        self.magZcoef = (data[2] - 128) / 256.0 + 1.0

        # set power down mode
        bus.write_byte_data(AK8963_SLAVE_ADDRESS, AK8963_CNTL1, 0x00)
        time.sleep(0.01)

        # set scale&continous mode
        bus.write_byte_data(AK8963_SLAVE_ADDRESS, AK8963_CNTL1, (mfs<<4|mode))
        time.sleep(0.01)

    ## brief Check data ready
    #  @param [in] self The object pointer.
    #  @retval true data is ready
    #  @retval false data is not ready
    def checkDataReady(self):
        drdy = bus.read_byte_data(self.address, INT_STATUS)
        if drdy & 0x01:
            return True
        else:
            return False

    ## Read accelerometer
    #  @param [in] self The object pointer.
    #  @retval x : x-axis data
    #  @retval y : y-axis data
    #  @retval z : z-axis data
    def readAccel(self):
        data = bus.read_i2c_block_data(self.address, ACCEL_OUT, 6)
        x = self.dataConv(data[1], data[0])
        y = self.dataConv(data[3], data[2])
        z = self.dataConv(data[5], data[4])

        x = round(x*self.ares, 3)
        y = round(y*self.ares, 3)
        z = round(z*self.ares, 3)

        return {"x":x, "y":y, "z":z}

    ## Read gyro
    #  @param [in] self The object pointer.
    #  @retval x : x-gyro data
    #  @retval y : y-gyro data
    #  @retval z : z-gyro data
    def readGyro(self):
        data = bus.read_i2c_block_data(self.address, GYRO_OUT, 6)

        x = self.dataConv(data[1], data[0])
        y = self.dataConv(data[3], data[2])
        z = self.dataConv(data[5], data[4])

        x = round(x*self.gres, 3)
        y = round(y*self.gres, 3)
        z = round(z*self.gres, 3)

        return {"x":x, "y":y, "z":z}

    ## Read magneto
    #  @param [in] self The object pointer.
    #  @retval x : X-magneto data
    #  @retval y : y-magneto data
    #  @retval z : Z-magneto data
    def readMagnet(self):
        x=0
        y=0
        z=0

        # check data ready
        drdy = bus.read_byte_data(AK8963_SLAVE_ADDRESS, AK8963_ST1)
        if drdy & 0x01 :
            data = bus.read_i2c_block_data(AK8963_SLAVE_ADDRESS, AK8963_MAGNET_OUT, 7)

            # check overflow
            if (data[6] & 0x08)!=0x08:
                x = self.dataConv(data[0], data[1])
                y = self.dataConv(data[2], data[3])
                z = self.dataConv(data[4], data[5])

                x = round(x * self.mres * self.magXcoef, 3)
                y = round(y * self.mres * self.magYcoef, 3)
                z = round(z * self.mres * self.magZcoef, 3)

        return {"x":x, "y":y, "z":z}

    ## Read temperature
    #  @param [out] temperature temperature(degrees C)
    def readTemperature(self):
        data = bus.read_i2c_block_data(self.address, TEMP_OUT, 2)
        temp = self.dataConv(data[1], data[0])

        temp = round((temp / 333.87 + 21.0), 3)
        return temp

    ## Data Convert
    # @param [in] self The object pointer.
    # @param [in] data1 LSB
    # @param [in] data2 MSB
    # @retval Value MSB+LSB(int 16bit)
    def dataConv(self, data1, data2):
        value = data1 | (data2 << 8)
        if(value & (1 << 16 - 1)):
            value -= (1<<16)
        return value

    def calibrarGyro(self):
        gyro = self.readGyro()
        self.INIgyroX = round((gyro['x']),3)
        self.INIgyroY = round((gyro['y']),3)
        self.INIgyroZ = round((gyro['z']),3)
    
    def modifyPositionGyro(self):
        gyro = self.readGyro()
        self.gyroX += (round((gyro['x']),3) - self.INIgyroX)
        self.gyroY += (round((gyro['y']),3) - self.INIgyroY)
        self.gyroZ += (round((gyro['z']),3) - self.INIgyroZ)
        self.printActualGyro()

    def printActualGyro(self):
        print("\n")
        print("X:",self.gyroX)
        print("Y:",self.gyroY)
        print("Z:",self.gyroZ)
        print("\n")

    def readSensores(self):
        sensores = dict()
        accel = self.readAccel()
        gyro = self.readGyro()   
        mag = self.readMagnet()
        
        sensores["gyro"] = gyro
        sensores["accel"] = accel
        sensores["mag"] = mag

        return sensores

    def readSensoresConCalibracion(self):
        sensores = dict()
        accel = self.readAccel()
        gyro = self.readGyro()   
        mag = self.readMagnet()
        
        gyro['x']-=self.INIgyroX
        gyro['y']-=self.INIgyroY
        gyro['z']-=self.INIgyroZ

        sensores["gyro"] = gyro
        sensores["accel"] = accel
        sensores["mag"] = mag

        return sensores

    def get_FIFO_count(self):
        data = [0] * 2
        data = self.read_bytes(data, C.MPU6050_RA_FIFO_COUNTH, 2)
        return (data[0] << 8) | data[1]

    def calibrarGyro(self):

        input("Ponme sobre una superficie plana y presione Enter")

        a_roll = 0
        a_pitch = 0
        a_yaw = 0


        old_roll_pitch_yaw = None
        salir = 0
        firstTime = True
        while salir != 3:
            roll_pitch_yaw = self.readSensoresConCalibracion()

            if (firstTime != True):
                diffx = math.fabs(old_roll_pitch_yaw.x - roll_pitch_yaw.x) 
                diffy = math.fabs(old_roll_pitch_yaw.y - roll_pitch_yaw.y) 
                diffz = math.fabs(old_roll_pitch_yaw.z - roll_pitch_yaw.z) 
                print(diffx)
                print(diffy)
                print(diffz)
                salir = 0
                if diffx < 0.2:
                    salir += 1
                if diffy < 0.2:
                    salir += 1
                if diffz < 0.2:
                    salir += 1
            
            old_roll_pitch_yaw = roll_pitch_yaw
            firstTime = False
            time.sleep(1)

        self.x_gyro_offset = roll_pitch_yaw.x
        self.y_gyro_offset = roll_pitch_yaw.y
        self.z_gyro_offset = roll_pitch_yaw.z

        print("Offset establecido en:\n X=", self.x_gyro_offset, "Y=", self.y_gyro_offset, "Z=", self.z_gyro_offset)
        time.sleep(1)
        return {'x':self.x_gyro_offset,'y':self.y_gyro_offset,'z':self.z_gyro_offset}

    def setGyroOffset(self,x,y,z):
        self.x_gyro_offset = x
        self.y_gyro_offset = y
        self.z_gyro_offset = z

    def readSensoresConCalibracion(self):

        while (True):
            FIFO_count = self.get_FIFO_count()
            mpu_int_status = self.get_int_status()
            packet_size = self.DMP_get_FIFO_packet_size()
            FIFO_buffer = [0]*64

            # If overflow is detected by status or fifo count we want to reset
            if (FIFO_count == 1024) or (mpu_int_status & 0x10):
                self.reset_FIFO()
                # print('overflow!')
            # Check if fifo data is ready
            elif (mpu_int_status & 0x02):
                # Wait until packet_size number of bytes are ready for reading, default
                # is 42 bytes
                FIFO_count = self.get_FIFO_count()
                while FIFO_count < packet_size:
                    FIFO_count = self.get_FIFO_count()
                FIFO_buffer = self.get_FIFO_bytes(packet_size)
                accel = self.DMP_get_acceleration_int16(FIFO_buffer)
                quat = self.DMP_get_quaternion_int16(FIFO_buffer)
                grav = self.DMP_get_gravity(quat)
                roll_pitch_yaw = self.DMP_get_euler_roll_pitch_yaw(quat, grav)
                roll_pitch_yaw.x -= self.x_gyro_offset
                roll_pitch_yaw.y -= self.y_gyro_offset
                roll_pitch_yaw.z -= self.z_gyro_offset
                return roll_pitch_yaw

    def get_int_status(self):
        return self.__bus.read_byte_data(self.__dev_id,
                                         C.MPU6050_RA_INT_STATUS)


    def DMP_get_FIFO_packet_size(self):
        return self.__DMP_packet_size #= 42


if __name__ == "__main__":
    gyroscopioBruteData = MPU9250()

    while True:
        # print(gyroscopioBruteData.readMagnet())
        # print(gyroscopioBruteData.readGyro())
        print(gyroscopioBruteData.readMagnet())
        print()
        time.sleep(1)

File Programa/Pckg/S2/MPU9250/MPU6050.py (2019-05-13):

__author__ = 'Geir Istad'
"""
MPU6050 Python I2C Class
Copyright (c) 2015 Geir Istad

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

Code based on
I2Cdev library collection - MPU6050 I2C device class
by Jeff Rowberg <jeff@rowberg.net>
============================================
I2Cdev device library code is placed under the MIT license
Copyright (c) 2012 Jeff Rowberg
Permission is hereby granted, free of charge, to any person obtaining a copy
of this software and associated documentation files (the "Software"), to deal
in the Software without restriction, including without limitation the rights
to use, copy, modify, merge, publish, distribute, sublicense, and/or sell
copies of the Software, and to permit persons to whom the Software is
furnished to do so, subject to the following conditions:
The above copyright notice and this permission notice shall be included in
all copies or substantial portions of the Software.
THE SOFTWARE IS PROVIDED "AS IS", WITHOUT WARRANTY OF ANY KIND, EXPRESS OR
IMPLIED, INCLUDING BUT NOT LIMITED TO THE WARRANTIES OF MERCHANTABILITY,
FITNESS FOR A PARTICULAR PURPOSE AND NONINFRINGEMENT. IN NO EVENT SHALL THE
AUTHORS OR COPYRIGHT HOLDERS BE LIABLE FOR ANY CLAIM, DAMAGES OR OTHER
LIABILITY, WHETHER IN AN ACTION OF CONTRACT, TORT OR OTHERWISE, ARISING FROM,
OUT OF OR IN CONNECTION WITH THE SOFTWARE OR THE USE OR OTHER DEALINGS IN
THE SOFTWARE.
===============================================
"""

import math
import ctypes
import time
import smbus
import csv
from Pckg.S2.MPU9250.MPUConstants import MPUConstants as C
from Pckg.S2.MPU9250.Quaternion import Quaternion as Q
from Pckg.S2.MPU9250.Quaternion import XYZVector as V
# from MPUConstants import MPUConstants as C
# from Quaternion import Quaternion as Q
# from Quaternion import XYZVector as V


## MPU9250 Default I2C slave address
SLAVE_ADDRESS        = 0x68
## AK8963 I2C slave address
AK8963_SLAVE_ADDRESS = 0x0C
## Device id
DEVICE_ID            = 0x71

''' MPU-9250 Register Addresses '''
## sample rate driver
SMPLRT_DIV     = 0x19
CONFIG         = 0x1A
GYRO_CONFIG    = 0x1B
ACCEL_CONFIG   = 0x1C
ACCEL_CONFIG_2 = 0x1D
LP_ACCEL_ODR   = 0x1E
WOM_THR        = 0x1F
FIFO_EN        = 0x23
I2C_MST_CTRL   = 0x24
I2C_MST_STATUS = 0x36
INT_PIN_CFG    = 0x37
INT_ENABLE     = 0x38
INT_STATUS     = 0x3A
ACCEL_OUT      = 0x3B
TEMP_OUT       = 0x41
GYRO_OUT       = 0x43

I2C_MST_DELAY_CTRL = 0x67
SIGNAL_PATH_RESET  = 0x68
MOT_DETECT_CTRL    = 0x69
USER_CTRL          = 0x6A
PWR_MGMT_1         = 0x6B
PWR_MGMT_2         = 0x6C
FIFO_R_W           = 0x74
WHO_AM_I           = 0x75

## Gyro Full Scale Select 250dps
GFS_250  = 0x00
## Gyro Full Scale Select 500dps
GFS_500  = 0x01
## Gyro Full Scale Select 1000dps
GFS_1000 = 0x02
## Gyro Full Scale Select 2000dps
GFS_2000 = 0x03
## Accel Full Scale Select 2G
AFS_2G   = 0x00
## Accel Full Scale Select 4G
AFS_4G   = 0x01
## Accel Full Scale Select 8G
AFS_8G   = 0x02
## Accel Full Scale Select 16G
AFS_16G  = 0x03

# AK8963 Register Addresses
AK8963_ST1        = 0x02
AK8963_MAGNET_OUT = 0x03
AK8963_CNTL1      = 0x0A
AK8963_CNTL2      = 0x0B
AK8963_ASAX       = 0x10

# CNTL1 Mode select
## Power down mode
AK8963_MODE_DOWN   = 0x00
## One shot data output
AK8963_MODE_ONE    = 0x01

## Continous data output 8Hz
AK8963_MODE_C8HZ   = 0x02
## Continous data output 100Hz
AK8963_MODE_C100HZ = 0x06

# Magneto Scale Select
## 14bit output
AK8963_BIT_14 = 0x00
## 16bit output
AK8963_BIT_16 = 0x01


class MPU6050:
    __buffer = [0] * 14
    __debug = False
    __DMP_packet_size = 0
    __dev_id = 0
    __bus = None

    x_gyro_offset = 0
    y_gyro_offset = 0
    z_gyro_offset = 0

    mres = 0
    magXcoef = 0
    magYcoef = 0
    magZcoef = 0

    address=0x68

    def __init__(self, a_bus=1, a_address=C.MPU6050_DEFAULT_ADDRESS,
                 a_xAOff=None, a_yAOff=None, a_zAOff=None, a_xGOff=None,
                 a_yGOff=None, a_zGOff=None, a_debug=False):
        self.__dev_id = a_address
        # Connect to num 1 SMBus
        self.__bus = smbus.SMBus(a_bus)
        # Set clock source to gyro
        self.set_clock_source(C.MPU6050_CLOCK_PLL_XGYRO)
        # # Set accelerometer range
        self.set_full_scale_accel_range(C.MPU6050_ACCEL_FS_4)
        # # Set gyro range
        self.set_full_scale_gyro_range(C.MPU6050_GYRO_FS_250)
        # # Take the MPU out of time.sleep mode
        self.wake_up()

        self.gres = 250.0/32768.0
        self.ares = 2.0/32768.0

        self.dmp_initialize()
        self.set_DMP_enabled(True)

        # self.configMPU9250(GFS_250, AFS_2G)
        # self.configAK8963(AK8963_MODE_C8HZ, AK8963_BIT_16)


        # Set offsets
        # if a_xAOff:
        #     self.set_x_accel_offset(a_xAOff)
        # if a_yAOff:
        #     self.set_y_accel_offset(a_yAOff)
        # if a_zAOff:
        #     self.set_z_accel_offset(a_zAOff)
        # if a_xGOff:
        #     self.set_x_gyro_offset(a_xGOff)
        # if a_yGOff:
        #     self.set_y_gyro_offset(a_yGOff)
        # if a_zGOff:
        #     self.set_z_gyro_offset(a_zGOff)
        self.__debug = a_debug

    ## Configure AK8963
    #  @param [in] self The object pointer.
    #  @param [in] mode Magneto Mode Select(default:AK8963_MODE_C8HZ[Continous 8Hz])
    #  @param [in] mfs Magneto Scale Select(default:AK8963_BIT_16[16bit])
    def configAK8963(self, mode, mfs):
        if mfs == AK8963_BIT_14:
            self.mres = 4912.0/8190.0
        else: #  mfs == AK8963_BIT_16:
            self.mres = 4912.0/32760.0

        self.__bus.write_byte_data(AK8963_SLAVE_ADDRESS, AK8963_CNTL1, 0x00)
        time.sleep(0.01)

        # set read FuseROM mode
        self.__bus.write_byte_data(AK8963_SLAVE_ADDRESS, AK8963_CNTL1, 0x0F)
        time.sleep(0.01)

        # read coef data
        data = self.__bus.read_i2c_block_data(AK8963_SLAVE_ADDRESS, AK8963_ASAX, 3)

        self.magXcoef = (data[0] - 128) / 256.0 + 1.0
        self.magYcoef = (data[1] - 128) / 256.0 + 1.0
        self.magZcoef = (data[2] - 128) / 256.0 + 1.0

        # set power down mode
        self.__bus.write_byte_data(AK8963_SLAVE_ADDRESS, AK8963_CNTL1, 0x00)
        time.sleep(0.01)

        # set scale&continous mode
        self.__bus.write_byte_data(AK8963_SLAVE_ADDRESS, AK8963_CNTL1, (mfs<<4|mode))
        time.sleep(0.01)

    # Core bit and byte operations
    def read_bit(self, a_reg_add, a_bit_position):
        return self.read_bits(a_reg_add, a_bit_position, 1)

    def write_bit(self, a_reg_add, a_bit_num, a_bit):
        byte = self.__bus.read_byte_data(self.__dev_id, a_reg_add)
        if a_bit:
            byte |= 1 << a_bit_num
        else:
            byte &= ~(1 << a_bit_num)
        self.__bus.write_byte_data(
            self.__dev_id, a_reg_add, ctypes.c_int8(byte).value)
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

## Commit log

2019-04-23 Create
    Creacion de repositorio con los datos de mi TFG
    [Calculos Viento.xlsx, ListaCompraTFG.xlsx, MuestraDeViento01.xlsx]
2019-04-23 Modelos3D
    Modelos3D
    [+.stl, AccuChamber.3mf, ChasisInferiorDron_ConParedes_P0.ipt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]
2019-05-07 AutoIndent de pycharm. Excepcion para medir hasta para con CtrlC
2019-05-27 updateMain - menu de main actualizado
2019-05-31 MU - Motores
2019-05-31 MU - ESC
2019-06-03 MU - Tope Power
2019-06-04 MU - Sensor de viento, plots e imagenes
    [mausahSinChupi.stl]
2019-06-05 MU - Clean directory y sensordevientoendron
2019-06-05 MU - Correcciones hasta controladora, y nuevos plots de medicion de viento
2019-06-13 MU - Resultados y media conclusión
    [MuestraDeViento01(Recuperado automáticamente).xlsx, MuestraDeViento01.xlsx]
2019-06-24 FIN - TFG
    Falta PPT para presentación
